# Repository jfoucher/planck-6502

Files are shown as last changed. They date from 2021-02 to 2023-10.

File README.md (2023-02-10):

# Planck computer

# An open hardware, extensible 65c02 based computer

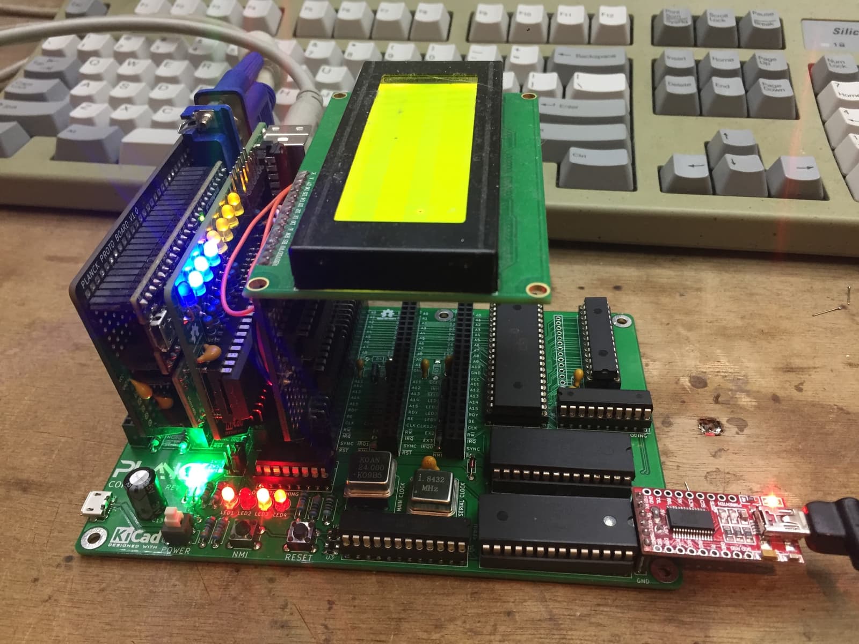
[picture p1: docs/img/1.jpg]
General view


This is a hobby computer based on the 65C02 processor. (I use 6502 and 65C02 interchangeably in this document, but [there are some differences](http://wilsonminesco.com/NMOS-CMOSdif/))

There are already many computers based on the 6502 processor, old ones such as as the Apple 1, Apple II, Commodore 64 and many more; and many more recent ones, from homebrew affairs on prototype board, to complete replicas of old systems.

The one that most closely resembles the Planck is probably the RC6502, itself based on the RC2014 (which uses a Z80 processor) with adaptations to the expansion bus to make it fit the 6502 processor.

Planck is a new variant on this type of expandable machines with a different set of tradeoffs.

### Contraints and requirements

The constraints for it's design were the following:

  - Minimum board size, 2 layers, as that is what is cheapest to have fabricated.
  - Easily extensible with for example:
    - Serial port
    - Parallel port
    - SPI / SPI65B port
    - PS/2 port for keyboard
    - Sound card
    - VGA out
    - SD card
    - LCD screen
  - Target clock speed of 10 to 12 MHz

## Some details

These requirements resulted in a computer based on a [motherboard](/Hardware/mainboard) hosting RAM, ROM and CPU and extension slots for expansion cards to plug into.

The [Planck hardware pages](/Hardware) explains more about the functionality of the motherboard and of each basic extension boards.

Of course, you can [design your own expansion boards](/Hardware/make) to make the computer do whatever **you** decide

### Expansion

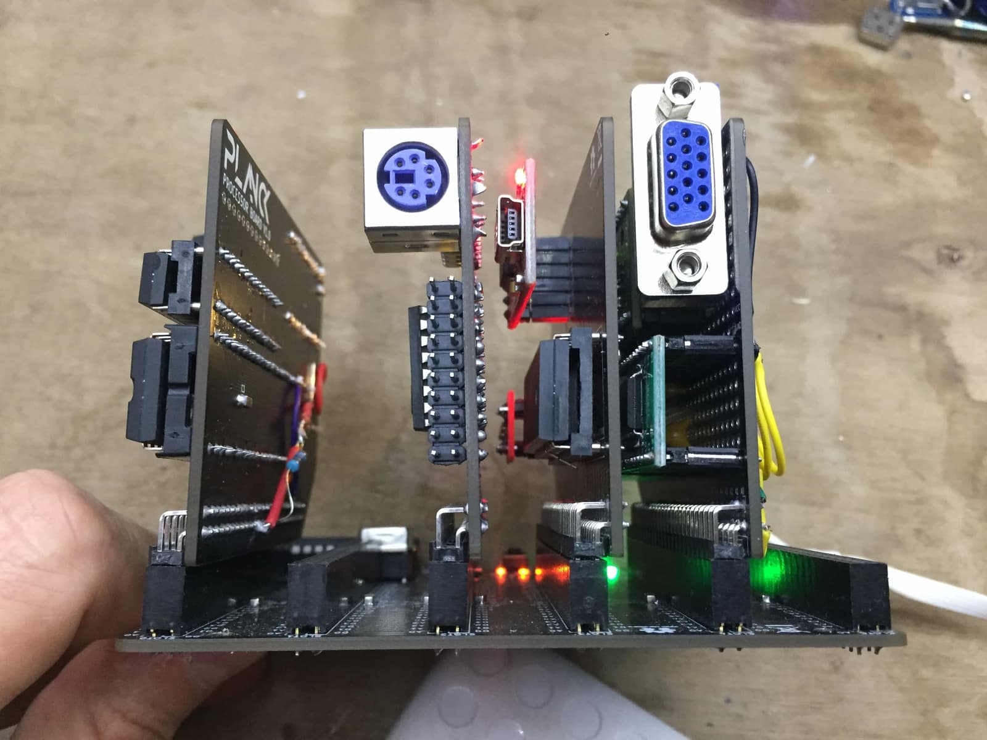
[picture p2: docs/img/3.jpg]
Expansion ports


Each expansion slot has a signal that should cause it to activate (<span style="text-decoration:overline">SEL1</span> to <span style="text-decoration:overline">SEL5</span> as detailed in the expansion bus description). The signals are generated by a programable logic chip on the motherboard (ATF22V10 or equivalent) according to the address that the processor is currently trying to access.

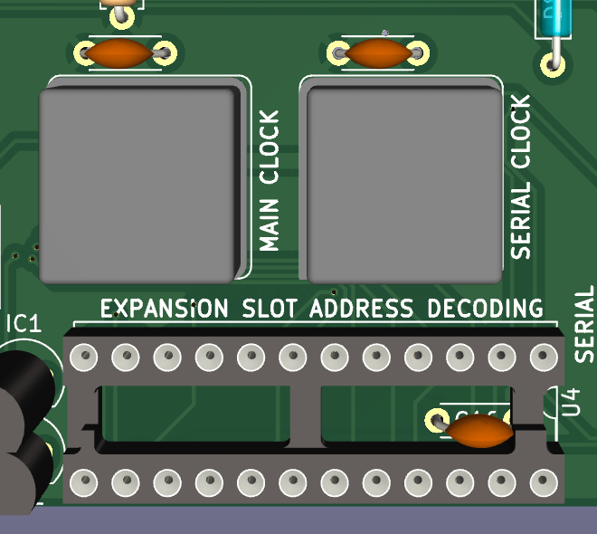
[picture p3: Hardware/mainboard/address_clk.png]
address decoding and clock


The main computer clock is generated on the motherboard by an oscillator. The clock signal goes through a binary counter, which makes it possible to slow down the clock when accessing slow devices.

The expansion slots are common 2x25 "Dupont" sockets on 2.54mm (100mil) centers and are very easy to obtain.

#### Expansion bus pinout

Most pins correspond to the pins of the same name on the CPU.

Below are the pins that are specific to the expansion bus:

| Pin number | Pin name | Description |
|----- |-----|---|
| 1 | A0 | Processor address bus pin 0 |
| 2 | D0 | Processor data bus pin 0 |
| 3 | A1 | Processor address bus pin 1 |
| 4 | D1 | Processor data bus pin 1 |
| 5 | A2 | Processor address bus pin 2 |
| 6 | D2 | Processor data bus pin 2 |
| 7 | A3 | Processor address bus pin 3 |
| 8 | D3 | Processor data bus pin 3 |
| 9 | A4 | Processor address bus pin 4 |
| 10 | D4 | Processor data bus pin 4 |
| 11 | A5 | Processor address bus pin 5 |
| 12 | D5 | Processor data bus pin 5 |
| 13 | A6 | Processor address bus pin 6 |
| 14 | D6 | Processor data bus pin 6 |
| 15 | A7 | Processor address bus pin 7 |
| 16 | D7 | Processor data bus pin 7 |
| 17 | A8 | Processor address bus pin 8 |
| 18 | EX0 | Extra pin for future use or for communication between expansion cards |
| 19 | A9 | Processor address bus pin 9 |
| 20 | EX1 | Extra pin for future use or for communication between expansion cards |
| 21 | A10 | Processor address bus pin 10 |
| 22 | <span style="text-decoration:overline">SLOW</span> | Used by slow peripherals to request a slower clock speed, active low. |
| 23 | GND | Ground |
| 24 | +5V | Positive voltage |
| 25 | +5V | Positive voltage |
| 26 | GND | Ground |
| 27 | A11 | Processor address bus pin 11 |
| 28 | <span style="text-decoration:overline">SSEL</span> | An expansion card is selected. Used by the processor card to disable it's built-in ram an ROM, active low |
| 29 | A12 | Processor address bus pin 12 |
| 30 | <span style="text-decoration:overline">INH</span> | When this is active (low), processor card RAM and ROM are disabled |
| 31 | A13 | Processor address bus pin 13 |
| 32 | <span style="text-decoration:overline">SLOT_SEL</span> | Used by the backplane to signal to expansion cards when they should activate, active low |
| 33 | A14 | Processor address bus pin 14 |
| 34 | LED1 | Connected to one of the backplane LEDs |
| 35 | A15 | Processor address bus pin 15 |
| 36 | LED2 | Connected to one of the backplane LEDs |
| 37 | RDY | Processor I/O pin. When low, the processor waits in it's curent state |
| 38 | LED3 | Connected to one of the backplane LEDs |
| 39 | BE | Processor input pin. when low the processor releases the bus |
| 40 | LED4 | Connected to one of the backplane LEDs |
| 41 | CLK | Main computer clock. Can be stretched or not depending on the state of the SLOW signal. |
| 42 | CLK_12M | Stable clock for e.g. VIA timers. **Not connected to slot 0** |
| 43 | R<span style="text-decoration:overline">W</span> | CPU read / write pin |
| 44 | EX4 | Extra signal 4. **Not connected to slot 0** |
| 45 | <span style="text-decoration:overline">IRQ</span> | This goes low when an interrupt request has occured, active low |
| 46 | EX5 | Extra signal 5. **Not connected to slot 0** |
| 47 | SYNC | CPU output. Indicates when the CPU is fetching an opcode |
| 48 | <span style="text-decoration:overline">SLOT_IRQ</span> | Used by expansion cards to signal an interrupt request to the processor board, active low  |
| 49 | <span style="text-decoration:overline">RESET</span> | Reset signal trigered by the button on the backplane, active low |
| 50 | <span style="text-decoration:overline">NMI</span> | non maskable interrupt signal trigered by the button on the backplane, active low |

The Planck 6502 computer is a single board computer that communicates over serial, or can be a standalone computer by adding expansion cards to one of the 6 slots present on the motherboard.

### Input / output
Also present on the motherboard are two buttons and 4 LEDs.

One button triggers a reset of the processor, and the other triggers an non-maskable interrupt (<span style="text-decoration:overline">NMI</span>) which can be thought of as a "soft" reset.

The leds are connected to the expansion bus, and so any board can control them. They can be used as a crude debug tool, to show the status of some processing, to try out a simple blink routine or to signal an error to the user.

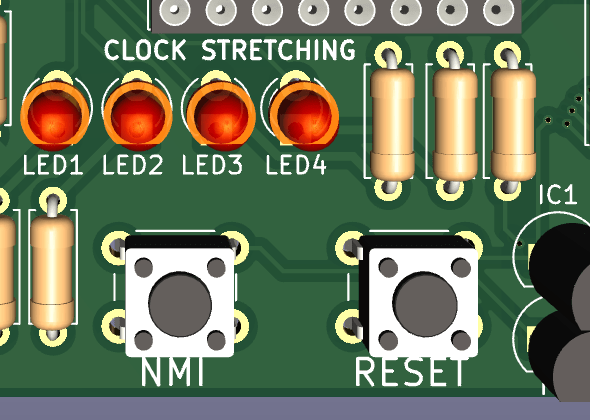
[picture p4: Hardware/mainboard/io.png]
input output


### Power delivery

The power to the board is provided by a barrel jack at the bottom left. There is a linear regulator on the board, so the power supply voltage can be anywhere from 7V to 12V, although with the latter a heatsink may be required on the regulator.

A power switch and a power LED are also provided on the backplane.

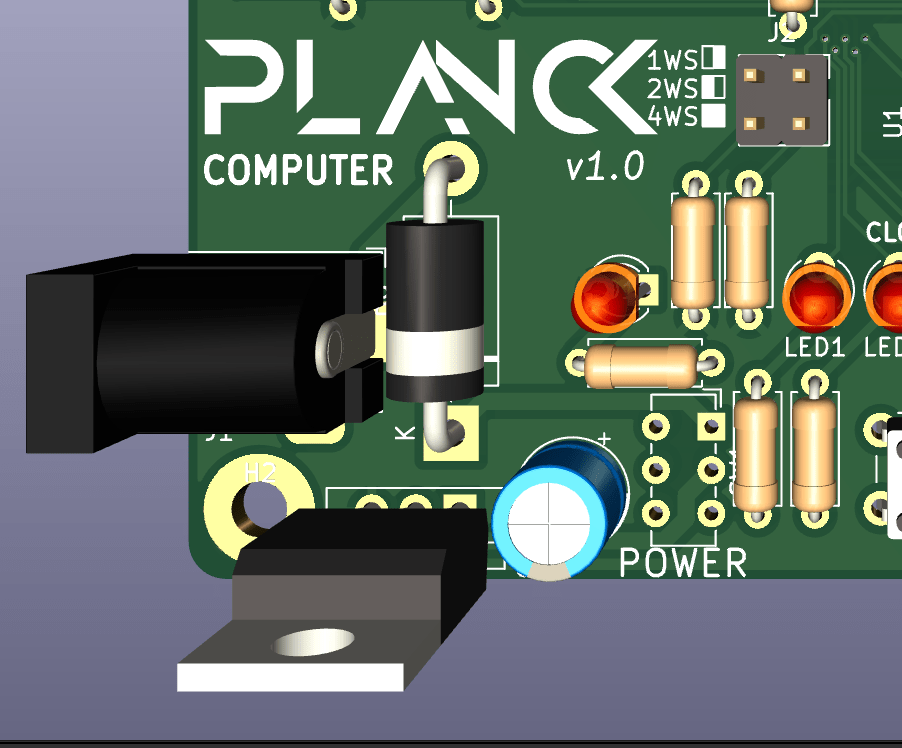
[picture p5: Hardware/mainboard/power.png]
Power


## Available expansion boards

### I/O board

[The IO board](Hardware/io_board) is based on a WDC65C22 chip and provides a keyboard PS/2 port, a parallel port and a 65SIB port (serial port similar to and compatible with SPI)

### Serial board

[The serial board](Hardware/serial_board) is based on a WDC65C51 chip and provides serial output through a TTL serial to USB adapter. When plugging the USB cable to your PC, it may be best to unplug the power from the backplane and let the computer be powered from your PC through the USB to serial adapter.

### OPL2 board

[A sound card](Hardware/opl2_board) based on the Yamaha OPL2 chip found in the original sound blaster card for example.

### LCD board

[This board](Hardware/lcd_board) allow a 20x04 LCD to be connected to the computer for text output.

<br />This documentation is licensed under a <a rel="license" href="http://creativecommons.org/licenses/by-sa/4.0/">Creative Commons Attribution-ShareAlike 4.0 International License</a>.

CERN-OHL-1.2 GPL-3.0-or-later CC-BY-SA-4.0

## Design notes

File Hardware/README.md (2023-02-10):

## Hardware

In this folder you will find all the schematics and board layouts in [Kicad](https://www.kicad.org/) format.

You probably want to take a look at the [main board](mainboard/) first as that explains the basic architecture of the computer.

<br />This documentation is licensed under a <a rel="license" href="http://creativecommons.org/licenses/by-sa/4.0/">Creative Commons Attribution-ShareAlike 4.0 International License</a>.

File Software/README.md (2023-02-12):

## Planck 6502 software

This folder contains the software for the Planck computer.
The `drivers`folder contains assembly drivers for the hardware.

The `fos` folder contains a modified version of [TaliForth 2](https://github.com/scotws/TaliForth2) with a platorm file made for the planck. I ported TaliForth code to [CA65](https://cc65.github.io/doc/ca65.html) because I find it more flexible.

Finally the PAL directory contains Wincupl code to program the programmable logic chips on the backplane and on the processor board.

<br />This documentation is licensed under a <a rel="license" href="http://creativecommons.org/licenses/by-sa/4.0/">Creative Commons Attribution-ShareAlike 4.0 International License</a>.

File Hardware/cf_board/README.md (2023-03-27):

## Compact Flash board

This board allows adding one Compact Flash (CF) card to the Planck computer. This gives mass storage capabilities to the computer.

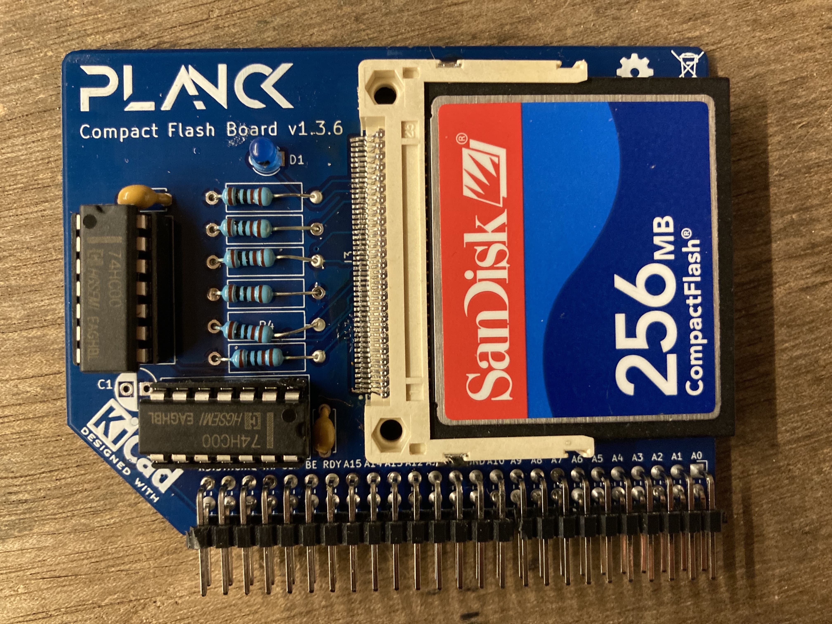
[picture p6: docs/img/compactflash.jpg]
Top view of the CompactFlash board


The file system is not complete yet, but will probably be FAT16 to allow interoperability with PCs

You will be able to save and load files. 

It will be possible to load forth words and assembly code from the compact flash card.

3D render

You can [download the schematic](https://planck6502.com/fabrication/cf_board-schematic.pdf) and the [gerber files](https://planck6502.com/fabrication/cf_board-zip.zip)

[Documentation](https://planck6502.com/Hardware/cf/)

<br />This documentation is licensed under a <a rel="license" href="http://creativecommons.org/licenses/by-sa/4.0/">Creative Commons Attribution-ShareAlike 4.0 International License</a>.

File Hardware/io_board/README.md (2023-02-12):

## Keyboard and IO board

This board is based on a 6522 chip.

### Features

- One PS/2 keyboard port
- One SPI port
- One parallel port

### Details

PORTA as well as CA1 and CA2 are brought out to a pin header on top of the board.

The PS/2 port uses CB2 for the clock and PORTB bit 7 as the data line.

There is also a modified [65SIB port](http://forum.6502.org/viewtopic.php?t=1064&start=105) on the back. The +12V have been replaced by +5V lines because there is not 12V on the board. Similary the -12V line is left unconnected.

This port allows 7 SPI devices to be connected to the IO board and uses PORTB pins PB0 to PB2 to select one of 7 devices (through a 74HC137)
PB3 is the SPI clock, PB4 is MISO, PB5 is MOSI, PB6 is the <span style="text-decoration:overline">CONF</span> signal and PB7 is used to latch the selected device into the 74HC137. The latching allows for pins PB0 to PB2 to do other things while an SPI device is being accessed at the cost of having to be careful not to make it interfere with the ps/2 keyboard.

This is what the board look like at the moment:

Top view

3D render

You can [download the schematic](https://planck6502.com/fabrication/io_board-schematic.pdf) and the [gerber files](https://planck6502.com/fabrication/io_board-zip.zip)

[Documentation](https://planck6502.com/Hardware/io/)

<br />This documentation is licensed under a <a rel="license" href="http://creativecommons.org/licenses/by-sa/4.0/">Creative Commons Attribution-ShareAlike 4.0 International License</a>.

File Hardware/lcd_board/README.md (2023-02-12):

## Planck 6502 LCD board

This board allows adding a HD44780 based LCD to the Planck computer.

This is what the board looks like at the moment:

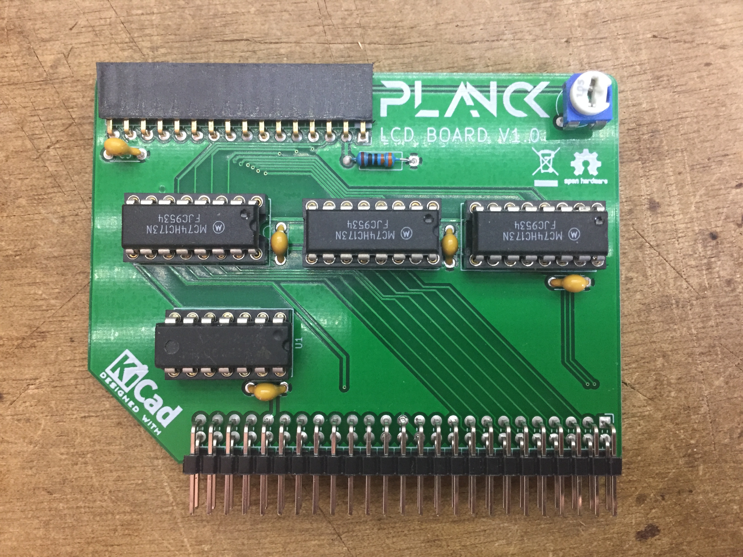
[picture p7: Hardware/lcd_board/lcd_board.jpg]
Final board


3D render

You can [download the schematic](https://planck6502.com/fabrication/lcd_board-schematic.pdf) and the [gerber files](https://planck6502.com/fabrication/lcd_board-zip.zip)

[Documentation](https://planck6502.com/Hardware/lcd/)

<br />This documentation is licensed under a <a rel="license" href="http://creativecommons.org/licenses/by-sa/4.0/">Creative Commons Attribution-ShareAlike 4.0 International License</a>.

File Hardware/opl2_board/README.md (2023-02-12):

## Planck 6502 sound card

This is a sound card based on the YM3892 OPL2 sound chip.

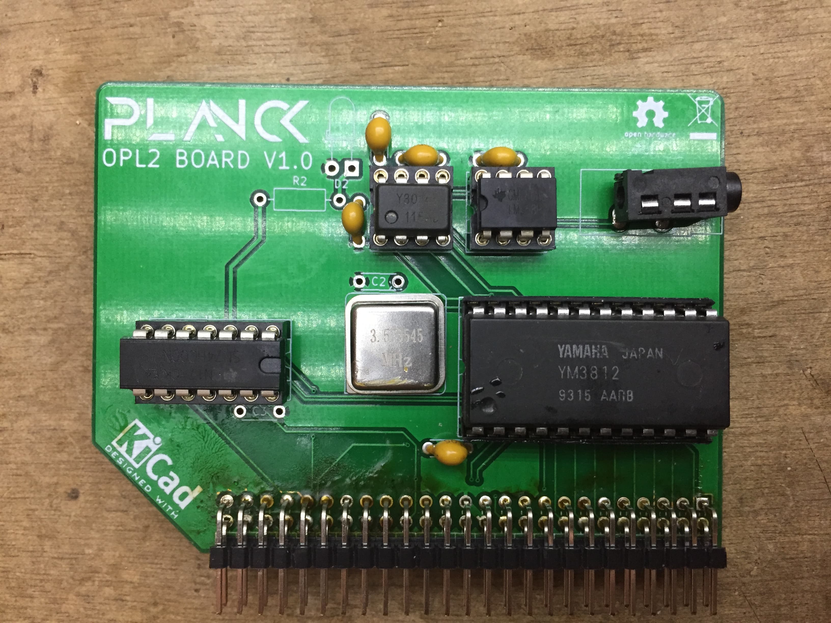
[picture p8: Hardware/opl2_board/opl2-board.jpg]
OPL2 board


3D render

You can [download the schematic](https://planck6502.com/fabrication/opl2_board-schematic.pdf) and the [gerber files](https://planck6502.com/fabrication/opl2_board-zip.zip)

[Documentation](https://planck6502.com/Hardware/opl2/)

<br />This documentation is licensed under a <a rel="license" href="http://creativecommons.org/licenses/by-sa/4.0/">Creative Commons Attribution-ShareAlike 4.0 International License</a>.

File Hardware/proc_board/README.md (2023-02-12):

## Planck CPU board

# Deprecated. Please use the [mainboard](../mainboard/) instead

This is the CPU board for the Planck 6502 based computer. It contains 32K of ram and 32K of rom.

The RAM and ROM can be inhibited by setting the <span style="text-decoration:overline">INH</span> signal low.

It is then the responsibility of that card to respond to the whole address range (execpt the one where expansion cards are active) to provide required functionality such as reset vectors, zero page, etc...

If the <span style="text-decoration:overline">SSEL</span> signal is low (one of the slots is active), both the RAM and the ROM will be offline.

The board can accept either a narrow or wide DIP28 RAM chip.

This is what the board looks like

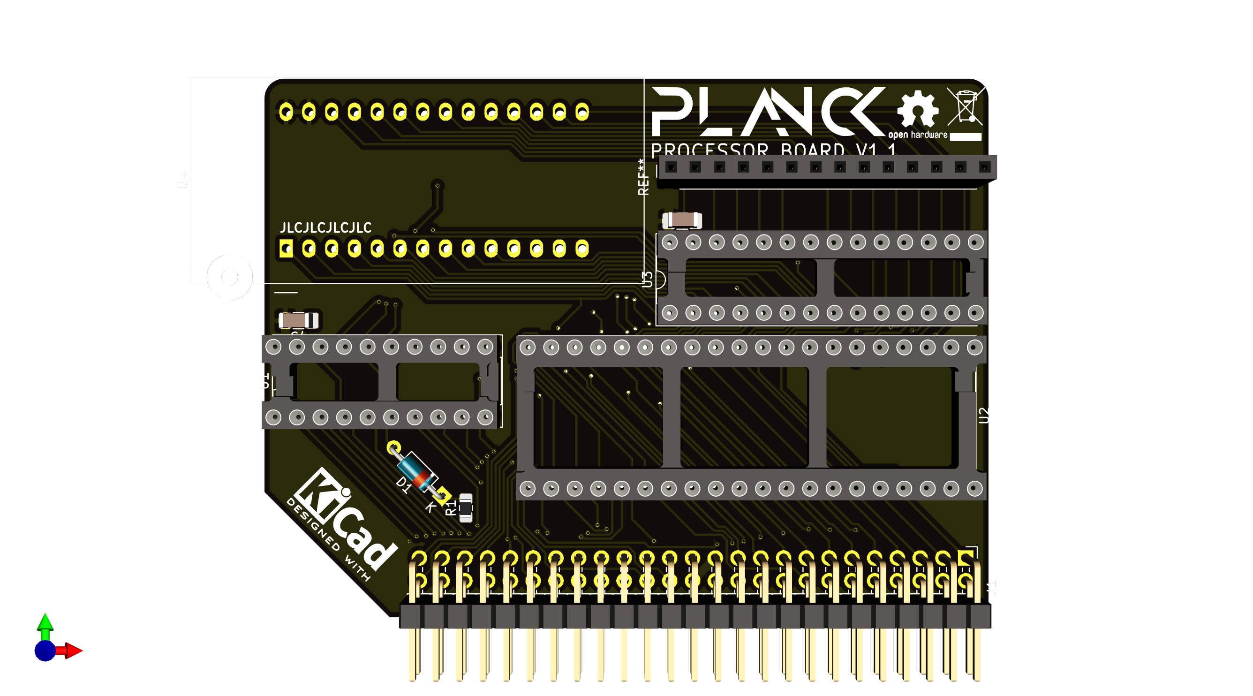
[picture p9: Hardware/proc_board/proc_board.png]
CPU board 3D view


<br />This documentation is licensed under a <a rel="license" href="http://creativecommons.org/licenses/by-sa/4.0/">Creative Commons Attribution-ShareAlike 4.0 International License</a>.

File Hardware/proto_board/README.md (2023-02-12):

## Planck 6502 expansion board prototype

This board allows you to prototype any thing for the Planck computer

This is what the board looks like at the moment

3D render

You can [download the schematic](https://planck6502.com/fabrication/proto_board-schematic.pdf) and the [gerber files](https://planck6502.com/fabrication/proto_board-zip.zip)

[Documentation](https://planck6502.com/Hardware/proto/)

<br />This documentation is licensed under a <a rel="license" href="http://creativecommons.org/licenses/by-sa/4.0/">Creative Commons Attribution-ShareAlike 4.0 International License</a>.

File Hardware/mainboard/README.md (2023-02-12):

## Planck computer

This is a complete computer based on the Planck 6502 backplane.

It provides a 65c02 cPU, 32k of RAM, 32k of ROM and a serial port, as well as 6 expansion slots.

The board exceeds the original size specification of the original project (100 x 150mm instead of 100 x 100mm) but it seems that the cost will be similar (one more expensive board replaces 3 cheaper boards) as well as being more practical for some applications.

This computer can run absolutely stand alone when connected via the serial port. It can also accommodate 2 more expansion cards compared to the original backplane.

Here is a 3D view of the board:

3D render

You can [download the schematic](https://planck6502.com/fabrication/mainboard-schematic.pdf) and the [gerber files](https://planck6502.com/fabrication/mainboard-zip.zip)

[Documentation](https://planck6502.com/Hardware/io/)

<br />This documentation is licensed under a <a rel="license" href="http://creativecommons.org/licenses/by-sa/4.0/">Creative Commons Attribution-ShareAlike 4.0 International License</a>.

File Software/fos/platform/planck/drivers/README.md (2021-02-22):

## Drivers

This folder contains assembly drivers for the planck computer.
They are divided into a number of files by functionality.
Most of them require specific hardware to be present to function.

They also have predefined hardware adresses, meaning that each specific card is meant to go in a specific slot for these drivers to work.
However the base address is set in the `.inc` files, so should be very easy to change when a card is moved from one slot to another.

<br />This documentation is licensed under a <a rel="license" href="http://creativecommons.org/licenses/by-sa/4.0/">Creative Commons Attribution-ShareAlike 4.0 International License</a>.

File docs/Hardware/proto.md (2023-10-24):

---
layout: board
short_title: Proto board
title: Prototyping board
status: prod
design_files: https://gitlab.com/planck-6502/planck-6502/-/tree/main/Hardware/proto_board
order: 100
gerbers: https://planck6502.com/fabrication/proto_board-zip.zip
schematic: https://planck6502.com/fabrication/proto_board-schematic.pdf
html_bom: https://planck6502.com/fabrication/proto_board-bom.html
csv_bom: https://planck6502.com/fabrication/proto_board-bom.csv
---

This is a prototyping board. It has a header to connect it to the backplane, power delivery, and the rest is up to you!

For example here is my prototype of the [OPL2 sound card](/Hardware/opl2)

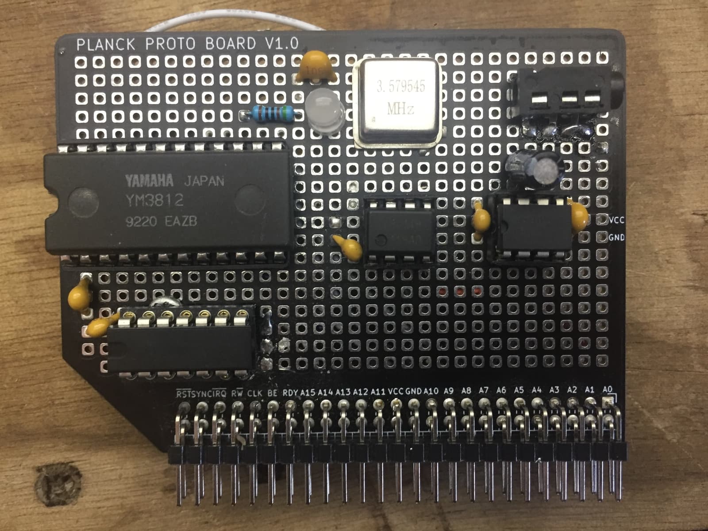
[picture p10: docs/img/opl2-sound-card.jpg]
Planck prototype board for LCD


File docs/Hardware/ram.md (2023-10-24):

---
layout: board
title: Banked RAM board
short_title: RAM board
status: dev
design_files: https://gitlab.com/planck-6502/planck-6502/-/tree/main/Hardware/ram_board
order: 60
gerbers: https://planck6502.com/fabrication/ram_board-zip.zip
schematic: https://planck6502.com/fabrication/ram_board-schematic.pdf
html_bom: https://planck6502.com/fabrication/ram_board-bom.html
csv_bom: https://planck6502.com/fabrication/ram_board-bom.csv
---

## This is a banked RAM board for the Planck 6502 computer.

3D View

When active, it gives access to a bank or RAM in the $8000-$BFFF address space.

To activate, store a byte with it's high bit set to the first register of the slot where it is placed.

For example

```nesasm
lda #$80
sta $FFD0
```

will activate bank 0

There are 32 banks. You can choose which one is active by setting the first 5 bits of the data when storing to the first register. There is no way to get the currently active bank.

When the RAM card is active, it will respond to requests in the $8000 to $BFFF range instead of the ROM

```nesasm
lda #$8E
sta $FFD0
```

will activate the 14th bank

Setting the high bit to 0 will deactivate the banked RAM

For example the following code will deactivate the banked RAM and restore the ROM :

```nesasm
lda #0
sta $FFD0
```

To use the RAM expansion from forth, two words are provided for convenience the first one `expad` sets the expansion card address.

For example, if it placed in slot 0, run the following:

```forth
hex ff80 expad
```

then to activate it and change banks, use the following:

```forth
hex
80 bank \ Activates bank 0
81 bank \ Activates bank 1
82 bank \ Activates bank 2
9F bank \ Activates bank 31

0 bank  \ Deactivates RAM expansion and restores ROM
```

## Slot placement

You can place the card in any slot, as long as your code knows where it is.

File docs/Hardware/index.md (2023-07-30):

---
layout: page
title: Planck 6502 hardware
---

The Planck hardware is organized around a motherboard that hosts the CPU and RAM, ROM and serial input / output as well as [clock generation](#clock-generation), [board connection](#board-connection), [expansion slot activation](#expansion-slot-activation) and [basic user IO](#basic-user-io).

<!--
<div style="float:right">
<form target="paypal" action="https://www.paypal.com/cgi-bin/webscr" method="post">
<input type="hidden" name="cmd" value="_s-xclick">
<input type="hidden" name="hosted_button_id" value="WNF3GUCN92CT6">
<table style="border:none"  cellpadding="0">
<tr>
<td style="border:none;vertical-align:middle">
<input type="hidden" name="on0" value="Include ICs ?">
<select name="os0">
	<option value="No ICs">No ICs €69,00 EUR</option>
	<option value="All ICs">All ICs €99,00 EUR</option>
</select>
</td>
<td style="border:none;vertical-align:middle"><input type="hidden" name="currency_code" value="EUR">
<input type="image" src="https://www.paypalobjects.com/en_US/i/btn/btn_cart_LG.gif" border="0" name="submit" alt="PayPal - The safer, easier way to pay online!">
<img alt="" border="0" src="https://www.paypalobjects.com/en_US/i/scr/pixel.gif" width="1" height="1"></td>
</tr>
</table>
</form>
</div>
-->

## The computer

[Design files](https://gitlab.com/planck-6502/planck-6502/-/tree/main/Hardware/cpu_backplane)

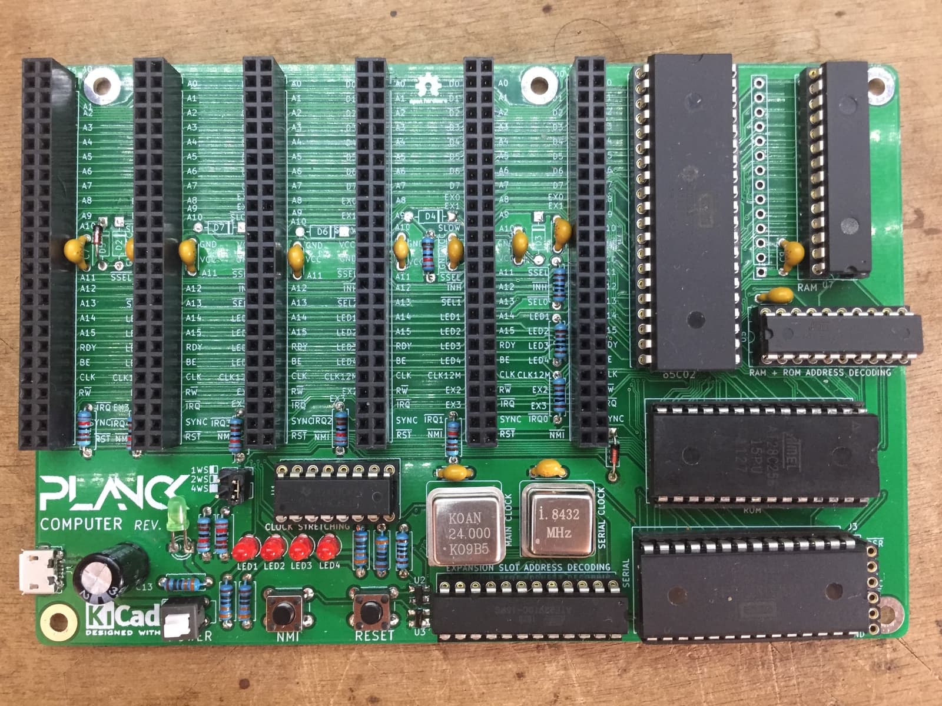
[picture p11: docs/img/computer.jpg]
Computer board fully populated


The computer board consists of a 65C02 CPU, 32K of RAM, 32K of ROM, a 6551 ACIA for serial communication, 6 expansion slots for addon boards, as well as the following:

### Clock generation

The clock generation starts with an oscillator. This oscillator should be at twice the target frequency since it is divided by two by a [74HC161 binary counter](https://assets.nexperia.com/documents/data-sheet/74HC161.pdf)

This counter makes possible the clock stretching that will be required by slow peripherals, or indeed any ROM if you run your computer fast enough.

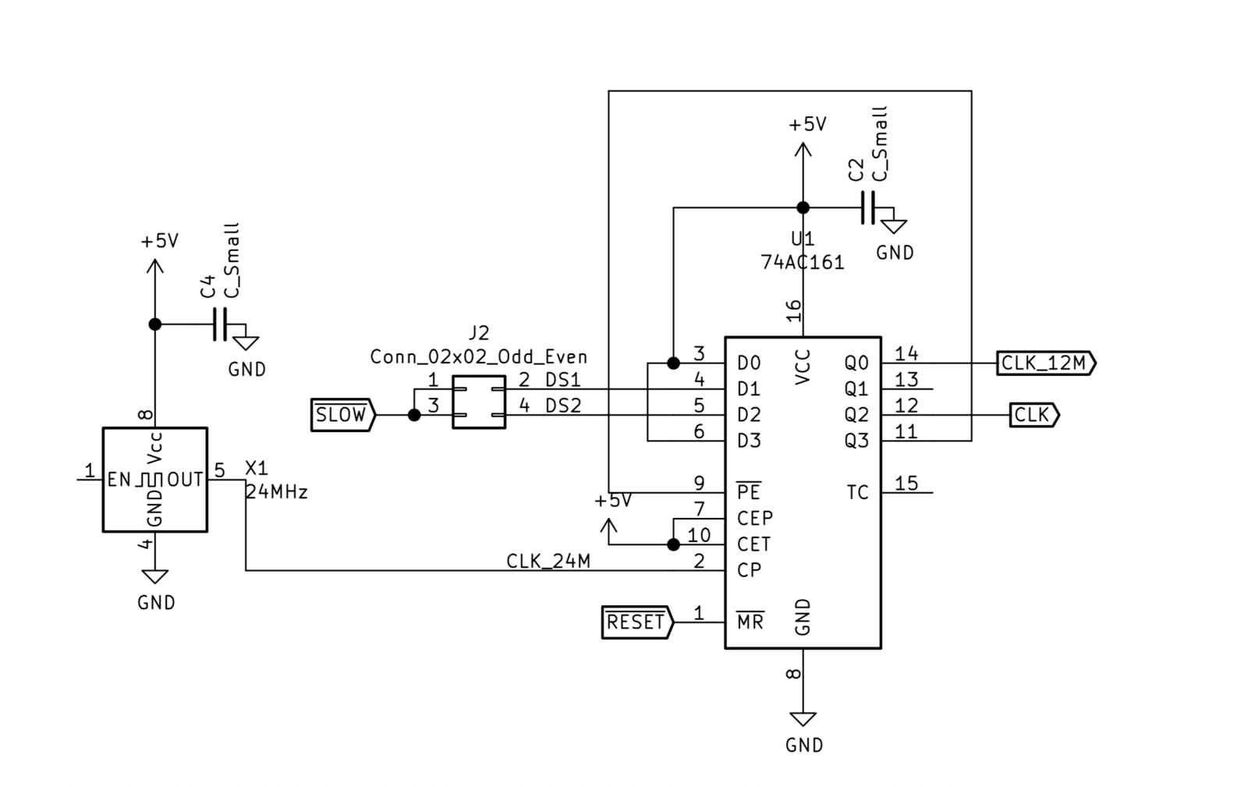
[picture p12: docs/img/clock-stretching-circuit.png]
Planck 6502 clock stretching circuit


Let me explain this schematic: 
The 24Mhz output from the oscillator goes to the clock input of the binary counter.
The Q0 output of the counter changes at every positive clock edge, so it is a square wave of half the frequency of the oscillator clock. This signal is fed to the expansion bus under the name CLK_12M. It is thus a non stretched clock that is used for things that require precise and consistent timings, such as VIA timers for example.
Q3 is low when the counter is less than 8 and causes the counter to load its current count from the input.
By default if the <span class="overline">SLOW</span> signal is high, then the counter will immediately load 15 and resume counting, which will take it back to zero, which will trigger the load again.

It that case the counter oscillates between 15 (all outputs high) and 0 (all outputs low) which causes CLK and CLK_12M to oscillate at the same frequency.

However, if the <span class="overline">SLOW</span> signal is asserted (low) than a number less than 15 will be loaded in the counter, which means the Q2 (CLK signal) will toggle at a reduced frequency.

So this simple circuit generates two clock signals : one that is slow enough for the currently addressed peripheral, and one that is stable for timing sensitive peripherals. This also means that any timing sensitive peripherals MUST be able to run at the main (CLK_12M) frequency.

### Board connection

One of the purposes of the motherboard is to connect all daughter boards together. It does this by means of an extension bus connector based on a 2.54mm 2x25 pins socket. These connectors are cheap, reliable and easy to obtain. The female connector is placed on the backplane and a right angle male connector on each expansion board.

Most pins on this extension consist of the 65C02 signals, such as 16 address lines, 8 data lines, and a smattering of control lines. The complete bus pinout is detailed below:

| Pin number | Pin name | Description |
|---|-----|---|
| 1 | A0 | Processor address bus pin 0 |
| 2 | D0 | Processor data bus pin 0 |
| 3 | A1 | Processor address bus pin 1 |
| 4 | D1 | Processor data bus pin 1 |
| 5 | A2 | Processor address bus pin 2 |
| 6 | D2 | Processor data bus pin 2 |
| 7 | A3 | Processor address bus pin 3 |
| 8 | D3 | Processor data bus pin 3 |
| 9 | A4 | Processor address bus pin 4 |
| 10 | D4 | Processor data bus pin 4 |
| 11 | A5 | Processor address bus pin 5 |
| 12 | D5 | Processor data bus pin 5 |
| 13 | A6 | Processor address bus pin 6 |
| 14 | D6 | Processor data bus pin 6 |
| 15 | A7 | Processor address bus pin 7 |
| 16 | D7 | Processor data bus pin 7 |
| 17 | A8 | Processor address bus pin 8 |
| 18 | EX0 | Extra pin for future use or for communication between expansion cards |
| 19 | A9 | Processor address bus pin 9 |
| 20 | EX1 | Extra pin for future use or for communication between expansion cards |
| 21 | A10 | Processor address bus pin 10 |
| 22 | <span class="overline">SLOW</span> | Used by slow peripherals to request a slower clock speed, active low. |
| 23 | GND | Ground |
| 24 | +5V | Positive voltage |
| 25 | +5V | Positive voltage |
| 26 | GND | Ground |
| 27 | A11 | Processor address bus pin 11 |
| 28 | <span class="overline">SSEL</span> | An expansion card is selected. Used by the processor card to disable it's built-in ram and ROM, active low |
| 29 | A12 | Processor address bus pin 12 |
| 30 | <span class="overline">INH</span> | When this is active (low), processor card RAM and ROM are disabled |
| 31 | A13 | Processor address bus pin 13 |
| 32 | <span class="overline">SLOT_SEL</span> | Used by the backplane to signal to expansion cards when they should activate, active low |
| 33 | A14 | Processor address bus pin 14 |
| 34 | LED1 | Connected to one of the backplane LEDs |
| 35 | A15 | Processor address bus pin 15 |
| 36 | LED2 | Connected to one of the backplane LEDs |
| 37 | RDY | Processor I/O pin. When low, the processor waits in its curent state |
| 38 | LED3 | Connected to one of the backplane LEDs |
| 39 | BE | Processor input pin. when low the processor releases the bus |
| 40 | LED4 | Connected to one of the backplane LEDs |
| 41 | CLK | Main computer clock. Can be stretched or not depending on the state of the <span class="overline">SLOW</span> signal. |
| 42 | CLK_12M | Stable clock for e.g. VIA timers. |
| 43 | R<span class="overline">W</span> | CPU read / write pin |
| 44 | EX2 | Extra signal 2.  |
| 45 | <span class="overline">IRQ</span> | This goes low when an interrupt request has occured, active low |
| 46 | EX3 | Extra signal 3.  |
| 47 | SYNC | CPU output. Indicates when the CPU is fetching an opcode |
| 48 | <span class="overline">SLOT_IRQ</span> | Used by expansion cards to signal an interrupt request to the processor, active low  |
| 49 | <span class="overline">RESET</span> | Reset signal trigered by the button on the backplane, active low |
| 50 | <span class="overline">NMI</span> | non maskable interrupt signal trigered by the button on the backplane, active low |

[View the pinout on pinoutguide.com](https://pinoutguide.com/Electronics/Planck_6502_expansion_bus_pinout.shtml)

### Expansion slot activation

The 65C02 CPU works with memory mapped input/output. This means that the CPU does not care what device is responding to what address range. To it, when it asks for data from a certain address, it's all the same whether that data comes from RAM, ROM, a temperature sensor or whetever else.
This means that we need some external logic to activate certain devices when the CPU requests data from an address where we want that device to take control.

In our case, the motherboard has some logic that tells one of the expansion slots to activate when a certain address range is requested by the CPU. This address decoding, as it is called is taken care of by an ATF22V10, a [programmable logic chip](https://en.wikipedia.org/wiki/Programmable_logic_device) that can be thought of as an ancestor to FPGAs.

This functionality could also be built from discrete logic chips, but using a PLD chip does three things for us:

- First it saves board space. The functionality this single chip provides would need at least two or three chips to replicate with discrete logic
- Secondly, it speeds up the response time. Each time a signal passes through a chip, it incurs a slight delay. So the fewer chips are on the path, the faster our computer can run.
- Finally, it allows us to reprogram it to easily change the memory map of the system.

In the default case, slot 0 responds in the address range `$FF80` to `$FF8F`, slot 1 to `$FF90` to `$FF9F`, etc until slot 5 at `$FFD0` to `$FFDF`. This address decoding can be reconfigured by simply reprogramming the PLD, giving quite a lot of flexibility to the system.

You could for example assign a whole page (256 bytes) or more to each expansion slot, allowing the extension cards to have their driver in an on-board ROM.

Here is the default expansion memory map in table form

|-------------------------------------------------------------------|
|  START ADDRESS    |   END ADDRESS       |     DESCRIPTION         |
|-------------------------------------------------------------------|
|  0xFF80           |   0xFF8F            | SLOT0 Selected          |
|  0xFF90           |   0xFF9F            | SLOT1 Selected          |
|  0xFFA0           |   0xFFAF            | SLOT2 Selected          |
|  0xFFB0           |   0xFFBF            | SLOT3 Selected          |
|  0xFFC0           |   0xFFCF            | SLOT4 Selected          |
|  0xFFD0           |   0xFFDF            | SLOT5 Selected          |
|  0xFFE0           |   0xFFEF            | SERIAL Selected         |
|-------------------------------------------------------------------|

### Basic user IO

The computer provides some basic user input and output in the form of two buttons and 4 leds.

The two buttons are a reset button and an NMI (non maskable interrupt) buttons. The reset button triggers a hard reset of the processor, whereas the NMI button provides a non maskable interrupt to the code that can be handled (for example) as a soft reset.

The 4 LEDs are connected to pins on the expansion bus, and can thus be driven by any card that wants to signal something to the user. You have to be mindful in your code not to drive a led low while another card is trying to drive it high, as that would cause high current to flow into / from your peripherals.

Finally, there is a power plug (Barrel jack), a power switch and a power LED.

If you want to build this computer, please see the [building the computer](build) page to get more details about what to expect.
<!-- 
<script async src="https://js.stripe.com/v3/pricing-table.js"></script>
<stripe-pricing-table pricing-table-id="prctbl_1NZeIWDtAuPfKnt3aQTV31Hu"
publishable-key="pk_live_51LNKdxDtAuPfKnt3hZwpiwcGTgssR7GG2jbIRn4DPIOubydZ5rS7yfBJlkI4AbDmIXCDKMLSh93dPcZv4k3fWn4f00itJp3VWr">
</stripe-pricing-table> -->

<!--
## Buy it now with paypal

Currently out of stock, sorry.

<div>
<form target="paypal" action="https://www.paypal.com/cgi-bin/webscr" method="post">
<input type="hidden" name="cmd" value="_s-xclick">
<input type="hidden" name="hosted_button_id" value="WNF3GUCN92CT6">
<table>
<tr><td><input type="hidden" name="on0" value="Include ICs ?">Include ICs ?</td></tr><tr><td><select name="os0">
	<option value="No ICs">No ICs €89,00 EUR</option>
	<option value="All ICs">All ICs €119,00 EUR</option>
</select> </td></tr>
</table>
<input type="hidden" name="currency_code" value="EUR">
<input type="image" src="https://www.paypalobjects.com/en_US/i/btn/btn_cart_LG.gif" border="0" name="submit" alt="PayPal - The safer, easier way to pay online!">
<img alt="" border="0" src="https://www.paypalobjects.com/en_US/i/scr/pixel.gif" width="1" height="1">
</form>

</div>

## Buy it on Tindie

Currently out of stock, sorry.

<a href="https://www.tindie.com/products/24831/"><img src="https://d2ss6ovg47m0r5.cloudfront.net/badges/tindie-larges.png" alt="Buy the Planck 6502 computer on Tindie" width="200" height="104"></a>
-->

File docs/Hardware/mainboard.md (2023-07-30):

---
layout: board
title: Main board
order: 30
status: prod
design_files: https://gitlab.com/planck-6502/planck-6502/-/tree/main/Hardware/mainboard
gerbers: https://planck6502.com/fabrication/mainboard-zip.zip
schematic: https://planck6502.com/fabrication/mainboard-schematic.pdf
html_bom: https://planck6502.com/fabrication/mainboard-bom.html
csv_bom: https://planck6502.com/fabrication/mainboard-bom.csv
---

### VERSION 1.3 DOES NOT WORK. DO NOT USE!!

The power supply is wrong. Other than that it works fine

The Planck computer is an extensible single board computer. Everything need for the computer to work is on the mainboard (Basic IO, ROM, RAM, CPU). It can be extended with up to 6 cards to make it into exactly the computer you want.

## The main board

[Design files](https://gitlab.com/planck-6502/planck-6502/-/tree/main/Hardware/mainboard)

Main board fully populated

Here are some details about the various subsystems on the main board.

### Clock generation
The clock generation starts with an oscillator. This oscillator should be at twice the target frequency since it is divided by two by a [74HC161 binary counter](https://assets.nexperia.com/documents/data-sheet/74HC161.pdf)

This counter makes possible the clock stretching that will be required by slow peripherals, or indeed any ROM if you run your computer fast enough.

Planck 6502 clock stretching circuit

Let me explain this schematic: 
The 24Mhz output from the oscillator goes to the clock input of the binary counter.
The Q0 output of the counter changes at every positive clock edge, so it is a square wave of half the frequency of the oscillator clock. This signal is fed to the expansion bus under the name CLK_12M. It is thus a non stretched clock that is used for things that require precises and consistent timings, such as VIA timers for example.
Q3 is low when the counter is less than 8 and causes the counter to load its current count from the input.
By default if the <span class="overline">SLOW</span> signal is high, then the counter will immediately load 15 and resume counting, which will take it back to zero, which will trigger the load again.

It that case the counter oscillates between 15 (all output high) and 0 (all outputs low) which causes CLK and CLK_12M to oscillate at the same frequency.

However, if the <span class="overline">SLOW</span> signal is asserted (low) than a number less than 15 will be loaded in the counter, which mean the Q2 (CLK signal) will toggle at a reduced frequency.

So this simple circuit generates two clock signal : one that is slow enough for the currently addressed peripheral, and one that is stable for timing sensitive peripherals. This also means that any timing sensitive peripherals MUST be able to run at the main (CLK) frequency.

### Board connection

The Planck computer can be easily extended. It does this by means of an extension bus connector based on a 2.54mm 2x25 pins socket. These connectors are cheap, reliable and easy to obtain. The female connector is placed on the main board and a right angle male connector on each expansion board.

Most pins on this extension consist of the 65C02 signals, such as 16 address lines, 8 data lines, and a smattering of control lines. The complete bus pinout is detailed below:

| Pin number | Pin name | Description |
|---|-----|---|
| 1 | A0 | Processor address bus pin 0 |
| 2 | D0 | Processor data bus pin 0 |
| 3 | A1 | Processor address bus pin 1 |
| 4 | D1 | Processor data bus pin 1 |
| 5 | A2 | Processor address bus pin 2 |
| 6 | D2 | Processor data bus pin 2 |
| 7 | A3 | Processor address bus pin 3 |
| 8 | D3 | Processor data bus pin 3 |
| 9 | A4 | Processor address bus pin 4 |
| 10 | D4 | Processor data bus pin 4 |
| 11 | A5 | Processor address bus pin 5 |
| 12 | D5 | Processor data bus pin 5 |
| 13 | A6 | Processor address bus pin 6 |
| 14 | D6 | Processor data bus pin 6 |
| 15 | A7 | Processor address bus pin 7 |
| 16 | D7 | Processor data bus pin 7 |
| 17 | A8 | Processor address bus pin 8 |
| 18 | EX0 | Extra pin for future use or for communication between expansion cards |
| 19 | A9 | Processor address bus pin 9 |
| 20 | EX1 | Extra pin for future use or for communication between expansion cards |
| 21 | A10 | Processor address bus pin 10 |
| 22 | <span class="overline">SLOW</span> | Used by slow peripherals to request a slower clock speed, active low. |
| 23 | GND | Ground |
| 24 | +5V | Positive voltage |
| 25 | +5V | Positive voltage |
| 26 | GND | Ground |
| 27 | A11 | Processor address bus pin 11 |
| 28 | <span class="overline">SSEL</span> | An expansion card is selected. Used by the processor card to disable it's built-in ram and ROM, active low |
| 29 | A12 | Processor address bus pin 12 |
| 30 | <span class="overline">INH</span> | When this is active (low), processor card RAM and ROM are disabled |
| 31 | A13 | Processor address bus pin 13 |
| 32 | <span class="overline">SLOT_SEL</span> | Used by the main board to signal to expansion cards when they should activate, active low |
| 33 | A14 | Processor address bus pin 14 |
| 34 | LED1 | Connected to one of the backplane LEDs |
| 35 | A15 | Processor address bus pin 15 |
| 36 | LED2 | Connected to one of the backplane LEDs |
| 37 | RDY | Processor I/O pin. When low, the processor waits in its curent state |
| 38 | LED3 | Connected to one of the backplane LEDs |
| 39 | BE | Processor input pin. when low the processor releases the bus |
| 40 | LED4 | Connected to one of the backplane LEDs |
| 41 | CLK | Main computer clock. Can be stretched or not depending on the state of the <span class="overline">SLOW</span> signal. |
| 42 | CLK_12M | Stable clock for e.g. VIA timers. **Not connected to slot 0** |
| 43 | R<span class="overline">W</span> | CPU read / write pin |
| 44 | EX2 | Extra signal 2. **Not connected to slot 0** |
| 45 | <span class="overline">IRQ</span> | This goes low when an interrupt request has occured, active low |
| 46 | EX3 | Extra signal 3. **Not connected to slot 0** |
| 47 | SYNC | CPU output. Indicates when the CPU is fetching an opcode |
| 48 | <span class="overline">SLOT_IRQ</span> | Used by expansion cards to signal an interrupt request to the processor board, active low  |
| 49 | <span class="overline">RESET</span> | Reset signal trigered by the button on the backplane, active low |
| 50 | <span class="overline">NMI</span> | non maskable interrupt signal trigered by the button on the backplane, active low |

### Expansion slot activation

The 65C02 works with memory mapped input/output. This means that the CPU does not care what device is responding to what address range. To it, when it asks for data from a certain address, it's all the same whether that data comes from RAM, ROM, a temperature sensor or whetever else.
This means that we need some external logic to activate certain devices when the CPU requests data from an address where we want that device to take control.

In our case, the backplane has some logic that tells one of the expansion slots to activate when a certain address range is requested by the CPU. This address decoding, as it is called is taken care of by an ATF22V10, a [programmable logic chip](https://en.wikipedia.org/wiki/Programmable_logic_device) that can be thought of as an ancestor to FPGAs.

This functionality could also be built from discrete logic chips, but using a PLD chip does three things for us:
- First it saves board space. The functionality this single chip provides would need at least two or three to replicate with discrete logic
- Secondly, it speeds up the response time. Each time a signal passes through a chip, it incurs a slight delay. So the fewer chips are on the path, the faster our computer can run.
- Finally, it allows us to reprogram it to easily change the memory map of the system.

In the default case, slot 1 responds in the address range `$FF80` to `$FF8F`, slot 2 to `$FF90` to `$FF9F`, etc until slot 5 at `$FFC0` to `$FFCF`. This address decoding can be reconfigured by simply reprogramming the PLD, giving quite a lot of flexibility to the system.

Here is the default expansion memory map in table form

|-------------------------------------------------------------------|
|  START ADDRESS    |   END ADDRESS       |     DESCRIPTION         |
|-------------------------------------------------------------------|
|  0xFF80           |   0xFF8F            | SLOT0 Selected          |
|  0xFF90           |   0xFF9F            | SLOT1 Selected          |
|  0xFFA0           |   0xFFAF            | SLOT2 Selected          |
|  0xFFB0           |   0xFFBF            | SLOT3 Selected          |
|  0xFFC0           |   0xFFCF            | SLOT4 Selected          |
|  0xFFD0           |   0xFFDF            | SLOT5 Selected          |
|-------------------------------------------------------------------|

### Basic user IO

The mainboard provides some basic user input and output in the form of two buttons and 4 leds.

The two buttons are a reset button and an NMI (non maskable interrupt) buttons. The reset button triggers a hard reset of the processor, whereas the NMI button provides a non maskable interrupt to the code that can be handled as a soft reset by the code.

The 4 LEDs are connected to pins on the expansion bus, and can thus be driven by any card that wants to signal something to the user. You have to be midful in your code not to drive a led low while another card is trying to drive it high, as that would cause very high current to flow into / from your peripherals.

Finally, there is a power plug (Barrel jack), a power switch and a power LED.

If you want to build this computer, please see the [building the computer](build) page to get more details about what to expect.

### Serial IO

Included on the main board is a WDC 6552 serial interface. Its signals are brought out to a pin header into which a USB to serial adapter can be pluged.

### RAM and ROM

32K of RAM and ROM are provided. The RAM socket allows for narrow or wide ram to be used. 

<!-- <script async src="https://js.stripe.com/v3/pricing-table.js"></script>
<stripe-pricing-table pricing-table-id="prctbl_1NZeIWDtAuPfKnt3aQTV31Hu"
publishable-key="pk_live_51LNKdxDtAuPfKnt3hZwpiwcGTgssR7GG2jbIRn4DPIOubydZ5rS7yfBJlkI4AbDmIXCDKMLSh93dPcZv4k3fWn4f00itJp3VWr">
</stripe-pricing-table> -->

3D View

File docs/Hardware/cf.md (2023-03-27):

---
layout: board
title: Compact Flash board
short_title: CF board

order: 80

status: prod
design_files: https://gitlab.com/planck-6502/planck-6502/-/tree/main/Hardware/cf_board
order: 40
gerbers: https://planck6502.com/fabrication/cf_board-zip.zip
schematic: https://planck6502.com/fabrication/cf_board-schematic.pdf
html_bom: https://planck6502.com/fabrication/cf_board-bom.html
csv_bom: https://planck6502.com/fabrication/cf_board-bom.csv
---

## Compact Flash interface card

This is a compact flash memory interface card to allow the Planck 6502 to save and restore data to mass storage.

Top view of the CompactFlash board

TaliForth works with raw block storage on the CompactFlash card. A block is 1024 bytes.
To read the contents of a block, type `{numblock} list` where `{numblock}` is the number of the block to read, so for example `0 list` to show the contents of block 0, or `1000 list` to show the contents of block 1000.

Read the [Taliforth documentation](https://github.com/SamCoVT/TaliForth2/blob/master-64tass/docs/manual.md#working-with-blocks) to know more.

## Warning

Building this card is a difficult endeavour due to the fine pitch of the CompactFlash socket.

3D View

## Slot placement

SLOT 5 (`$FFD0`)

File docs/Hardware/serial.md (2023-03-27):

---
layout: board
title: Serial board
status: deprecated
design_files: https://gitlab.com/planck-6502/planck-6502/-/tree/main/Hardware/serial_board
order: 996
---

This board provides a WDC6551 ACIA chip and its associated oscillator. A socket is provided to plug in the USB to serial adapter of your choice. This allows you to connect the Planck computer to your laptop or desktop computer and interact with via software such as putty or coolTerm.

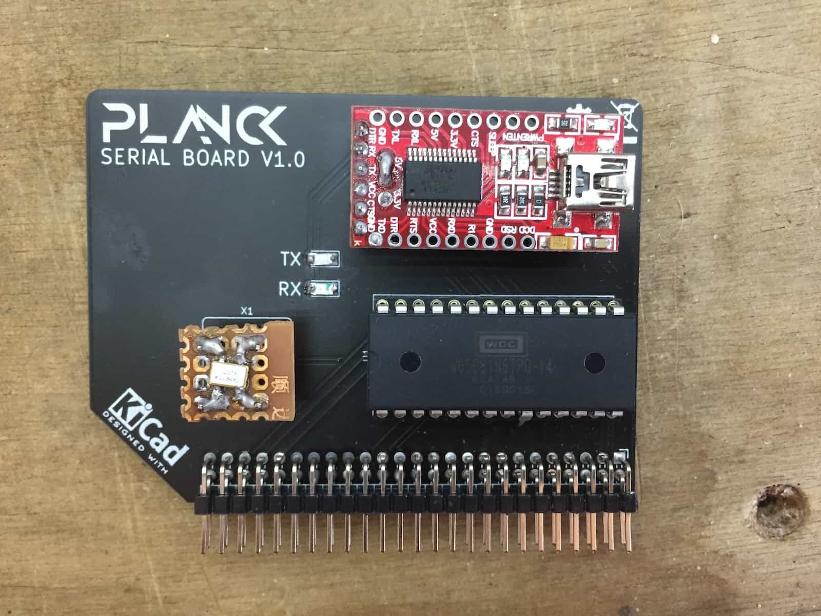
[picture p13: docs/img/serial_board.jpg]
Serial board photo


In the above image you can see the FTDI USB to serial adapter, below which is 65C51 ACIA chip.

To the left of that is the 1.8432 MHz crystal (an SMD part soldered to a piece of prototype board to fit in the DIP socket the board provides)

## Slot placement

The Serial board should be inserted in SLOT 3 on the backplane, otherwise you will have to change the hardware definitions in [`platform-planck.asm`](https://gitlab.com/planck-6502/planck-6502/-/blob/main/Software/forth/platform/platform-planck.asm#L109)

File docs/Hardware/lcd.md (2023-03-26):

---
layout: board
title: LCD board
status: prod
design_files: https://gitlab.com/planck-6502/planck-6502/-/tree/main/Hardware/lcd_board
gerbers: https://planck6502.com/fabrication/lcd_board-zip.zip
schematic: https://planck6502.com/fabrication/lcd_board-schematic.pdf
html_bom: https://planck6502.com/fabrication/lcd_board-bom.html
csv_bom: https://planck6502.com/fabrication/lcd_board-bom.csv
order: 50
---

This board allows a HD44780 based LCD such as [this one](https://www.ebay.fr/itm/2004-20x4-Character-LCD-Display-Module-2004-LCD-Blue-Yellow-Blacklight-HD44780/264032858433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) to display data from the computer.

The LCD is enabled by default in the ROM file. Due to the delays it requires, it significantly slows the output. If you are only using the computer over serial, you can disable printing to the LCD by setting a zero in the location pointed to by the `haslcd` word, for example like this:

```
0 haslcd c!
```

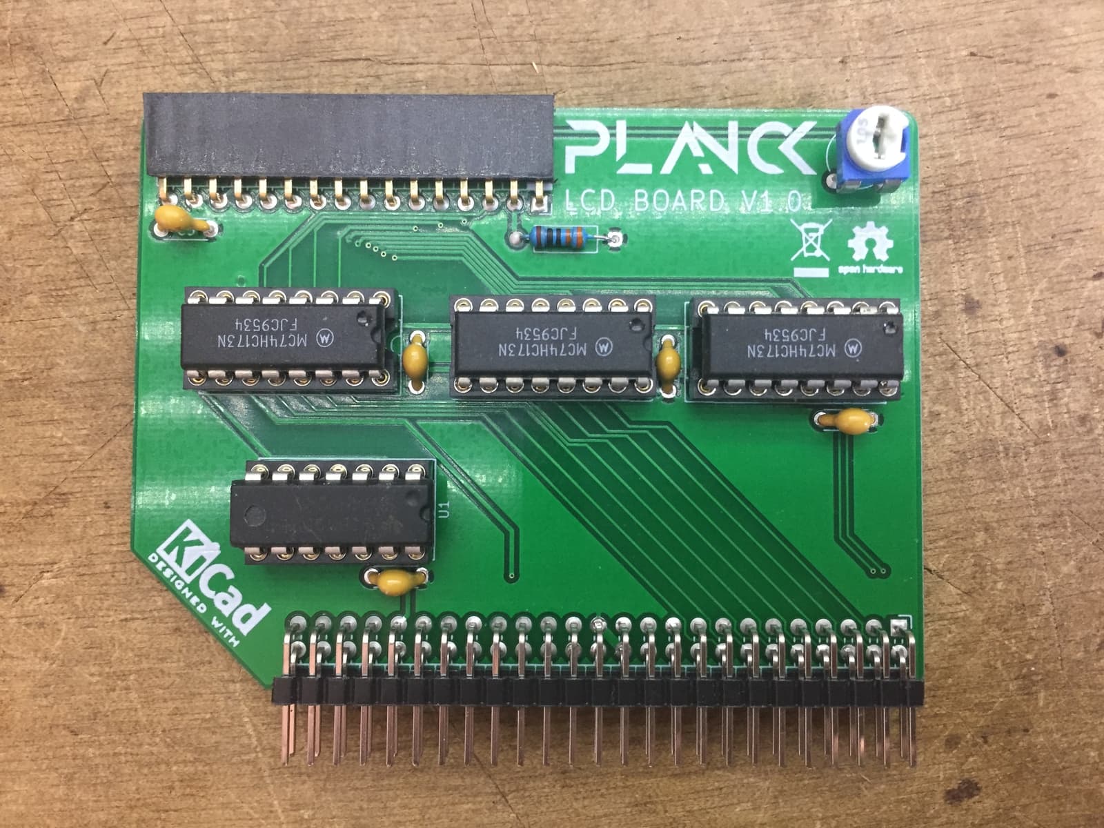
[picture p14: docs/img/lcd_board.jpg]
Planck prototype board for LCD


3D View

## Slot placement

The LCD board should be inserted in SLOT 4 on the backplane, otherwise you will have to change the hardware definitions in [`lcd.inc`](https://gitlab.com/planck-6502/planck-6502/-/blob/main/Software/fos/platform/planck/drivers/lcd.inc)

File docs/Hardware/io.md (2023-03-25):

---
layout: board
title: I/O board
status: prod
design_files: https://gitlab.com/planck-6502/planck-6502/-/tree/main/Hardware/io_board
order: 40
gerbers: https://planck6502.com/fabrication/io_board-zip.zip
schematic: https://planck6502.com/fabrication/io_board-schematic.pdf
html_bom: https://planck6502.com/fabrication/io_board-bom.html
csv_bom: https://planck6502.com/fabrication/io_board-bom.csv
---

This board is based on a WDC65C22 chip and provides a keyboard PS/2 port, a parallel port and a 65SIB port (serial port similar to and compatible with SPI)

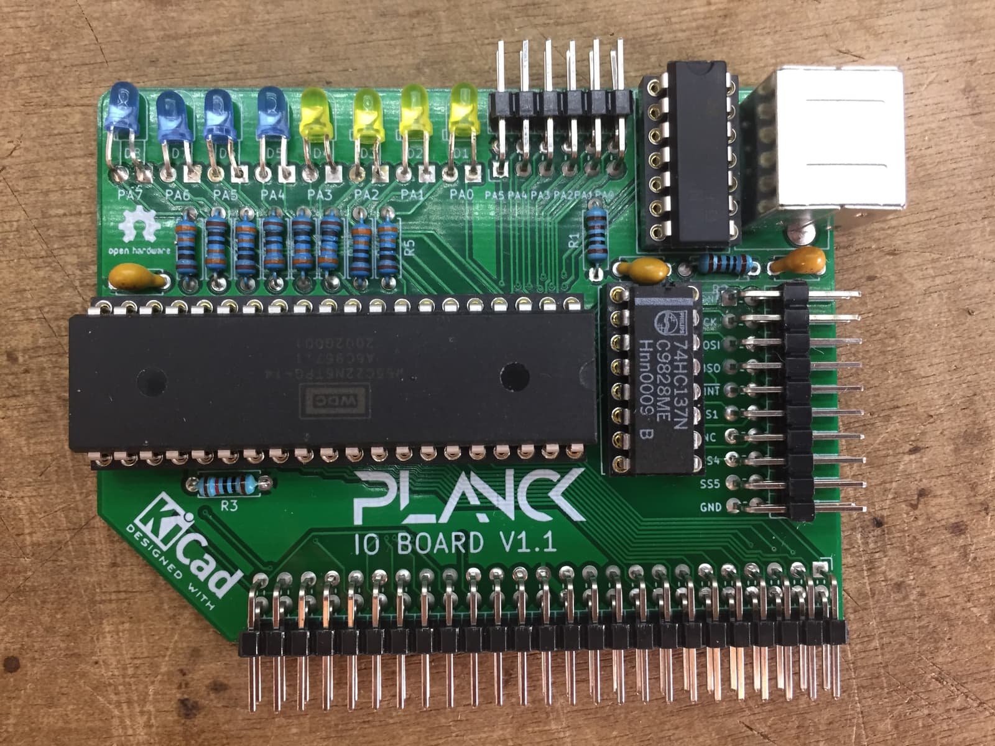
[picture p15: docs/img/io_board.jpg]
IO board


In this image you can see the PS/2 port at the top right, and just to he left of it a parallel port connected to the VIA's PORTA pins. Then to the right again 8 LEDs also connected to the PORTA pins.

Below the LEDs is the 65C22 VIA itself. To its right is located a 74HC137 chip that selects the SPI slave device to be used. And finally, to the right of that, at the back of the card is located the modified 65SIB port, which is basically an SPI port that can allow addressing up to 7 different devices.

## Slot placement

The I/O board should be inserted in SLOT 0 on the backplane, otherwise you will have to change the hardware definitions in [`platform-planck.asm`](https://gitlab.com/planck-6502/planck-6502/-/blob/main/Software/forth/platform/platform-planck.asm#L109)

3D View

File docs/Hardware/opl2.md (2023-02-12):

---
layout: board
title: OPL2 sound card
short_title: OPL2 board
status: prod
design_files: https://gitlab.com/planck-6502/planck-6502/-/tree/main/Hardware/opl2_board
order: 60
gerbers: https://planck6502.com/fabrication/opl2_board-zip.zip
schematic: https://planck6502.com/fabrication/opl2_board-schematic.pdf
html_bom: https://planck6502.com/fabrication/opl2_board-bom.html
csv_bom: https://planck6502.com/fabrication/opl2_board-bom.csv
---

This is a sound card based on the [Yamaha YM3812 chip](https://en.wikipedia.org/wiki/Yamaha_YM3812), also known as OPL2 chip. It was used on early PC sound cards such as the Soundblaster and Adlib and various Yamahe synthesizers.

## Prototype

Great news! [The prototype is complete and working!](/news/2021/06/26/opl2-sound-card/)

## Production PCB

The production PCB is tested and works fine. It will soon be available for order on Tindie. However still missing is the driver code for it. As of now there is only some test code that plays simple tones. You are more than welcome to [contribute some code](https://gitlab.com/planck-6502/planck-6502/-/tree/main/Software/drivers) to fix this.

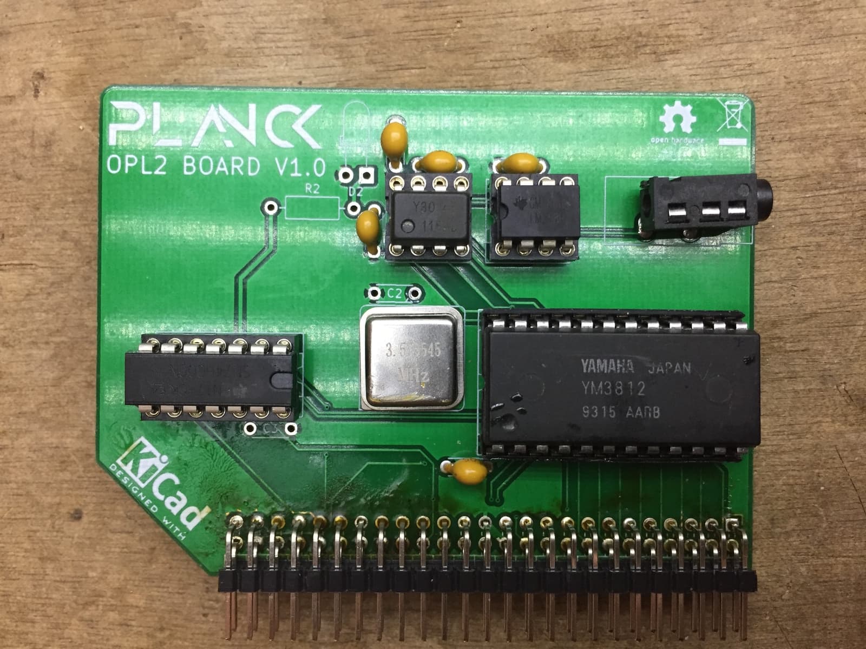
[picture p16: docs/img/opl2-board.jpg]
OPL2 board image


## Slot placement

TBD

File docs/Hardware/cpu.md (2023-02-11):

---
layout: board
title: CPU board
status: deprecated
design_files: https://gitlab.com/planck-6502/planck-6502/-/tree/main/Hardware/proc_board
order: 999
---

The CPU board contains the 65C02 cpu itself, but also 32K of ROM and 32K of RAM as well as the address decoding to handle these.

The address decoding is provided by a PLD, more specifically an ATF16V8. This chip also handles the incoming interrupt requests from the expansion card before passing them on to the CPU such that each extension card can send it's own IRQ signal without risking contention with other cards.

The RAM can be either a wide or a narrow DIP chip, like the narrow IDT71256 or a more "classic" wide 62256 chip.
The ROM placement on the board can accomodate a ZIF socket to allow the user to more easily update the software on the chip.

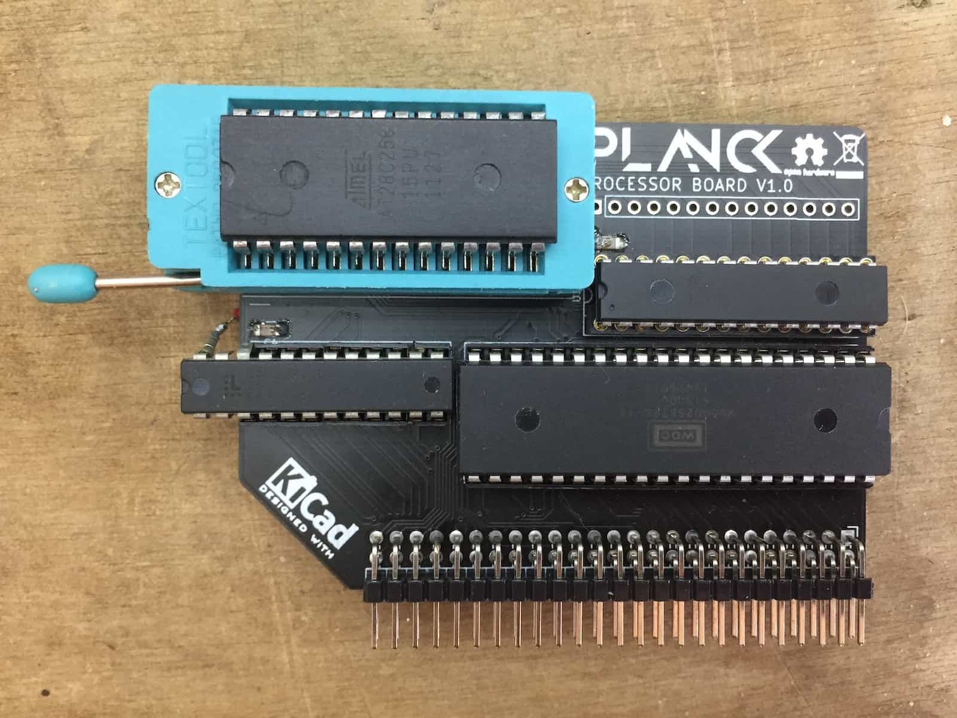
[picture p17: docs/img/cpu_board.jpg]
CPU board


In this picture, you can see the 32k ROM chip in its ZIF socket at the top left.

At the top right is the RAM. As you can see, an additional row of holes are provided to accomodate a wide socket in case that is the RAM you have.

Bottom row at the left, you can see the address deconding for the onboard RAM and ROM. It is supposed to be an ATF16V8, but I only had 22V10s on hand, so some pins stick out the board, and had to be conected via soldered wires.

Finally at the bottom left in the 65C02 CPU.

## Slot placement

The CPU board **MUST** be inserted in SLOT 0, marked `CPU BOARD` on the backplane.

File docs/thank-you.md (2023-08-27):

---
layout: page
---
# Purchase complete

Your payment went through and I (probably) received an email telling me that I sold a thing! So next thing you know, I'll be counting capacitors, putting them in little bags, cutting bands of resistors of different values and writing the value on the little paper tabs, trying not to forget the diodes, programming the ICs, putting them in protecting bags, then get them out to test them because I forgot, put them back in, solder the surface mount components if there are any, put it all in one big box with your name and address on it, then, quickly recapping everything in my head and with a bit of doubt as to whether everything is in there, seal the envelope.

Since it's probably too late for the post office by this time, I'll put it near the door so that I don't forget it in the morning. Then I'll go ask the not so nice lady at the post office to please send this for me, and she'll say "ok but that'll be ${A LOT}". After paying she'll take the package, which will start its way to its (hopefully) happy new owner, YOU!

In other words,

<p style="font-size:3em; text-align:center">Thanks for your purchase!</p>

<p style="font-size:3em; text-align:center">❣◕ ‿ ◕❣</p>

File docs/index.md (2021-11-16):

---
layout: page
title: An open-hardware, extensible 65c02-based computer
---

General view

This is a hobby computer based on the 65C02 processor. (I use 6502 and 65C02 interchangeably in this document, but [there are some differences](http://wilsonminesco.com/NMOS-CMOSdif/))

There are already many computers based on the 6502 processor, old ones such as as the Apple 1, Apple II, Commodore 64 and many more; and many more recent ones, from homebrew affairs on prototype board, to complete replicas of old systems.

The one that most closely resembles the Planck is probably the RC6502, itself based on the RC2014 (which uses a Z80 processor) with adaptations to the expansion bus to make it fit the 6502 processor.

Planck is a new variant on this type of expandable machines with a different set of tradeoffs.

### Contraints and requirements

The constraints for its design were the following:

  - Minimum board size, 2 layers, as that is what is cheapest to have fabricated.
  - Easily extensible with for example:
    - Serial port
    - Parallel port
    - SPI / [65SIB](http://forum.6502.org/viewtopic.php?p=10957#p10957) port
    - PS/2 port for keyboard
    - Sound card
    - eventually VGA out
    - SD card
    - LCD screen
  - Target clock speed of 10 to 12 MHz

## Some details

These requirements resulted in a computer based on a [motherboard](/Hardware) hosting RAM, ROM and CPU and extension slots for expansion cards to plug into.

The [Planck hardware pages](/Hardware) explains more about the functionality of the backplane and of each basic extension boards.

Of course, you can [design your own expansion boards](/Hardware/make) to make the computer do whatever **you** decide

<!--
## Buy it now

### With Paypal
Currently out of stock, sorry, should be back around mid Novemeber 2021

<div>
<form target="paypal" action="https://www.paypal.com/cgi-bin/webscr" method="post">
<input type="hidden" name="cmd" value="_s-xclick">
<input type="hidden" name="hosted_button_id" value="WNF3GUCN92CT6">
<table style="border:none"  cellpadding="0">
<tr>
<td style="border:none;vertical-align:middle">
<input type="hidden" name="on0" value="Include ICs ?">
<select name="os0">
	<option value="No ICs">No ICs €69,00 EUR</option>
	<option value="All ICs">All ICs €99,00 EUR</option>
</select>
</td>
<td style="border:none;vertical-align:middle"><input type="hidden" name="currency_code" value="EUR">
<input type="image" src="https://www.paypalobjects.com/en_US/i/btn/btn_cart_LG.gif" border="0" name="submit" alt="PayPal - The safer, easier way to pay online!">
<img alt="" border="0" src="https://www.paypalobjects.com/en_US/i/scr/pixel.gif" width="1" height="1"></td>
</tr>
</table>
</form>
</div>

### On Tindie

Currently out of stock, sorry, should be back around mid Novemeber 2021

<a href="https://www.tindie.com/products/24831/"><img src="https://d2ss6ovg47m0r5.cloudfront.net/badges/tindie-larges.png" alt="Buy the Planck 6502 computer on Tindie" width="200" height="104"></a>

### Financial stats

I like openness, so I keep a [running tally of costs and income](/stats).
-->

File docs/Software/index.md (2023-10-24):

---
layout: page
title: Planck 6502 software
---

## Programmable Logic

The first thing to setup when building your Planck 6502 is to program the PLD chips on the mainboard. This provides address decoding logic for all 6 expansion slots on the board. Basically, when a specific address range is requested by the CPU, this chip pulls one of the SLOT selection lines low. It also pulls the SSEL signal low to let other expansion boards know that an expansion slot is selected. This allows other boards to disable themselves as well if necessary. The second smaller PLD chip is used to choose whther a specific address should be directed to the ROM, RAM, or serial chip on the mainboard.

The source code used to program the chips is in [CUPL](https://en.wikipedia.org/wiki/Programmable_Array_Logic#CUPL) format.

There are two precompiled files : 
  - `Computer.jed` is used for the ATF22V10 chip that handles the extension slots.
  - `Processor-16V8.jed` is used for the ATF16V8 chip.

You will then need to program the ATF16V8 for the CPU board in much the same way.

Once that is done, everyting is setup to run...

## Actual software

The software is currently built around a modified version of [Tali Forth 2](https://github.com/scotws/TaliForth2). A binary is provided in [`Software/fos/fos-planck.bin`](https://gitlab.com/planck-6502/planck-6502/-/tree/main/Software/fos). Just program this binary to a 32K eeprom, insert it in the socket on the main board and you should be good to go.

By default the software expects the boards to be in a certain slot, but this can be changed by changing the hardware definitions in [`platform/planck/drivers`](https://gitlab.com/planck-6502/planck-6502/-/blob/main/Software/fos/platform/planck/drivers) or by reprogramming the backplane PLD chip as detailed above.

At boot time, Forth is copied from the ROM to the RAM for faster execution, leaving little space for anything else. The Forth dictionary is a minimum of `$1000` bytes. Depending on your configuration, it runs from the end of the BSS segment to the top of RAM.

### Running the software

By default, the PS/2 keyboard from the I/O card is enabled as an input, as well as the input from the serial chip, which means you can use both to type text into the Planck 6502.

For output you will see that both serial output as well as LCD output is enabled. However if you do not use the LCD, you may want to disable it and reflash the ROM since the delays required to wait for the LCD to respond make the serial output unnecessarily slow.

You can however use the LCD as an output if you want to use your Planck as a stand alone computer. With a PS/2 keyboard and the LCD screen it is really quite a usable Forth machine.

Some small utilities are present on the provided software, defined as forth words:

- `uptime` gives the time since power up / reset in hours, minutes, seconds and hundredths of a second. The time itself is stored in 4 bytes starting at address `$82`. The number at that address is incremented every 5 milliseconds with a 24 MHz main crystal. (requires the [IO board](/Hardware/io))
- `dumpzp` is a shortcut to dump the zero page
- `lights` will blink the IO board's led very fast
- `slights` will blink the IO board's led slower
- `vslights` will blink the IO board's led very slowly

There are drivers for most of the cards to be able to use them from forth as well as from assembly.

### Customizing the software

Say you just [created a new board](/Hardware/make) for your computer, you will need to write drivers for it. I recommend doing so in assembly as that will give you the best performance, but the drivers can also be written in forth. Below, i will detail how to write drivers in assembly for your custom expansion card.

As you can see, the [Software/drivers](https://gitlab.com/planck-6502/planck-6502/-/tree/main/Software/drivers) folder already contains drivers for expansion cards. You can create a new file named `my_card.s` and write your initialization and usage routines in it.

Then in the [fos/platform/planck/main.s](https://gitlab.com/planck-6502/planck-6502/-/blob/main/Software/fos/platform/planck/main.s) file you will have to include your new driver file or files similarly to how other driver files are included : 

``` nesasm
.include "drivers/keyboard.s"
```

Then, after the `kernel_init:` label, you can call your initialization routine if any.

To use your driver from Forth, please see the [Tali Forth documentation](https://github.com/scotws/TaliForth2/blob/master/docs/manual.md#adding-new-words) for adding new native words.

## Uploading software

Forth now includes words to load binary data in [intel HEX format](https://en.wikipedia.org/wiki/Intel_HEX) from the serial port.

Use the `ihex` word to start loading data, then paste the contents in your terminal emulator window.

The data will be placed at the addresses specified in the intel HEX file. Be careful not to clobber the `ihex` routine nor its variables. The ihex routine is `$CF` bytes long, so do not touch anything for at least `$D0` bytes after `' ihex` (the address or the word in RAM).

Once your binary data is in place, you can jump to it with the word `go`, so for example if your executable code is loaded at `$7E80`, doing `hex 7e80 go` will jump to the start of your program.

## Forth

For general information about the Forth programming language, [Starting Forth](https://www.forth.com/starting-forth/) is a great resource. 

The [Taliforth documentation](https://github.com/scotws/TaliForth2/blob/master/docs/manual.md) is worth a read as well, since the Forth used by the Planck 6502 is based on it. The [6502.org forum](http://forum.6502.org/) has a [forth section](http://forum.6502.org/viewforum.php?f=9&sid=f950c7259167a625796c614111543ead) as well, to talk about forth on the 6502 in general.

If you want to discuss Forth on the Planck 6502 in particular, or other software options for the Planck, you can head over to [our forum's Software section](https://forum.planck6502.com/c/software/6)

Finally, since the assembler used in ca65, you may want to familiarize yourself with [cc65's documentation](https://cc65.github.io/doc/)

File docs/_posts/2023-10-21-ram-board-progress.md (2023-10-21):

---
layout: post
title:  "Good progress on the RAM board"
excerpt_separator: <!--more-->
---

The boards I had made for the [RAM expansion board](/Hardware/ram/) prototype were not working properly. It's been a few months already, but I have not gone around to trying to fix it until now.

<!--more-->

It turns out the logic to latch the bank register was wrong. I was NANDing the SLOT_SEL and clock signals together, which of course gave a square wave at the frequency of the clock itself. I should have spotted that to have a high signal when both the clock and SLOT_SEL signals go down, an NOR gate is sufficient.

So I scraped a few traces off, added a 74HC02 hanging in mid-air, and everything works perfectly now !!

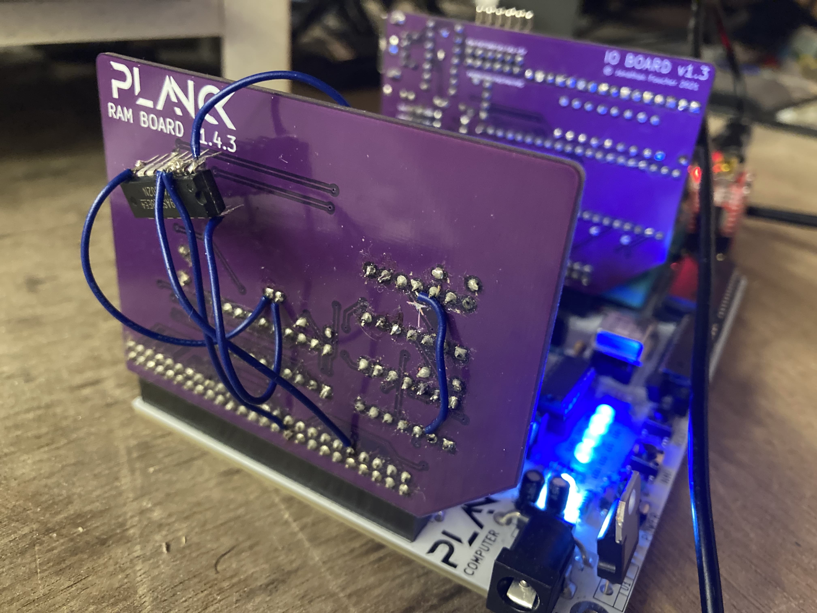
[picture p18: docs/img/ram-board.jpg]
RAM board with chip hanging off it


The [board Kicad files](https://gitlab.com/planck-6502/planck-6502/-/tree/main/Hardware/ram_board?ref_type=heads) and [gerbers](https://planck6502.com/Hardware/ram/) will be updated soon.

I have also added a few words to the Forth firmware, namely `expad` which allows to set the slot where the ram board is located (run `hex ffd0 expad` if the board is in Slot 5 for example) and `bank` to activate / deactivate and set set the current bank.

`0 bank` will deactivate the expansion RAM and reactivate the ROM.
`hex 80 bank` will deactivate the ROM between `$8000` and `$BFFF` and place bank 0 of the RAM there.

The high bit of the value determines if the RAM is active or not (top bit set : RAM active, ROM deactivated, top bit unset : RAM deactivated, ROM active)

It is not possible to read the RAM expansion card register to check which bank is active, so your code should remember this information

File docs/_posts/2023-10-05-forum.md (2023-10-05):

---
layout: post
title:  "Updated forum"
excerpt_separator: <!--more-->
---

A [new forum](https://forum.planck6502.com) is online for all current and future users of the Planck 6502. Come chat with us and discover the Planck 6502 even further.

Welcome!

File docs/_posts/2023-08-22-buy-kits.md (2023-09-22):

---
layout: post
title:  "Finally some kits for sale"
excerpt_separator: <!--more-->
---

### Sold out for now, more on the way. Sorry
<!-- 
### Original post

I finally managed to get a hold of enough parts to make about 10 kits for the Planck 6502. I also have parts to make kits for most of the expansion boards. See below for how to buy it.
-->
<!--more-->
<!--
At the moment the buying process is a little manual and convoluted, because I don't have the time to setup a proper store, and Tindie doesn't handle VAT for european sellers (which I am).

So basically, if you are interested in any of the [hardware](/Hardware/), [send me an email at jfoucher@6px.eu](mailto:jfoucher@6px.eu) with what you would like to buy, and I'll send you a [Stripe](https://stripe.com) link for the payment. Of course, only the hardware that is marked as __PCB tested and working__ is available to buy.

Here are the prices :

- [Planck computer](/Hardware/mainboard/) with no ICs (only includes passive components) : $89
- [Planck computer](/Hardware/mainboard/) with all ICs (AT28C256 ROM from ebay, tested functional) : $149

- [IO board](/Hardware/io/) with no ICs : $29
- [IO board](/Hardware/io/) with all ICs : $39

- [LCD board](/Hardware/lcd/): $29

- [Prototype board](/Hardware/proto/): $5

- [OPL2 (sound) board](/Hardware/opl2/): $29

- [CompactFlash board](/Hardware/cf/) (includes surface mount soldering for CF card socket): $39

Shipping is free from $200 of purchase total. Otherwise it seems to be around $15 or so to the US, depending on the weight of the package. 

If you want a complete bundle, I have a special offer for you: $290 for one computer, one IO board, one LCD board, one OPL2 board, one CompactFlash board, and 5 prototype boards.

-->

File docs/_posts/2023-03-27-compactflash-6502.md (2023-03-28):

---
layout: post
title:  "CompactFlash card on the 65C02 CPU"
excerpt_separator: <!--more-->
---

After [struggling](https://planck6502.com/news/2023/03/07/filesystem-for-planck/) for a [long time](http://forum.6502.org/viewtopic.php?f=4&t=7525&p=99246) with my prototype CompactFlash board, it turns out that once the design was put onto a PCB (and a few corrections made), everything worked flawlessly.

<!--more-->

## Hardware

You can get the [full schematic for the CompactFlash board](https://planck6502.com/fabrication/cf_board-schematic.pdf), but here is the gist of it:

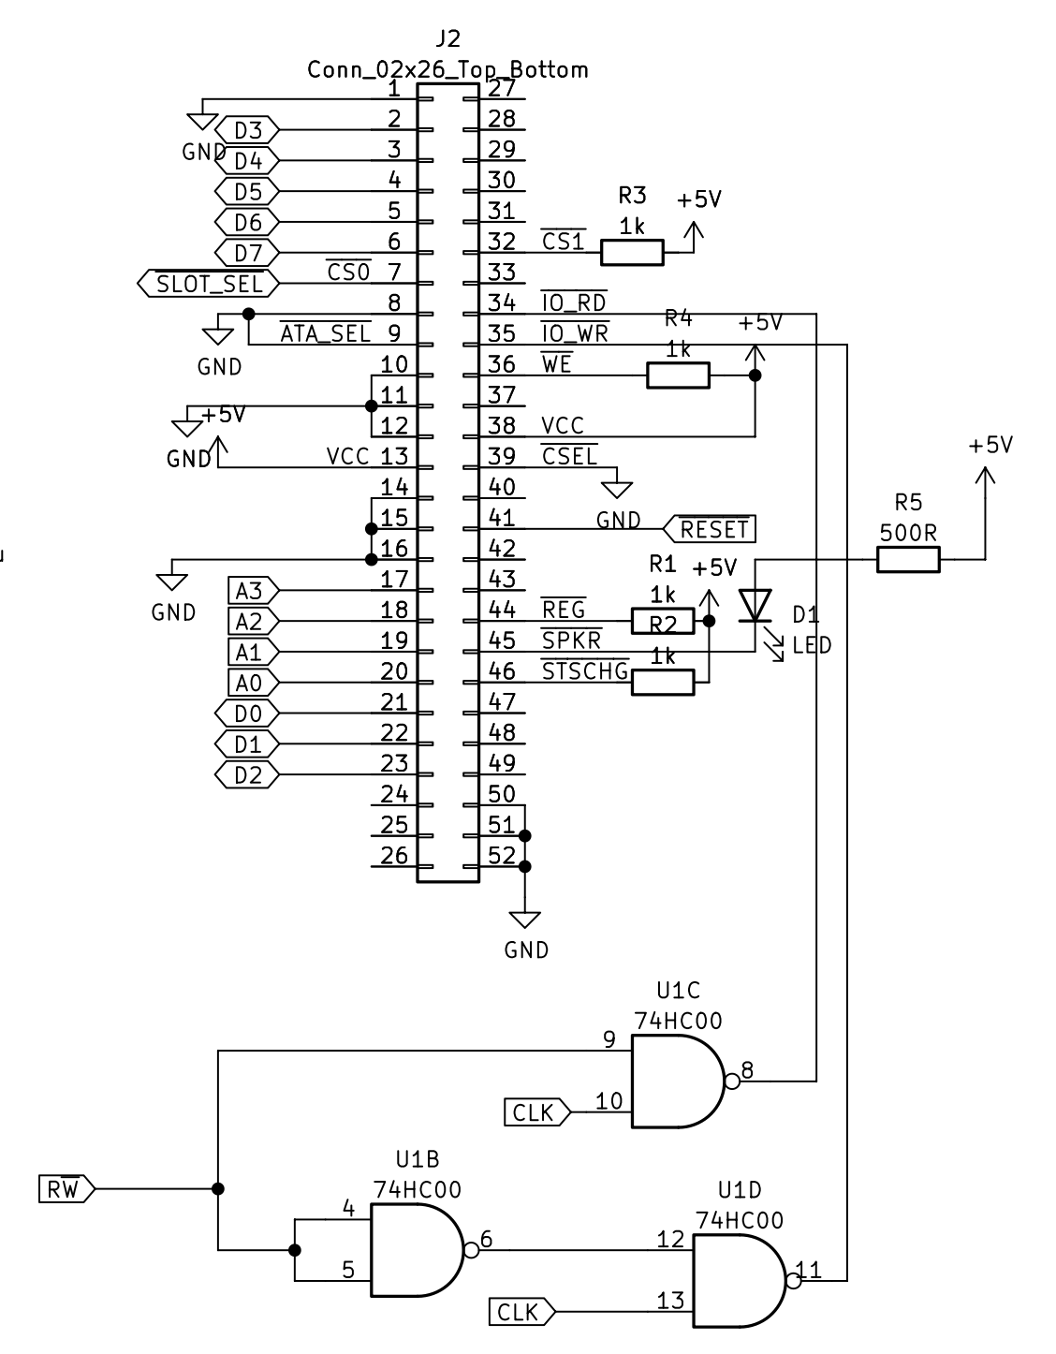
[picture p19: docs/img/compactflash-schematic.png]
CompactFlash schematic


Basically, we connect all 8 data pins to the lower byte data pins on the CF card (CompactFlash works in 16 bit mode natively), and A0 to A3 to the lower four address lines of the CF card. Conveniently, the CompactFlash card in 8 bit mode requires only four address lines, which is exactly the address space that each expansion slots has available to it (16 bytes).

Then, we need to add some external ciruitry to convert the R/W signal and clock to the /IO_RD and /IO_WR signals that the CompactFlash card requires. This is just one NAND chip that set /IO_RD low when the R/W signal is high and the clock goes low, and set /IO_WR low when the R/W signal is low and the clock goes low.

The /CS0 signal is simply wired to the /SLOT_SEL signal from the bus, so that the CF card is selected whenever it's slot is selected.

/CS1 is hard wired to a high signal, because it is only used in 16 bit mode (as far as I could make out).

Here is the first version that worked properly:

CompactFlash card photo

This is it for the hardware.

## Software

This is where I strugled pointelessly for a few weeks. With my prototype board ([this one](/Hardware/proto/) with a CF to IDA adapter and a mess of wires), I was getting spurious reads, some bytes would repeat, or not appear at all,  and minute changes to the code would produce completely unexpected results... But as it turned out, it was just due to signal integrity issues. Here is the front and back of the prototype board:

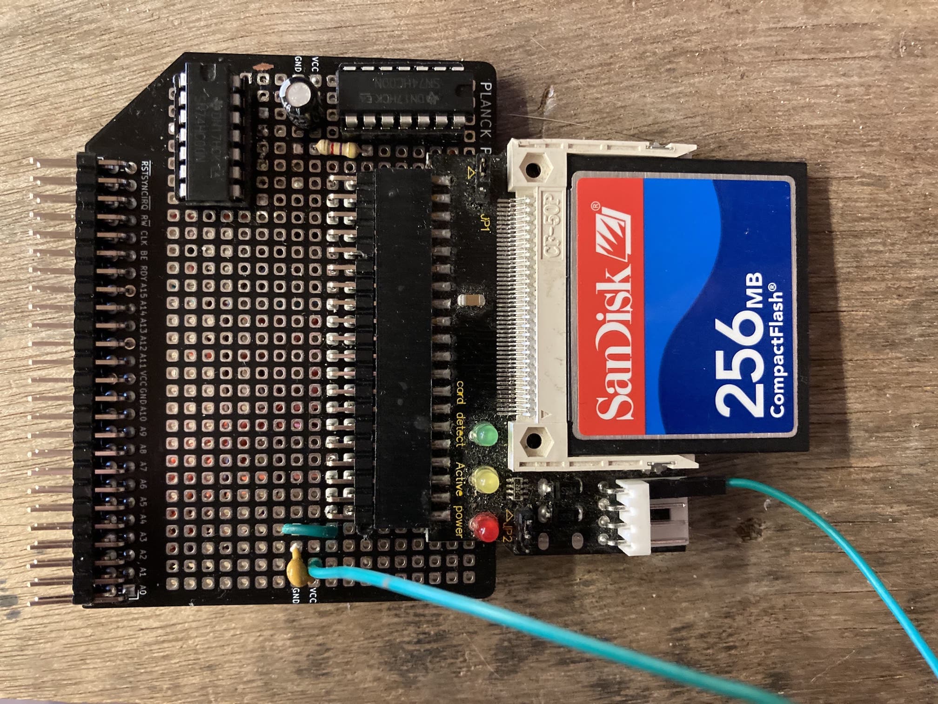
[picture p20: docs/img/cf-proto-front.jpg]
CF board prototype front


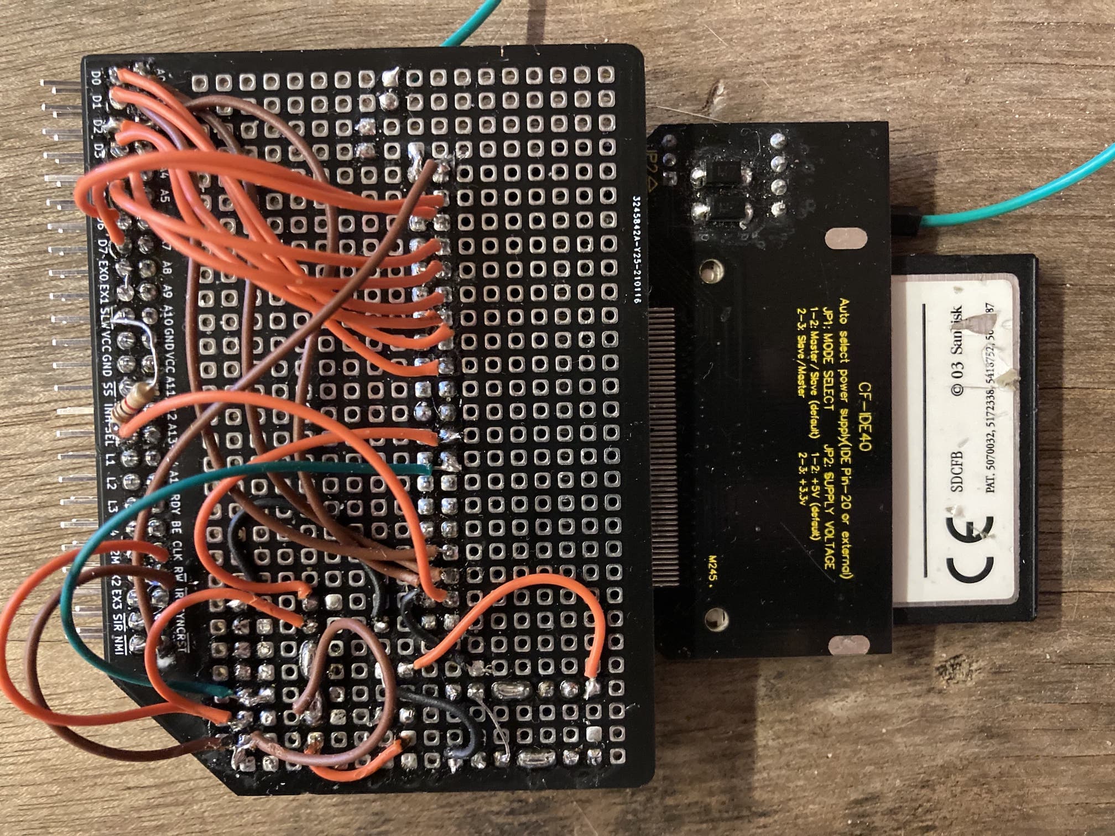
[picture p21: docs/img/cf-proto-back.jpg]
CF board prototype back


Thankfully, the [final CompactFlash board](/Hardware/cf/) works perfectly.

So anyway, the code to read data from the CF card is pretty simple:

``` nesasm
cf_read_sector:
    jsr cf_set_lba
    lda #1
    sta CF_ADDRESS + 2
    jsr cf_wait
    lda #CF_READ_SECTOR_COMMAND
    sta CF_ADDRESS + 7
    jsr cf_wait
    jsr cf_read
    jsr cf_err
    rts
```

This is the basic routine to trigger a sector read. It first calls the cf_set_lba routine which is as follows:

``` nesasm
cf_set_lba:
    lda IO_SECTOR
    sta CF_ADDRESS + 3
    jsr cf_wait
    lda IO_SECTOR + 1
    sta CF_ADDRESS + 4
    jsr cf_wait
    lda IO_SECTOR + 2
    sta CF_ADDRESS + 5
    jsr cf_wait
    lda IO_SECTOR + 3
    and #$0F
    ora #$E0
    sta CF_ADDRESS + 6
    jsr cf_wait
    rts
```

Basically, it takes a 32 bit sector number from `IO_SECTOR` ans stores it into registers 3, 4, 5 and 6 of the CF card. The store in register 6 keeps only the lower 4 bits (a sector address is 28 bits) and set the high nybble to `$E`. I do not remeber exactly what that does, but the [CompactFlash documentation](/img/SanDisk_CompactFlash_Memory.pdf) I found explains it.

Then the `cf_read_sector` stores the number of sectors to read into the CF card register 2 (in our case a 1 as we wish to read a single sector). Then it waits until the card is ready (cf_wait is described below), and then sets the command (read sector, `$20`) into register 7. We then wait again until the card is ready, and then trigger the read proper. This is done by the following routine:

``` nesasm
cf_read:
    phy
    ldy #0
@loop:
    jsr cf_wait
    lda CF_ADDRESS
    sta (io_buffer_ptr), y
    iny
    bne @loop
    inc io_buffer_ptr + 1
@loop2:
    jsr cf_wait
    lda CF_ADDRESS
    sta (io_buffer_ptr), y
    iny
    bne @loop2
    dec io_buffer_ptr + 1
@loop3:
    jsr cf_wait
    lda CF_ADDRESS + 7
    and #$08
    beq @exit
    lda CF_ADDRESS
    iny
    bne @loop3
@exit:
    ply
    rts
```

In this routine, we read the data register from the CF card repeatedly, until one page is complete (waiting for the card to be ready between each byte), and then we read the next page is the same way. Finally we read some more data until the card signals the end of the sector by setting bit 3 of the command register. The 512 byte buffer pointed to by `io_buffer_ptr` now contains one sector of data from the CompactFlash card!

Here is the cf_wait routine:

``` nesasm
cf_wait: 
    lda CF_ADDRESS + 7
    bmi cf_wait
    rts
```

Basically, we wait until bit 7 of the command register is unset to proceed.

And finally the `cf_err` routine, which is called at the end of the `cf_read_sector` routine

``` nesasm
cf_err:
    jsr cf_wait
    lda CF_ADDRESS + 7
    and #$01
    beq @exit
@exit_fail:
    lda #'!'
    jsr kernel_putc
@exit:
    rts
```

This routine waits for the card to be ready, then check if bit 0 of the command register is set and if so prints one `!` to indicate that an error has occurred, and otherwise does nothing.

And with that, we can now read data from a CompactFlash card with our humble 6502 processor (or in our case a 65C02).

Hopefully, this will give you some ideas for your own computer. You can also check the [finalised CompactFlash board](/Hardware/cf/). And a big thank you to everyone on the [6502.org forum](http://forum.6502.org) that gave tips and invaluable help.

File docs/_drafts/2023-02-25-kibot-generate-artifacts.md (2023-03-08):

---
layout: post
title:  "Generating Gerbers and schematics with Kibot"
excerpt_separator: <!--more-->
---

Kibot is a great tool that can automatically generate output files for our boards. Let's take a look at how to use it

<!--more-->

I publish all source files for the Planck computer on Gitlab, a souce code repository based on git. Gitlab has a feature where it can run some code everytime you upload a new version. It is possible to use this feature to generate updated gerber files, schematics, etc everytime a new version is published with Kibot, the KiCad automation tool.
You can install Kibot on your computer and run it from there, but I think the real beauty of it is to run it everytime we publish a new version, so that documentation, schematics, gerbers etc are always is sync.

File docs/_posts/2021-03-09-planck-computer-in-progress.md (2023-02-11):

---
layout: post
title:  "Designing a complete extensible computer"
image: /img/cpu_backplane.png
---

The Planck 6502 backplane can make a great retro computer if you add in the basic necessary boards. For the simplest possible configuration however, you need at least three boards : the backplane itself, the CPU board (which also contains RAM and ROM) and a serial board for I/O.

Following a reddit discussion on the [Planck 6502 intro post](https://www.reddit.com/r/retrocomputing/comments/luu9z0/planck_6502_an_open_hardware_extensible_retro/gp9m2jv) it occurred to me that it would not be more expensive to have a single slightly bigger board that would house the CPU, RAM, ROM and serial chips, while keeping all the expansion the the original Planck backplane has.

So I started drawing up a [schematic and a board layout](https://gitlab.com/planck-6502/planck-6502/-/tree/main/Hardware/cpu_backplane), and it turns out that all this can fit on a 100mmx150mm board, just 50mm wider than the original backplane. And while this is outside the "cheap PCB offer" of the likes of Jlcpcb, the price is still *very* reasonable. Actually it costs about the same as one backplane and 2 expansion boards.

So I feel that this new design is a win for most situations. I do not recommend you get it fabricated just yet since it has not been tested and will probably have a few bugs.

However, I cannot resist putting a 3D view here:

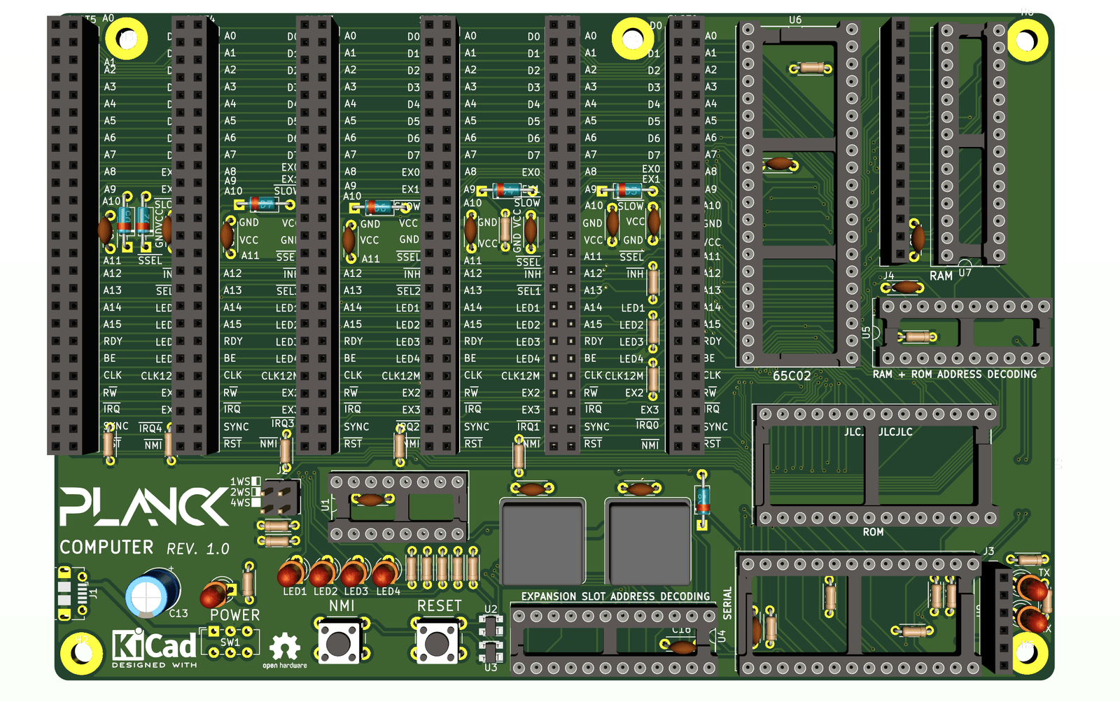
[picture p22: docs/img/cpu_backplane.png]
Planck computer 3D view


Hope you like it, [contact me](mailto:jfoucher@6px.eu) with any comments or suggestions.

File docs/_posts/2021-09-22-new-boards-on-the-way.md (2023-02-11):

---
layout: post
title:  "Planck computer design is in fabrication"
image: /img/resistors.jpg
---

The Planck computer is almost ready for the big time. I received the prototype a few days ago and the build with through hole components was fine, except I feel it takes slightly longer to solder all the components when they are through hole, because you have to cut all those spiky legs off, and my side cutters are not very sharp...

Then I had to reprogram the address decoding chip that handles the extension slots, to enable the new extension slot at address `$FFD0` and the serial chip at address `$FFE0`.

I also had to had to change the code slightly to update the serial chip address to the new one, and burn it to the EEPROM.

But after all that was done, it turns out that it works perfectly, on the first go, with a 24MHz oscillator, making the computer itself run at 12MHz. Very nice! There was only a slight mistake: the footprints I used for the resistors are slightly smaller than the resistors I have on hand, which means I had to install the resistors like that to make them fit:

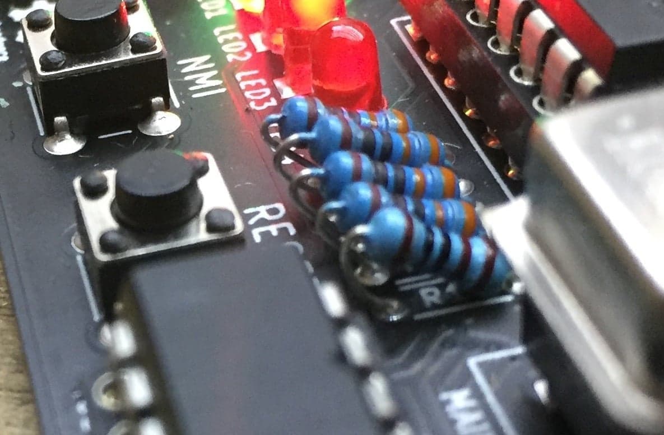
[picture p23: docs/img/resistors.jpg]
Bent resistors


This is now corrected on [the latest revision of the board](https://gitlab.com/planck-6502/planck-6502/-/tree/main/Hardware/cpu_backplane)

As you can from the image below, I had initially planned to use a ZIF socket for the EEPROM on the prototype board, since the computer has no provision for in circuit programming of the EEPROM. However, I went ahead and soldered a regular socket in it, because it turns out that a zif socket can be made to fit in a regular socket just fine.

The Planck 6502 computer is running!

All existing cards seem to work just fine in the new computer, which is expected but a relief nonetheless.

As  of right now, the final revision is in production, as well as three other boards, two of which I only have built on the prototype boards until now : the [OPL2 board](/Hardware/opl2/) and the [LCD board](/Hardware/lcd/). The third one is the through hole version of the [I/O board](/Hardware/io/)

Next, I am planning on designing a board to interact with an SD card. This board will plug into the back of the I/O  board with a ribbon cable to use its SPI capability. I will have to research some simple filesystems to use, because even implementing FAT16 in 6502 assembly seems like a daunting challenge.

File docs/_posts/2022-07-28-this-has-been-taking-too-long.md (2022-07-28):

---
layout: post
title:  "This has been taking too long 🙁"
excerpt_separator: <!--more-->
---

It's been a while, the waitlist [on Tindie](https://www.tindie.com/products/jfoucher/planck-6502-computer/) keeps growing and there's not much I've been able to do about it. Apart from supply chain issues for electroniccomponents, which may imply a new board revision in the near future, I have also moved to a house that has needed way more work done than expected. It's been over 6 months and not everything is ready yet.
<!--more-->

I do not want to store components and prepare packages in a space that is often full of dust and other worksite inconveniences.

However, I am hopefull the next few weeks will finally let me have a space to store everything I need and to prepare orders. So keep an eye on the Tindie listing if you are interested.

In the meantime, remember that the project is completely open source and open hardware, so head on over to [https://jlcpcb.com](JLCPCB) to order some boards, [https://mouser.com](Mouser) for the components and get soldering ! (with JLCPCB you'll get 5 boards, so that's going to be a lot of soldering !)

Otherwise just hang tight, I'll make sure to post an update here and on Tindie when I'm ready to ship new orders.

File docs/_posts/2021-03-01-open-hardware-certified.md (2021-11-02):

---
layout: post
title:  "Open Hardware certification granted!"
image: /img/OSHW_mark_FR000013.png
---

I am happy to announce that Planck 6502 is now Open Hardware Certified.

And it has the badge to prove it:

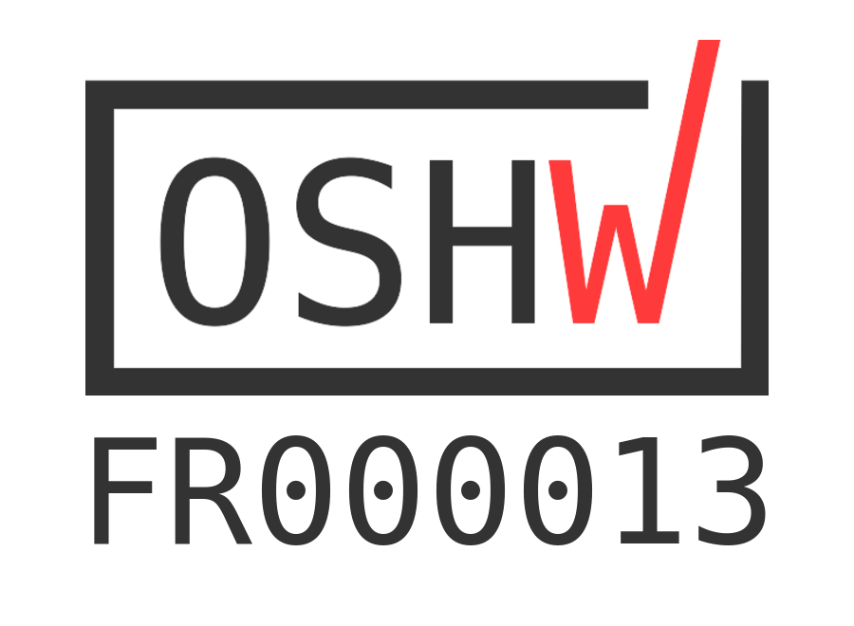
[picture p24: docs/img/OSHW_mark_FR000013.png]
OSHW certification badge


This is the 13th proect from France that the OSHW has certified. I'm not sure if that means good luck or bad luck (probably no influence at all on luck, but I guess time will tell :D)

Anyway I am pretty happy to be certified.

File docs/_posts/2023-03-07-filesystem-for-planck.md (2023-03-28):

---
layout: post
title:  "A filesystem for the Planck computer"
excerpt_separator: <!--more-->
---

Designing a file system for the 6502 MPU is not an easy task. In this post I will explain what I tried, what failed, and maybe what succeeded.

<!--more-->

## Failed attempts

I started by writing routines to access an SD card via the SPI port of the [IO board](/Hardware/io/). This works fine, and I can read blocks sucessfully. I then started implementing a fat32 filesystem to read it, but this proved to be too much code to add besides TaliForth, which already uses most of the available RAM (Taliforth is copied from ROM to RAM on boot for performance reasons). I tried it again recently and for some reason the SD card reading routines stopped working. I remember spending a good deal of time with a logic analyzer trying to understand what was going on, and I don't really look forward to doing it again for debugging.

I then built a [Compact Flash card adapter](/Hardware/cf/) following [this blog post](http://www.waveguide.se/?article=8-bit-compact-flash-interface) because I had a 256 MB CF card and IDE adapter lying around.However reading data off of it proved troublesome, some bytes would be in the wrong place, and I could not get it to read the boot sector reliably everytime. I also started writing a FAT16 implementation which could sucessfully initialize the FAT and read files. Just reading and listing files however is pretty long and annoying. However because of reliability problems with reading data from the CF card, I also gave up on that approach.

Actually, I gave up on trying to read data off of real media for now, and started experimenting with filesystems in a 65C02 emulator ([py65mon](https://py65.readthedocs.io/en/latest/))

## Filesystems

### FAT16

FAT16 was okay, I managed to read files pretty quickly, but the code was getting pretty big and I was worried that writing files was going to be much harder, so I stopped work on it, and next tried USTAR

### USTAR

[tar file as a filesystem (USTAR)](https://wiki.osdev.org/USTAR) is quite simple, and I could pretty quickly get it to find and read files, but after thinking about it, I realised that writing to this filesystem would be cumbersome: since all the data for each file is contiguous, adding data to a file beyond the current last sector of the file would mean rewriting every single file to the disk, which I don't think would be feasible with the limited amount of memory available. It makes sense for TAR to work this way, since it is an archive format the data will only be written once and then only read.

### MINIX FS

So next I wanted to try MinixFS, which is a simple, educational filesystem. It should therefore not be too hard to make it work in assembly.

Paradoxically, I have not been able to find quality material documenting the Minix filesystem, mostly some C souce code and course material in PDF format. Nonetheless, let me try and make it work.

#### Basic data read

The first step is to be able to read 1024 bytes of data at once into a buffer. The routine that does this expects a routine provided by the kernel to read a single 512 bytes sector from the disk. It just basically calls the IO routine twice while setting the sector to read each time.

Nothing complex here, the routine basically just does this:

``` nesasm
minix_read_block_noinc:
    mov16  MINIX_SECTOR, io_current_sector  ; copy sector to read to IO variable
    ; mov16 is a macro that copies 2 bytes at once

    jsr io_read_sector          ; read first sector

    inc io_buffer_ptr + 1       ; write to next buffer 512 block to get full 1024 block
    inc io_current_sector       ; setup to read next sector
    jsr io_read_sector          ; Read next sector
    dec io_buffer_ptr + 1       ; put buffer pointer back
    ; one full block is now in the buffer pointed to by io_buffer_ptr
    rts
```

#### Superblock

Once that is implemented, a data structure can be created to store data about the filesystem found in the superblock. On Minix, the superblock is always block 1 (remembering that each block is 2 512 bytes sectors, these are sectors 2 and 3 on disk). Block 0 (sectors 0 and 1) can be used to put optional boot code.

Once we have this block in memory, the layout of the superblock is very simple and actually only occupies 20 bytes at the start of the block :

<table>
<thead>
<tr>
<th colspan="17" align="center">
MINIX superblock layout
</th>
</tr>
<tr>
<td></td>
<td>$00</td><td>$01</td><td>$02</td><td>$03</td><td>$04</td><td>$05</td><td>$06</td><td>$07</td><td>$08</td><td>$09</td><td>$0A</td><td>$0B</td><td>$0C</td><td>$0D</td><td>$0E</td><td>$0F</td>
</tr>
</thead>
<tbody>
<tr>
<td>$00</td><td colspan="2">No. inodes</td><td colspan="2">No. zones</td><td colspan="2">inode map blocks</td><td colspan="2">zone map blocks</td><td colspan="2">First data zone</td><td colspan="2">Log zone size</td><td colspan="4">Max. file size</td>
</tr>
<tr>
<td>$10</td><td colspan="2">Minix magic</td><td colspan="2">Mount state</td><td colspan="12"></td>
</tr>
</tbody>
</table>

- No. inodes is the total number of inodes on the filesystem
- No. zones is the total number of zones on the filesystem, this is the same as the total number of blocks.
- inode map blocks: The total number of inode map blocks
- zone map blocks: the total number of zone map blocks
- first data zone is the block at which the first elements of data can be found. this is usually the contents of the root directory
- log zone size: this represents the size of a zone. the size of a zone in bytes is given by `1024 << log_zone_size`. If this is zero it means one zone = one block = 1024 bytes.
- max file size is a 32 bit number representing the maximum file size on this filesystem
- Minix magic is a magic number, `$138F` on Minix 1 with 30 character file names
- Mount state gives the state of the current filesystem: I think it is 1 for a mounted fs, and 0 for non mounted FS. It is then possible to check if the filesystem was unmounted cleanly.

#### Bitmaps

After the superblock, we have the inode bitmap, which is simple bitmap of free and occupied inodes. There is one bit for each inode, and an unset bit indicates that this inode is free, while a 1 bit indicates that it is used. This bitmap is `inode map blocks` long (see table above)

After the inode map block(s), we have the zone map block(s) which is `zone map blocks` long and is a bitmap of used and unused zones, where each free zone is a zero bit and each busy zone is a 1 bit.

These two series of blocks are only important for writing data, we need not concern ourselves with them for now.

#### inodes

After the zone map block(s) come the inodes themselves.

The first inode we want to get is the inode for the root directory. This is the inode number 1. Do note that inodes are 1 indexed, because if a file has no inode, the inode field will be 0 in its directory entry

So we load that inode by adding `inode map blocks` and `zone map blocks` and 1 (superblock number) to get the first inode block, and then we read the first 32 bytes there.

An inode entry is 32 bytes, formatted as follows:

<table>
<thead>
<tr>
<th colspan="17" align="center">
MINIX inode layout
</th>
</tr>
<tr>
<td></td>
<td>$00</td><td>$01</td><td>$02</td><td>$03</td><td>$04</td><td>$05</td><td>$06</td><td>$07</td><td>$08</td><td>$09</td><td>$0A</td><td>$0B</td><td>$0C</td><td>$0D</td><td>$0E</td><td>$0F</td>
</tr>
</thead>
<tbody>
<tr>
<td>$00</td><td colspan="2">MODE</td><td colspan="2">UID</td><td colspan="4">FILESIZE</td><td colspan="4">TIME</td><td>GID</td><td>LINKS</td><td colspan="2">ZONE 0</td>
</tr>
<tr>
<td>$10</td><td colspan="2">ZONE 1</td><td colspan="2">ZONE 2</td><td colspan="2">ZONE 3</td><td colspan="2">ZONE 4</td><td colspan="2">ZONE 5</td><td colspan="2">ZONE 6</td><td colspan="2">ZONE 7</td><td colspan="2">ZONE 8</td>
</tr>
</tbody>
</table>

The MODE is a bit of which type of file the inode is refering to. All we are concerning ourselves with is whether it is a file or directory. All other flags are ignored. A directory will have bit 14 set and a regular file will have bit 15 set, so we can test for these to know what we are dealing with.

Once we have loaded the inode in memory, we can then proceed to read the data from it.

The `ZONE N` fields gives us the location of the file data. `ZONE 0` is the first chunk, `ZONE 1` the second and so on. Except ZONE 7, which is an indirect zone: it points to a zone containing other zone pointers (which point to actual data). And ZONE 8 is a doubly indirect zone: it points to a zone full of pointers to indirect zones.

With only the direct zones, each file can contain 7kb of data. With the indirect zone added, this number jumps to 7+64 or 71k, and with the double indirect zone, to over 4 Mb.

#### Root directory

The first to getting data from the filesystem is to read the root directory. The root directory has it's own inode, which is the very first inode at the start of the first inode block.

Once we have read this inode, we can read its data by following the zones links, as explained below.

#### Reading data

Reading data works in exactly the same way for all types of files. Once we have the inode for the file or directory, we can read the zone pointers to get the data at the correct block, which would look someting like this in assembly:

``` nesasm
lda #>(INODE + $0E)    ; get the zone 0 low byte
sta ZP_POINTER     ; store it in a zeropage pointer low byte
lda #>(INODE + $0F)    ; get the zone 0 high byte
sta ZP_POINTER + 1    ; store it in a zeropage pointer high byte
; we now have the address where we will find the zone to read in ZP_POINTER
ldy #0
lda (MINIX_PTR),y         ; we copy that data to the block to read
sta MINIX_CURRENT_BLOCK
iny
lda (MINIX_PTR), y
sta MINIX_CURRENT_BLOCK+1
jsr minix_read_block   ; and trigger a read of the corresponding minix block
```

The actual code is more complex than that, because it allows for reading from any of the 7 direct zones. (indirect zones are not handled for now).

Like all other directories, the root directory data consists entirely of "directory entries"

#### Directory entries

The data for a directory is a succession of directory entries, which occupy 32 bytes each and look like this :

<table>
<thead>
<tr>
<th colspan="17" align="center">
MINIX Directory entry layout
</th>
</tr>
<tr>
<td></td>
<td>$00</td><td>$01</td><td>$02</td><td>$03</td><td>$04</td><td>$05</td><td>$06</td><td>$07</td><td>$08</td><td>$09</td><td>$0A</td><td>$0B</td><td>$0C</td><td>$0D</td><td>$0E</td><td>$0F</td>
</tr>
</thead>
<tbody>
<tr>
<td>$00</td><td colspan="2">INODE</td><td colspan="14">FILENAME</td>
</tr>
<tr>
<td>$10</td><td colspan="16">FILENAME (cont.)</td>
</tr>
</tbody>
</table>

As you can see, the inode is a 16 bit number, and the filename has a maximum of 30 characters.

The first two entries in a directory are always `.` and `..` which represent the current directory and the parent directory respectively. For the root directory, these two entries point to the same inode.

#### Reading a file

Reading a file follows the same process as reading the root directory, expect we first need to get the inode for the file we are interested in.

To do this, we will walk all directory entries of the directory until we find the one we are searching for, or until we get to an entry where the inode is 0, in which case it signals the end of the directory.

Once we have the inode number for the file we are interested in, we can read it and get the data from the zones defined within it as discussed earlier.

#### Conclusion

This blog post stops here where we can sucessfully read data from a MINIX 1 filesystem, but I will probably keep working on it to add write access to the filesystem as well.

You can get the full source to allow you to read data from a MINIX filesystem on a 65C02 in [minix.txt](/img/minix.txt)

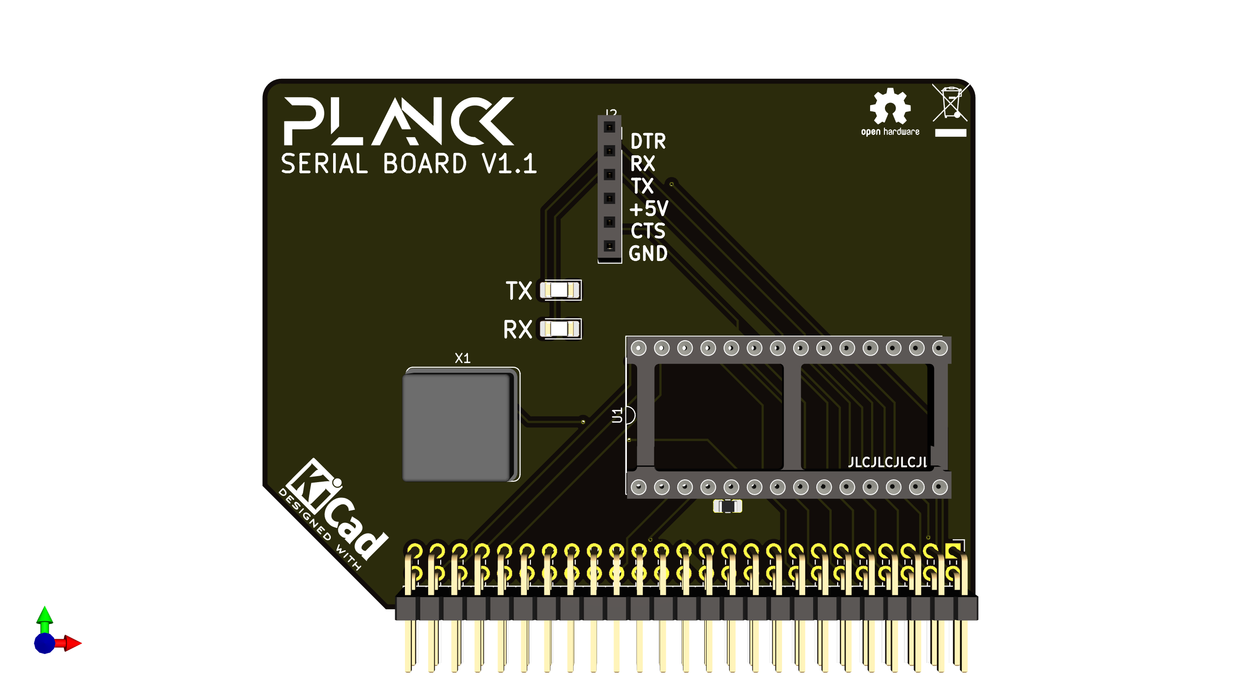
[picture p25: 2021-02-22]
Hardware/serial_board/serial_board.png

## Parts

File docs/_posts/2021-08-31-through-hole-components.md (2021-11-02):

---
layout: post
title:  "Redesigning for through hole components"
image: /img/io_board.png
---

So feedback I received regarding the Planck 6502 computer is that some people are not comfortable soldering surface mount components by hand. I originally used surface mount components to save board space and because I find the larger ones reasonably easy to solder. Also, they are cheaper than through hole components.

However, I understand that people with poor vision or little soldering experience may not feel the same way I do, which is why I decided to redesign all the board with through hole components.

Here is a before and after of the IO board for example.

Before : 
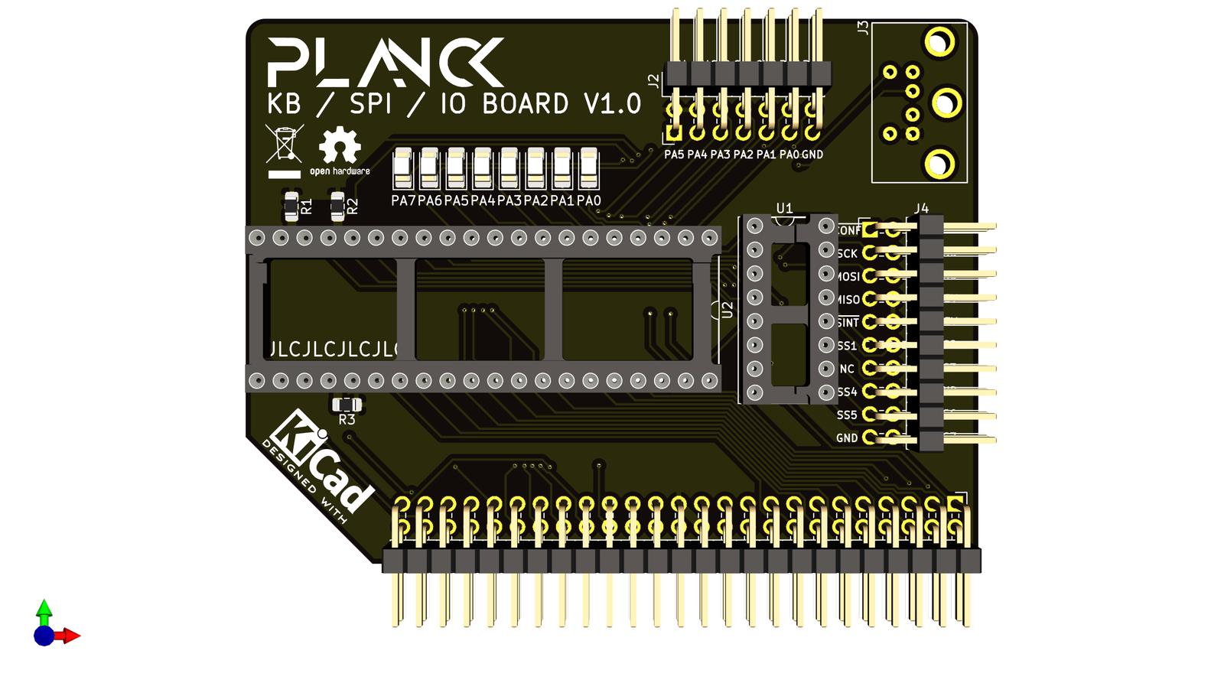
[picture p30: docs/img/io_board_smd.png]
SMD components


After : 
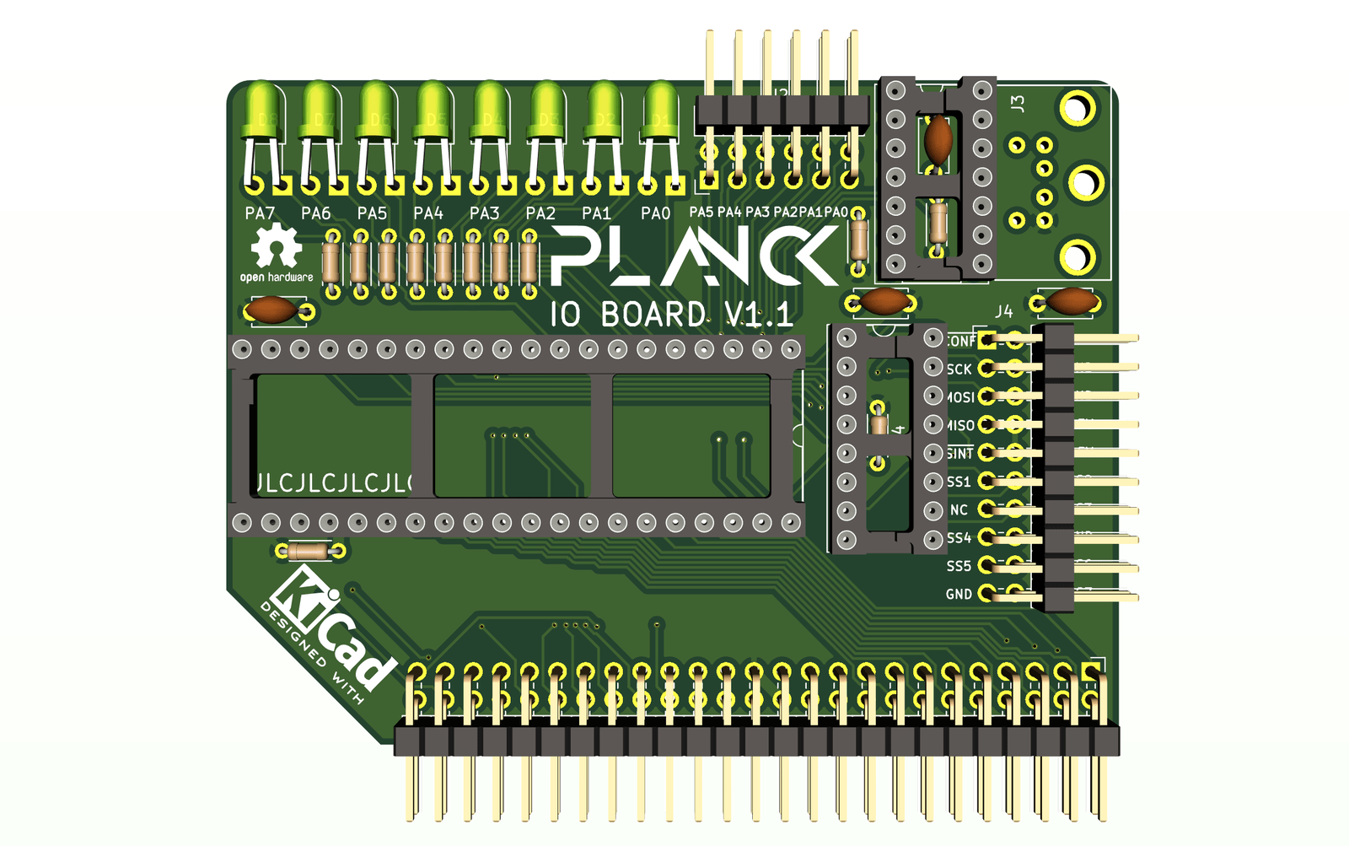
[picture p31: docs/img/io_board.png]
Through hole components


And (almost) everything fits. I had to reduce the parallel port slightly by removing one ground and one 5V pin, but otherwise, it's exactly the same.

I carried out the same process for all the boards, but the IO one was by far the most difficult.

So there you are, if you are wary of surface mount soldering for any reason, the new version should alleviate this problem.

And by the way, I am planning on opening a [Tindie store](https://www.tindie.com/stores/jfoucher/) soon to sell this computer. So if you are interested in buying the Planck computer, please hang tight while I set the store up.

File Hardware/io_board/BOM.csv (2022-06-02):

Ref | Qnty | Value | Cmp name | Footprint | Description | Vendor
C1, C2, C4, | 3 | 10n | C_Small | Capacitor_THT:C_Disc_D4.7mm_W2.5mm_P5.00mm | Unpolarized capacitor, small symbol
C3, | 1 | 100n | C_Small | Capacitor_THT:C_Disc_D4.7mm_W2.5mm_P5.00mm | Unpolarized capacitor, small symbol
D1, D2, D3, D4, D5, D6, D7, D8, | 8 | LED | LED | LED_THT:LED_D3.0mm_Horizontal_O3.81mm_Z6.0mm | Light emitting diode
J1, | 1 | Conn_01x40 | Conn_02x25_Odd_Even | Connector_PinHeader_2.54mm:PinHeader_2x25_P2.54mm_Horizontal | Generic connector, double row, 02x25, odd/even pin numbering scheme (row 1 odd numbers, row 2 even numbers)
J2, | 1 | Conn_02x06_Odd_Even | Conn_02x06_Odd_Even | Connector_PinHeader_2.54mm:PinHeader_2x06_P2.54mm_Horizontal | Generic connector, double row, 02x06, odd/even pin numbering scheme (row 1 odd numbers, row 2 even numbers)
J3, | 1 | Mini-DIN-6 | Mini-DIN-6 | mini-din:MINI-DIN-6-FULL-SHIELD | 6-pin Mini-DIN connector
J4, | 1 | Conn_02x10_Odd_Even | Conn_02x10_Odd_Even | Connector_PinHeader_2.54mm:PinHeader_2x10_P2.54mm_Horizontal | Generic connector, double row, 02x10, odd/even pin numbering scheme (row 1 odd numbers, row 2 even numbers)
R1, R2, | 2 | 1k | R_Small | Resistor_THT:R_Axial_DIN0207_L6.3mm_D2.5mm_P7.62mm_Horizontal | Resistor, small symbol
R3, R4, | 2 | 10k | R_Small | Resistor_THT:R_Axial_DIN0207_L6.3mm_D2.5mm_P7.62mm_Horizontal | Resistor, small symbol
R5, R6, R7, R8, R9, R10, R11, R12, | 8 | 470R | R_Small | Resistor_THT:R_Axial_DIN0207_L6.3mm_D2.5mm_P7.62mm_Horizontal | Resistor, small symbol
U1, | 1 | 74LS138 | 74LS138 | Package_DIP:DIP-16_W7.62mm_Socket | Decoder 3 to 8 active low outputs
U2, | 1 | W65C22NxP | W65C22NxP | Package_DIP:DIP-40_W15.24mm_Socket | W65C22N CMOS Versatile Interface Adapter (VIA), 20-pin I/O, 2 Timer/Counters, NMOS-Compatible, DIP-40
U3, | 1 | 74LS14 | 74LS14 | Package_DIP:DIP-14_W7.62mm_Socket | Hex inverter schmitt trigger

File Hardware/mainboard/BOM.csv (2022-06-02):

Ref | Qnty | Value | Cmp name | Footprint | Description | Vendor
C1, C3, C7, C8, C10, C11, | 6 | 1u | C_Small | Capacitor_THT:C_Disc_D4.3mm_W1.9mm_P5.00mm | Unpolarized capacitor, small symbol
C2, C4, C5, C9, C12, C14, C15, C16, C17, | 9 | 10n | C_Small | Capacitor_THT:C_Disc_D4.3mm_W1.9mm_P5.00mm | Unpolarized capacitor, small symbol
C6, | 1 | 47n | C_Small | Capacitor_THT:C_Disc_D4.3mm_W1.9mm_P5.00mm | Unpolarized capacitor, small symbol
C13, | 1 | 47u | C_Small | Capacitor_THT:CP_Radial_D6.3mm_P2.50mm | Unpolarized capacitor, small symbol
D1, | 1 | LED | LED | LED_THT:LED_D3.0mm | Light emitting diode
D2, D3, D4, D5, D6, D7, D8, | 7 | 1N4148 | D | Diode_THT:D_DO-35_SOD27_P7.62mm_Horizontal | Diode
H1, H2, H3, H5, H6, | 5 | MountingHole_Pad | MountingHole_Pad | MountingHole:MountingHole_3.2mm_M3_Pad | Mounting Hole with connection
J1, | 1 | USB_B_Micro | USB_B_Micro-Connector | Connector_USB:USB_Micro-B_Molex-105017-0001
J2, | 1 | Conn_02x02_Odd_Even | Conn_02x02_Odd_Even | Connector_PinHeader_2.54mm:PinHeader_2x02_P2.54mm_Vertical | Generic connector, double row, 02x02, odd/even pin numbering scheme (row 1 odd numbers, row 2 even numbers), script generated (kicad-library-utils/schlib/autogen/connector/)
J3, | 1 | Conn_01x06 | Conn_01x06 | Connector_PinSocket_2.54mm:PinSocket_1x06_P2.54mm_Vertical | Generic connector, single row, 01x06, script generated (kicad-library-utils/schlib/autogen/connector/)
J4, | 1 | Conn_01x14 | Conn_01x14 | Connector_PinSocket_2.54mm:PinSocket_1x14_P2.54mm_Vertical | Generic connector, single row, 01x14, script generated (kicad-library-utils/schlib/autogen/connector/)
LED1, LED2, LED3, LED4, | 4 | LED | LED | LED_THT:LED_D3.0mm | Light emitting diode
NMI1, | 1 | SW_Push | SW_Push | Button_Switch_THT:SW_PUSH_6mm | Push button switch, generic, two pins
R1, R8, R15, R23, R24, R25, R26, | 7 | 10k | R_Small | Resistor_THT:R_Axial_DIN0207_L6.3mm_D2.5mm_P7.62mm_Horizontal | Resistor, small symbol
R2, R3, R4, R5, R6, R14, R17, R18, R21, R22, | 10 | 1k | R_Small | Resistor_THT:R_Axial_DIN0207_L6.3mm_D2.5mm_P7.62mm_Horizontal | Resistor, small symbol
R9, R10, R11, R12, R13, | 5 | 470R | R_Small | Resistor_THT:R_Axial_DIN0207_L6.3mm_D2.5mm_P7.62mm_Horizontal | Resistor, small symbol
R16, | 1 | 4.7k | R_Small | Resistor_THT:R_Axial_DIN0207_L6.3mm_D2.5mm_P7.62mm_Horizontal | Resistor, small symbol
R27, | 1 | 10k | R_Small | Resistor_THT:R_Axial_DIN0204_L3.6mm_D1.6mm_P5.08mm_Horizontal | Resistor, small symbol
RESET1, | 1 | SW_Push | SW_Push | Button_Switch_THT:SW_PUSH_6mm | Push button switch, generic, two pins
SLOT0, SLOT1, SLOT2, SLOT3, SLOT4, SLOT5, | 6 | Conn_01x40 | Conn_02x25_Odd_Even | Connector_PinSocket_2.54mm:PinSocket_2x25_P2.54mm_Vertical | Generic connector, double row, 02x25, odd/even pin numbering scheme (row 1 odd numbers, row 2 even numbers), script generated (kicad-library-utils/schlib/autogen/connector/)
SW1, | 1 | SW_SPST | SW_SPST | Button_Switch_THT:SW_E-Switch_EG1271_DPDT | Single Pole Single Throw (SPST) switch
U1, | 1 | 74AC161 | 74LS161 | Package_DIP:DIP-16_W7.62mm_Socket | Synchronous 4-bit programmable binary Counter
U2, U3, | 2 | MAX811SEUS-T | MAX811SEUS-T | Package_TO_SOT_SMD:SOT-143 | Power supply supervisor, Manual reset, Threshold 2.93V, SOT-143
U4, | 1 | PAL24 | PAL24 | Package_DIP:DIP-24_W7.62mm_Socket | generic 24-pin Programmable Array Logic (PAL) device
U5, | 1 | GAL16V8 | GAL16V8 | Package_DIP:DIP-20_W7.62mm_Socket | Programmable Logic Array, DIP-20/SOIC-20/PLCC-20
U6, | 1 | W65C02SxP | W65C02SxP | Package_DIP:DIP-40_W15.24mm_Socket | W65C02S 8-bit CMOS General Purpose Microprocessor, DIP-40
U7, | 1 | HM62256BLP | HM62256BLP | Package_DIP:DIP-28_W7.62mm_Socket | 32,768-word × 8-bit High Speed CMOS Static RAM, 70ns, DIP-28
U8, | 1 | 28C256 | 28C256 | Package_DIP:DIP-28_W15.24mm_Socket | Paged Parallel EEPROM 256Kb (32K x 8), DIP-28/SOIC-28
U9, | 1 | W65C51NxP | W65C51NxP | Package_DIP:DIP-28_W15.24mm_Socket | W65C51N CMOS Asynchronous Communication Interface Adapter (ACIA), Serial UART, DIP-28
X1, | 1 | 24MHz | CXO_DIP8 | Oscillator:Oscillator_DIP-8 | Crystal Clock Oscillator, DIP8-style metal package
X3, | 1 | 1.8432MHz | CXO_DIP8 | Oscillator:Oscillator_DIP-8 | Crystal Clock Oscillator, DIP8-style metal package

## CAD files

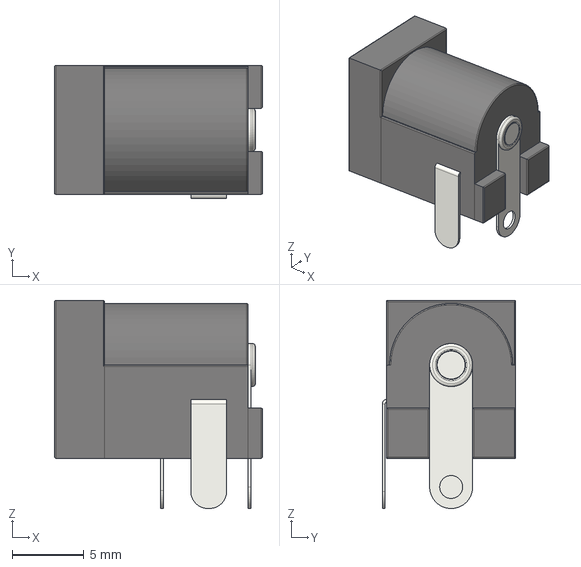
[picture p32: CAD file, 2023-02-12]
Hardware/mainboard/3D/barrel_jack.step
14.5 x 9.30 x 14.5 mm

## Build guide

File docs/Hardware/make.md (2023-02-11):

---
layout: board
short_title: Make your own board
title: Make your own Planck 6502 board
design_files: https://gitlab.com/planck-6502/planck-6502/-/tree/main/Hardware/template
order: 999
status: prod
---

To create your own Planck 6502 expansion board, you can use the provided expansion board template (see **Design files** above)

This Kicad project provides a base schematic and board layout for you start designing your own board.

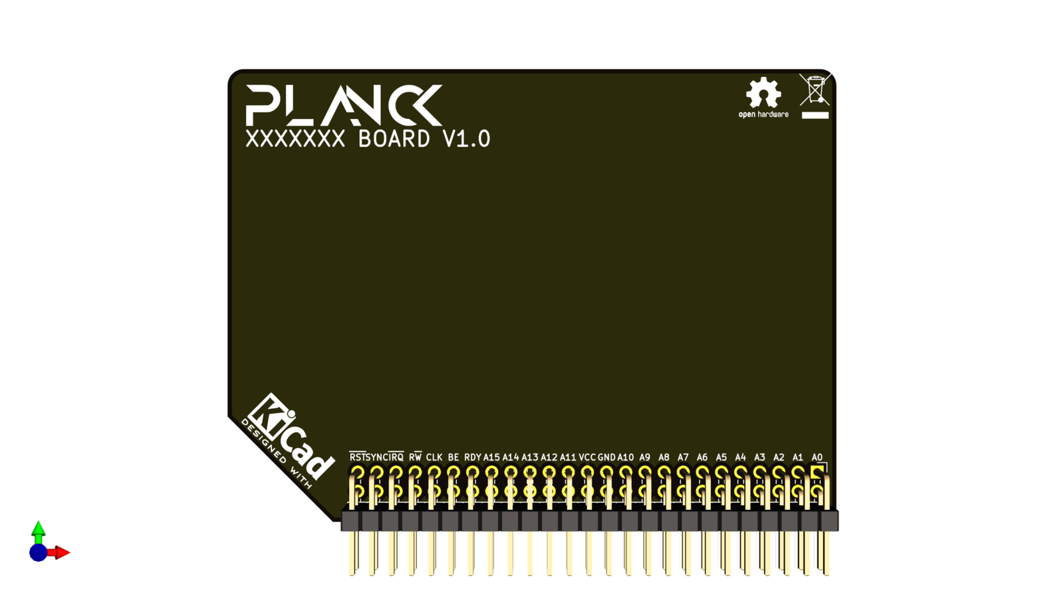
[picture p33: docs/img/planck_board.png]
Planck extension board template


Of course, you can also create an extension card using some prototype board and a 2x25 pins right angle header.
Actually I would strongly recommend you do that before having your PCB fabricated.

Alternatively, you could also get a few [prototype boards](/Hardware/proto) fabricated to be able to create many boards or refine designs to your heart's content.

For example, here is the prototype of the [OPL2 board](/Hardware/opl2)

LCD board prototype

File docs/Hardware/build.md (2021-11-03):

---
layout: page
short_title: Build Guide
title: Building the computer
order: 10
---

Here is the print version of [the build guide](/Planck 6502 build guide.pdf) I include with the kit.

The computer motherboard as well as all expansion boards not marked as "deprecated" have been redesigned using through hole components almost exclusively.

A build video is coming soon, but for now just solder the lowest components first, such as capacitors and resistors, and progress to the higher components at the end of the build.

The resistors should be placed as follows : 

 - R22, R21, R18, R17, R14, R6, R5, R4, R3, R2 have 1 kΩ value
 - R16 has 2.2 kΩ value
 - R13, R12, R11, R10, R9 have 330 Ω value
 - R27, R26, R25, R24, R23, R15, R8, R1 have 10 kΩ value

There are two types of capacitors: the cylindrical one is called electrolytic and should be placed near the power plug
The other should be placed as follows : the big ones next to the expansion slots, and the small ones near the chips.

Place the 1.8432 MHz oscillator in the footprint that reads "SERIAL CLOCK"
Place the 24 MHz oscillator in the footprint marked "MAIN CLOCK"

All other components have only one place where they can fit, so solder away. Just make sure you put the diodes and the LEDs the right way around.

## Finishing up and testing

Now that everything is soldered up, all that's left to do is to plug the chips in their respective sockets and give the board a test.

First check with a multimeter that you do not have a short between ground and VCC. Give a thorough visual inspection to the board to make sure that all solder joints are ok and that no bridging between pins occurs. Touch up where necessary.

Then if everything looks ok, you are ready to power up the board and test its functionality. It's time to head on over to [the software part of this documentation](/Software)

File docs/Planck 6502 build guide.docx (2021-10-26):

# Planck 6502 build guide

## Soldering

The resistors should be placed as follows:

- R22, R21, R18, R17, R14, R6, R5, R4, R3, R2 have 1 kΩ value
- R16 has 2.2 kΩ value
- R13, R12, R11, R10, R9 have 330 Ω value
- R27, R26, R25, R24, R23, R15, R8, R1 have 10 kΩ value

There are two types of capacitors: the cylindrical one is called electrolytic and should be placed near the power plug

The other ones should be placed as follows: the big ones next to the expansion slots, and the small ones near the chips.

Place the 1.8432 MHz oscillator in the footprint that reads "SERIAL CLOCK"

Place the 24 MHz oscillator in the footprint marked "MAIN CLOCK"

All other components have only one place where they can fit, so solder away. Just make sure you put the diodes and the LEDs the right way around.

## Finishing up and testing

Now that everything is soldered up, all that's left to do is to plug the chips in their respective sockets and give the board a test.

First check with a multimeter that you do not have a short between ground and VCC. Give a thorough visual inspection to the board to make sure that all solder joints are ok and that no bridging between pins occurs. Touch up where necessary.

You should now be able to connect your TTL serial to USB adapter to the pins in the bottom right of the Planck Computer. Note that only 3 pins are necessary: TX, RX and GROUND. RX on the Planck should be connected to TX on the adapter, and TX on the Planck should be connected to RX on the adapter.

If you have any issue at all, you can contact me by email at jfoucher@6px.eu

Enjoy your new retro-computer!

https://planck6502.com/build

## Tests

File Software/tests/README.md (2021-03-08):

# Test code

In this folder you will find some assembly code to test various expansion cards.

To assemble, install ca65 and run the following command in this folder:

`cl65 -t none --cpu 65C02 -C planck.cfg -o a.out -l ${file}.lst ${file}.s`

Where `${file}` is the file name you want to assemble.

You can then burn `a.out` to your EEPROM.

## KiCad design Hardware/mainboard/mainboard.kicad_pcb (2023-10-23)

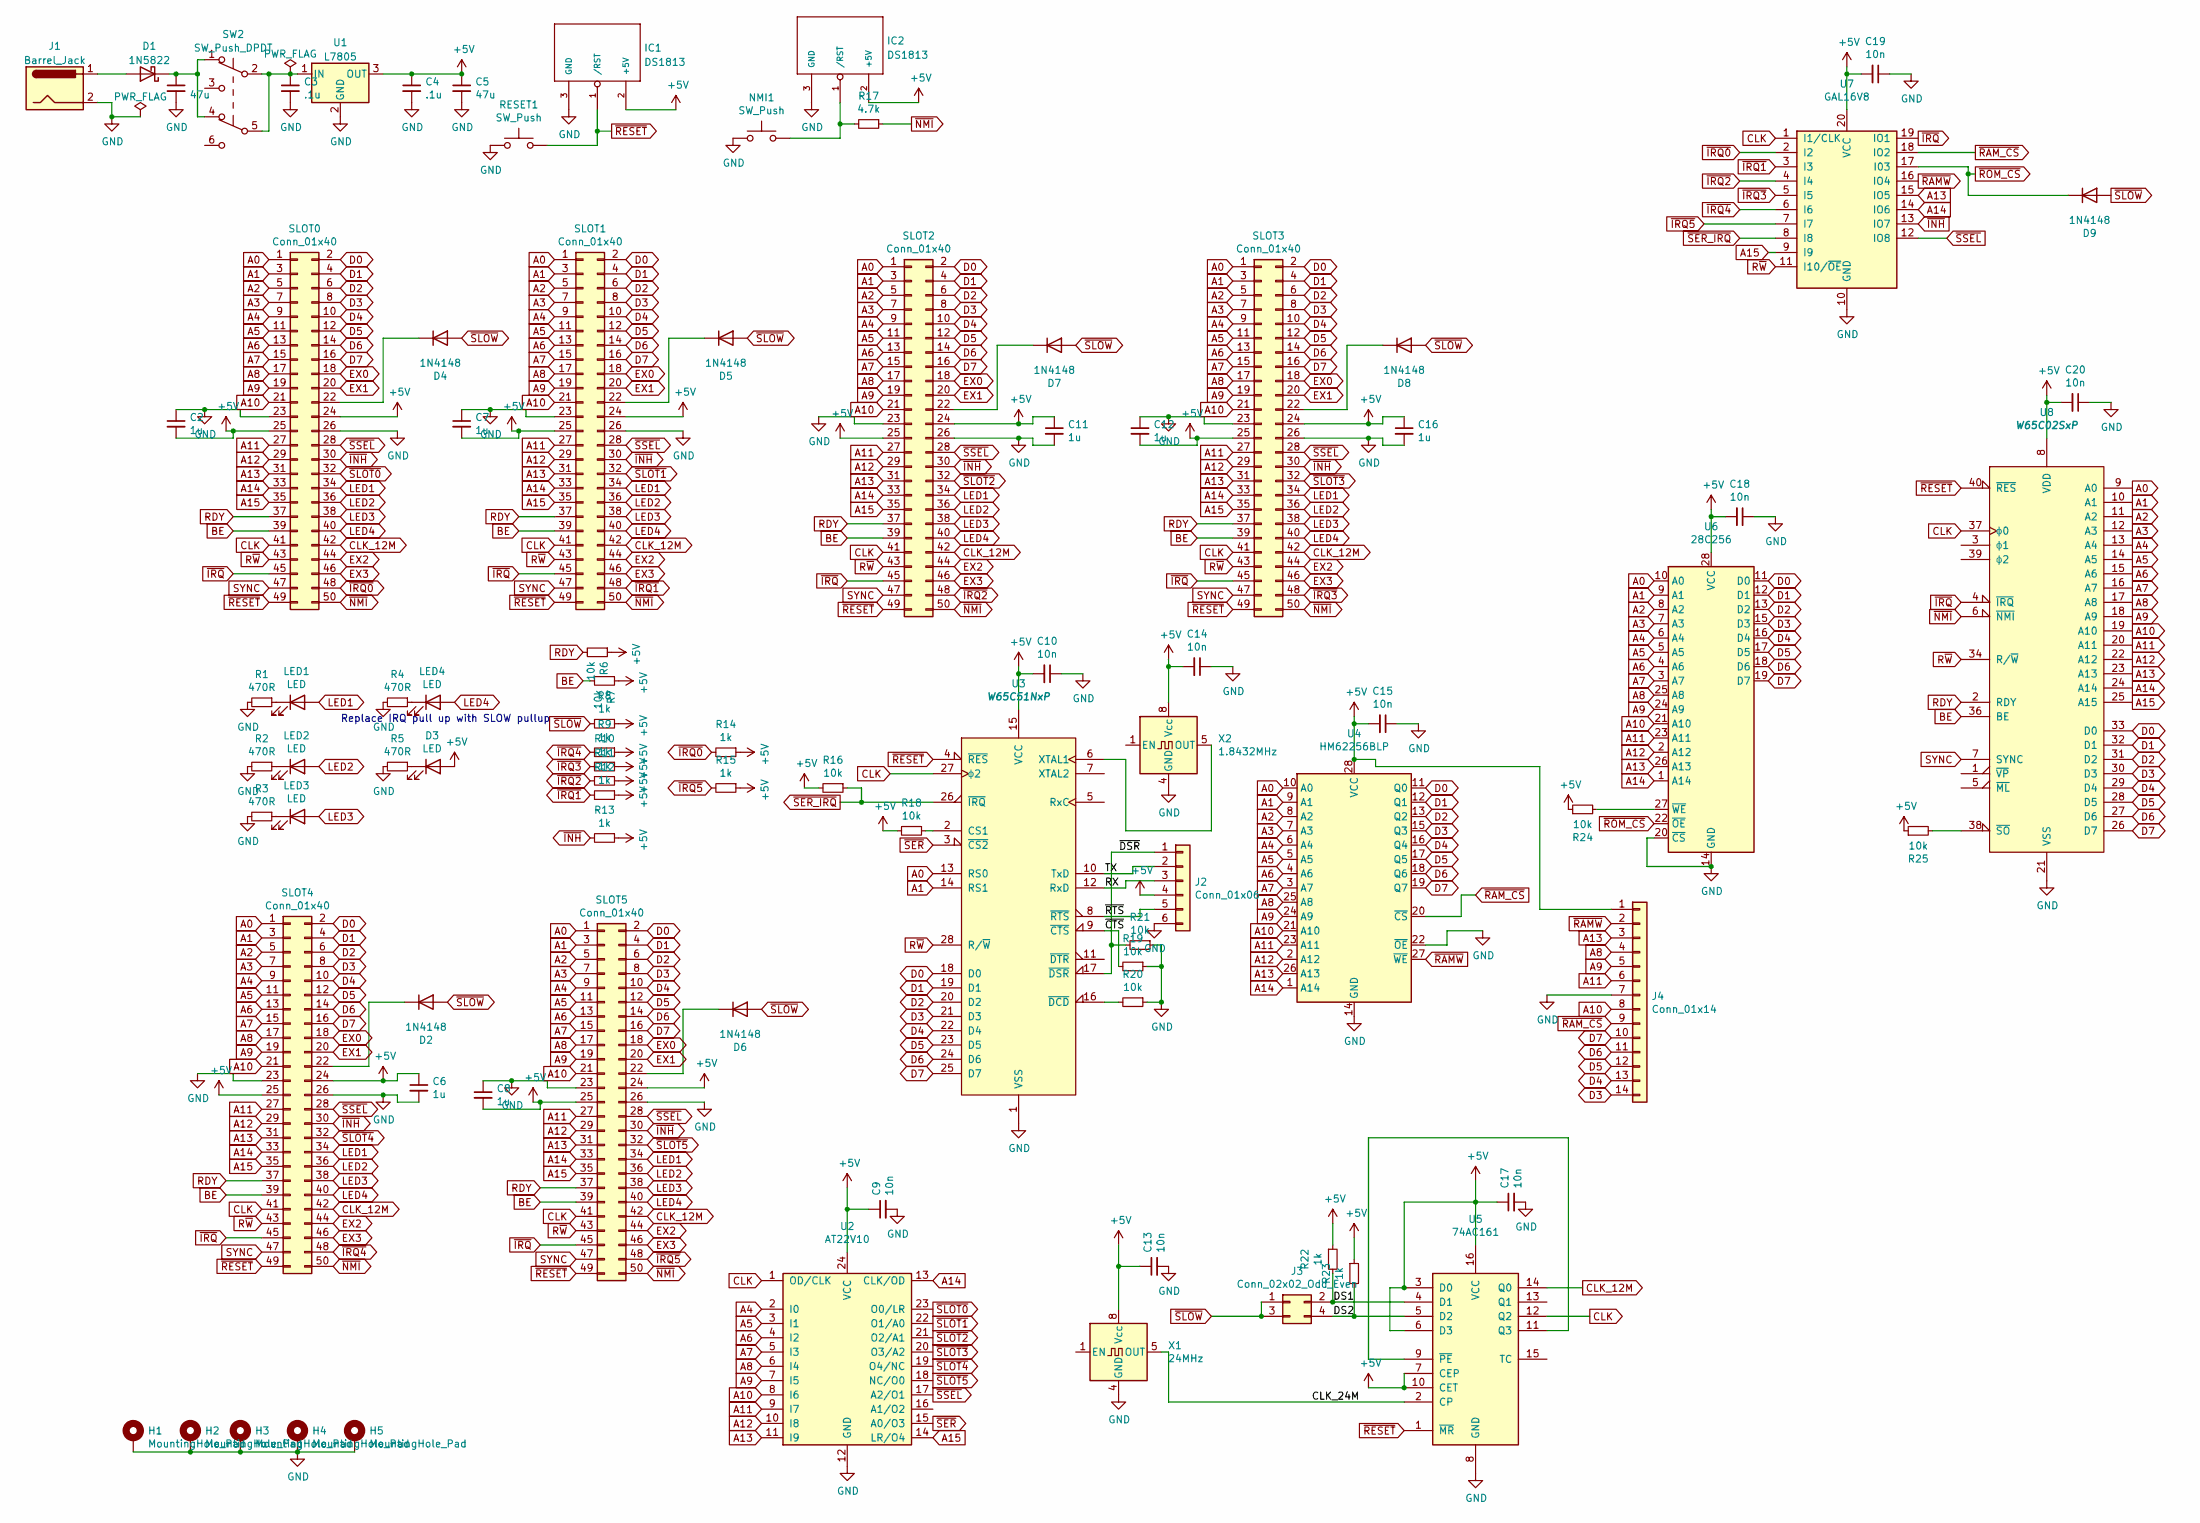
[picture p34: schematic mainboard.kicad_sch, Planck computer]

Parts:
C1, C5: 47u; CP_Radial_D4.0mm_P2.00mm
C2, C6, C7, C8, C11, C12, C16: 1u; C_Disc_D4.3mm_W1.9mm_P5.00mm
C3, C4: .1u; C_Disc_D4.3mm_W1.9mm_P5.00mm
C9, C10, C13, C14, C15, C17, C18, C19, C20: 10n; C_Disc_D4.3mm_W1.9mm_P5.00mm
D1: 1N5822; D_DO-201AD_P15.24mm_Horizontal
D2, D4, D5, D6, D7, D8, D9: 1N4148; D_DO-35_SOD27_P7.62mm_Horizontal
D3: LED; LED_D3.0mm
H1, H2, H3, H4, H5: MountingHole_Pad; MountingHole_3.2mm_M3_Pad
IC1, IC2: DS1813; TO-92_Inline_Wide
J1: Barrel_Jack; BarrelJack_Horizontal
J2: Conn_01x06; PinSocket_1x06_P2.54mm_Vertical
J3: Conn_02x02_Odd_Even; PinHeader_2x02_P2.54mm_Vertical
J4: Conn_01x14; PinSocket_1x14_P2.54mm_Vertical
LED1, LED2, LED3, LED4: LED; LED_D3.0mm
NMI1: SW_Push; SW_PUSH_6mm
R1, R2, R3, R4, R5: 470R; R_Axial_DIN0207_L6.3mm_D2.5mm_P7.62mm_Horizontal
R6, R7, R16, R18, R19, R20, R21, R24, R25: 10k; R_Axial_DIN0207_L6.3mm_D2.5mm_P7.62mm_Horizontal
R8, R9, R10, R11, R12, R13, R14, R15, R22, R23: 1k; R_Axial_DIN0207_L6.3mm_D2.5mm_P7.62mm_Horizontal
R17: 4.7k; R_Axial_DIN0207_L6.3mm_D2.5mm_P7.62mm_Horizontal
RESET1: SW_Push; SW_PUSH_6mm
SLOT0, SLOT1, SLOT2, SLOT3, SLOT4, SLOT5: Conn_01x40; PinSocket_2x25_P2.54mm_Vertical
SW2: SW_Push_DPDT; SW_E-Switch_EG1271_SPDT
U1: L7805; TO-220-3_Vertical
U2: AT22V10; DIP-24_W7.62mm_Socket
U3: W65C51NxP; DIP-28_W15.24mm_Socket
U4: HM62256BLP; DIP-28_W7.62mm_Socket
U5: 74AC161; DIP-16_W7.62mm_Socket
U6: 28C256; DIP-28_W15.24mm_Socket
U7: GAL16V8; DIP-20_W7.62mm_Socket
U8: W65C02SxP; DIP-40_W15.24mm_Socket
X1: 24MHz; Oscillator_DIP-8
X2: 1.8432MHz; Oscillator_DIP-8

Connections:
+5V: C2.2, C4.1, C5.1, C6.1, C7.2, C8.2, C9.1, C10.2, C11.1, C12.2, C13.1, C14.2, C15.2, C16.1, C17.1, C18.2, C19.2, C20.2, D3.2 (A), IC1.2 (+5V), IC2.2 (+5V), J2.4, J4.1, R6.1, R7.1, R8.1, R9.1, R10.1, R11.1, R12.1, R13.1, R14.1, R15.1, R16.2, R18.2, R22.1, R23.1, R24.1, R25.1, SLOT0.24, SLOT0.25, SLOT1.24, SLOT1.25, SLOT2.24, SLOT2.25, SLOT3.24, SLOT3.25, SLOT4.24, SLOT4.25, SLOT5.24, SLOT5.25, U1.3 (OUT), U2.24 (VCC), U3.15 (VCC), U4.28 (VCC), U5.3 (D0), U5.6 (D3), U5.7 (CEP), U5.10 (CET), U5.16 (VCC), U6.28 (VCC), U7.20 (VCC), U8.8 (VDD), X1.8 (Vcc), X2.8 (Vcc)
/CLK_24M: U5.2 (CP), X1.5 (OUT)
/DS1: J3.2, R22.2, U5.4 (D1)
/DS2: J3.4, R23.2, U5.5 (D2)
/RX: J2.3, U3.12 (RxD)
/TX: J2.2, U3.10 (TxD)
/~CTS: R19.2, U3.9 (~CTS)
/~DSR: J2.1, R21.2, U3.17 (~DSR)
/~RTS: J2.5, U3.8 (~RTS)
A0: SLOT0.1, SLOT1.1, SLOT2.1, SLOT3.1, SLOT4.1, SLOT5.1, U3.13 (RS0), U4.10 (A0), U6.10 (A0), U8.9 (A0)
A1: SLOT0.3, SLOT1.3, SLOT2.3, SLOT3.3, SLOT4.3, SLOT5.3, U3.14 (RS1), U4.9 (A1), U6.9 (A1), U8.10 (A1)
A2: SLOT0.5, SLOT1.5, SLOT2.5, SLOT3.5, SLOT4.5, SLOT5.5, U4.8 (A2), U6.8 (A2), U8.11 (A2)
A3: SLOT0.7, SLOT1.7, SLOT2.7, SLOT3.7, SLOT4.7, SLOT5.7, U4.7 (A3), U6.7 (A3), U8.12 (A3)
A4: SLOT0.9, SLOT1.9, SLOT2.9, SLOT3.9, SLOT4.9, SLOT5.9, U2.2 (I0), U4.6 (A4), U6.6 (A4), U8.13 (A4)
A5: SLOT0.11, SLOT1.11, SLOT2.11, SLOT3.11, SLOT4.11, SLOT5.11, U2.3 (I1), U4.5 (A5), U6.5 (A5), U8.14 (A5)
A6: SLOT0.13, SLOT1.13, SLOT2.13, SLOT3.13, SLOT4.13, SLOT5.13, U2.4 (I2), U4.4 (A6), U6.4 (A6), U8.15 (A6)
A7: SLOT0.15, SLOT1.15, SLOT2.15, SLOT3.15, SLOT4.15, SLOT5.15, U2.5 (I3), U4.3 (A7), U6.3 (A7), U8.16 (A7)
A8: J4.4, SLOT0.17, SLOT1.17, SLOT2.17, SLOT3.17, SLOT4.17, SLOT5.17, U2.6 (I4), U4.25 (A8), U6.25 (A8), U8.17 (A8)
A9: J4.5, SLOT0.19, SLOT1.19, SLOT2.19, SLOT3.19, SLOT4.19, SLOT5.19, U2.7 (I5), U4.24 (A9), U6.24 (A9), U8.18 (A9)
A10: J4.8, SLOT0.21, SLOT1.21, SLOT2.21, SLOT3.21, SLOT4.21, SLOT5.21, U2.8 (I6), U4.21 (A10), U6.21 (A10), U8.19 (A10)
A11: J4.6, SLOT0.27, SLOT1.27, SLOT2.27, SLOT3.27, SLOT4.27, SLOT5.27, U2.9 (I7), U4.23 (A11), U6.23 (A11), U8.20 (A11)
A12: SLOT0.29, SLOT1.29, SLOT2.29, SLOT3.29, SLOT4.29, SLOT5.29, U2.10 (I8), U4.2 (A12), U6.2 (A12), U8.22 (A12)
A13: J4.3, SLOT0.31, SLOT1.31, SLOT2.31, SLOT3.31, SLOT4.31, SLOT5.31, U2.11 (I9), U4.26 (A13), U6.26 (A13), U7.15 (IO5), U8.23 (A13)
A14: SLOT0.33, SLOT1.33, SLOT2.33, SLOT3.33, SLOT4.33, SLOT5.33, U2.13 (CLK/OD), U4.1 (A14), U6.1 (A14), U7.14 (IO6), U8.24 (A14)
A15: SLOT0.35, SLOT1.35, SLOT2.35, SLOT3.35, SLOT4.35, SLOT5.35, U2.14 (LR/O4), U7.9 (I9), U8.25 (A15)
BE: R7.2, SLOT0.39, SLOT1.39, SLOT2.39, SLOT3.39, SLOT4.39, SLOT5.39, U8.36 (BE)
CLK: SLOT0.41, SLOT1.41, SLOT2.41, SLOT3.41, SLOT4.41, SLOT5.41, U2.1 (OD/CLK), U3.27 (ϕ2), U5.12 (Q2), U7.1 (I1/CLK), U8.37 (ϕ0)
CLK_12M: SLOT0.42, SLOT1.42, SLOT2.42, SLOT3.42, SLOT4.42, SLOT5.42, U5.14 (Q0)
D0: SLOT0.2, SLOT1.2, SLOT2.2, SLOT3.2, SLOT4.2, SLOT5.2, U3.18 (D0), U4.11 (Q0), U6.11 (D0), U8.33 (D0)
D1: SLOT0.4, SLOT1.4, SLOT2.4, SLOT3.4, SLOT4.4, SLOT5.4, U3.19 (D1), U4.12 (Q1), U6.12 (D1), U8.32 (D1)
D2: SLOT0.6, SLOT1.6, SLOT2.6, SLOT3.6, SLOT4.6, SLOT5.6, U3.20 (D2), U4.13 (Q2), U6.13 (D2), U8.31 (D2)
D3: J4.14, SLOT0.8, SLOT1.8, SLOT2.8, SLOT3.8, SLOT4.8, SLOT5.8, U3.21 (D3), U4.15 (Q3), U6.15 (D3), U8.30 (D3)
D4: J4.13, SLOT0.10, SLOT1.10, SLOT2.10, SLOT3.10, SLOT4.10, SLOT5.10, U3.22 (D4), U4.16 (Q4), U6.16 (D4), U8.29 (D4)
D5: J4.12, SLOT0.12, SLOT1.12, SLOT2.12, SLOT3.12, SLOT4.12, SLOT5.12, U3.23 (D5), U4.17 (Q5), U6.17 (D5), U8.28 (D5)
D6: J4.11, SLOT0.14, SLOT1.14, SLOT2.14, SLOT3.14, SLOT4.14, SLOT5.14, U3.24 (D6), U4.18 (Q6), U6.18 (D6), U8.27 (D6)
D7: J4.10, SLOT0.16, SLOT1.16, SLOT2.16, SLOT3.16, SLOT4.16, SLOT5.16, U3.25 (D7), U4.19 (Q7), U6.19 (D7), U8.26 (D7)
EX0: SLOT0.18, SLOT1.18, SLOT2.18, SLOT3.18, SLOT4.18, SLOT5.18
EX1: SLOT0.20, SLOT1.20, SLOT2.20, SLOT3.20, SLOT4.20, SLOT5.20
EX2: SLOT0.44, SLOT1.44, SLOT2.44, SLOT3.44, SLOT4.44, SLOT5.44
EX3: SLOT0.46, SLOT1.46, SLOT2.46, SLOT3.46, SLOT4.46, SLOT5.46
GND: C1.2, C2.1, C3.2, C4.2, C5.2, C6.2, C7.1, C8.1, C9.2, C10.1, C11.2, C12.1, C13.2, C14.1, C15.1, C16.2, C17.2, C18.1, C19.1, C20.1, H1.1, H2.1, H3.1, H4.1, H5.1, IC1.3 (GND), IC2.3 (GND), J1.2, J2.6, J4.7, NMI1.1, R1.2, R2.2, R3.2, R4.2, R5.2, R19.1, R20.1, R21.1, RESET1.1, SLOT0.23, SLOT0.26, SLOT1.23, SLOT1.26, SLOT2.23, SLOT2.26, SLOT3.23, SLOT3.26, SLOT4.23, SLOT4.26, SLOT5.23, SLOT5.26, U1.2 (GND), U2.12 (GND), U3.1 (VSS), U4.14 (GND), U4.22 (~OE), U5.8 (GND), U6.14 (GND), U6.20 (~CS), U7.10 (GND), U8.21 (VSS), X1.4 (GND), X2.4 (GND)
LED1: LED1.2 (A), SLOT0.34, SLOT1.34, SLOT2.34, SLOT3.34, SLOT4.34, SLOT5.34
LED2: LED2.2 (A), SLOT0.36, SLOT1.36, SLOT2.36, SLOT3.36, SLOT4.36, SLOT5.36
LED3: LED3.2 (A), SLOT0.38, SLOT1.38, SLOT2.38, SLOT3.38, SLOT4.38, SLOT5.38
LED4: LED4.2 (A), SLOT0.40, SLOT1.40, SLOT2.40, SLOT3.40, SLOT4.40, SLOT5.40
unnamed: D1.2 (A), J1.1
unnamed: C1.1, D1.1 (K), SW2.1 (A), SW2.4 (A)
unnamed: D2.1 (K), SLOT4.22
unnamed: D3.1 (K), R5.1
unnamed: D4.1 (K), SLOT0.22
unnamed: D5.1 (K), SLOT1.22
unnamed: D6.1 (K), SLOT5.22
unnamed: D7.1 (K), SLOT2.22
unnamed: D8.1 (K), SLOT3.22
unnamed: IC2.1 (/RST), NMI1.2, R17.2
unnamed: LED1.1 (K), R1.1
unnamed: LED2.1 (K), R2.1
unnamed: LED3.1 (K), R3.1
unnamed: LED4.1 (K), R4.1
unnamed: C3.1, SW2.2 (B), SW2.5 (B), U1.1 (IN)
unnamed: R18.1, U3.2 (CS1)
unnamed: U3.6 (XTAL1), X2.5 (OUT)
unnamed: R20.2, U3.16 (~DCD)
unnamed: U5.9 (~PE), U5.11 (Q3)
unnamed: R24.2, U6.27 (~WE)
unnamed: R25.2, U8.38 (~SO)
RDY: R6.2, SLOT0.37, SLOT1.37, SLOT2.37, SLOT3.37, SLOT4.37, SLOT5.37, U8.2 (RDY)
R~W: SLOT0.43, SLOT1.43, SLOT2.43, SLOT3.43, SLOT4.43, SLOT5.43, U3.28 (R/~W), U7.11 (I10/~OE), U8.34 (R/~W)
SYNC: SLOT0.47, SLOT1.47, SLOT2.47, SLOT3.47, SLOT4.47, SLOT5.47, U8.7 (SYNC)
~INH: R13.2, SLOT0.30, SLOT1.30, SLOT2.30, SLOT3.30, SLOT4.30, SLOT5.30, U7.13 (IO7)
~IRQ0: R14.2, SLOT0.48, U7.2 (I2)
~IRQ1: R12.2, SLOT1.48, U7.3 (I3)
~IRQ2: R11.2, SLOT2.48, U7.4 (I4)
~IRQ3: R10.2, SLOT3.48, U7.5 (I5)
~IRQ4: R9.2, SLOT4.48, U7.6 (I6)
~IRQ5: R15.2, SLOT5.48, U7.7 (I7)
~IRQ: SLOT0.45, SLOT1.45, SLOT2.45, SLOT3.45, SLOT4.45, SLOT5.45, U7.19 (IO1), U8.4 (~IRQ)
~NMI: R17.1, SLOT0.50, SLOT1.50, SLOT2.50, SLOT3.50, SLOT4.50, SLOT5.50, U8.6 (~NMI)
~RAMW: J4.2, U4.27 (~WE), U7.16 (IO4)
~RAM_CS: J4.9, U4.20 (~CS), U7.18 (IO2)
~RESET: IC1.1 (/RST), RESET1.2, SLOT0.49, SLOT1.49, SLOT2.49, SLOT3.49, SLOT4.49, SLOT5.49, U3.4 (~RES), U5.1 (~MR), U8.40 (~RES)
~ROM_CS: D9.1 (K), U6.22 (~OE), U7.17 (I03)
~SER_IRQ: R16.1, U3.26 (~IRQ), U7.8 (I8)
~SER: U2.15 (A0/O3), U3.3 (~CS2)
~SLOT0: SLOT0.32, U2.23 (O0/LR)
~SLOT1: SLOT1.32, U2.22 (O1/A0)
~SLOT2: SLOT2.32, U2.21 (O2/A1)
~SLOT3: SLOT3.32, U2.20 (O3/A2)
~SLOT4: SLOT4.32, U2.19 (O4/NC)
~SLOT5: SLOT5.32, U2.18 (NC/O0)
~SLOW: D2.2 (A), D4.2 (A), D5.2 (A), D6.2 (A), D7.2 (A), D8.2 (A), D9.2 (A), J3.1, J3.3, R8.2
~SSEL: SLOT0.28, SLOT1.28, SLOT2.28, SLOT3.28, SLOT4.28, SLOT5.28, U2.17 (A2/O1), U7.12 (IO8)

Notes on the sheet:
Replace IRQ pull up with SLOW pullup

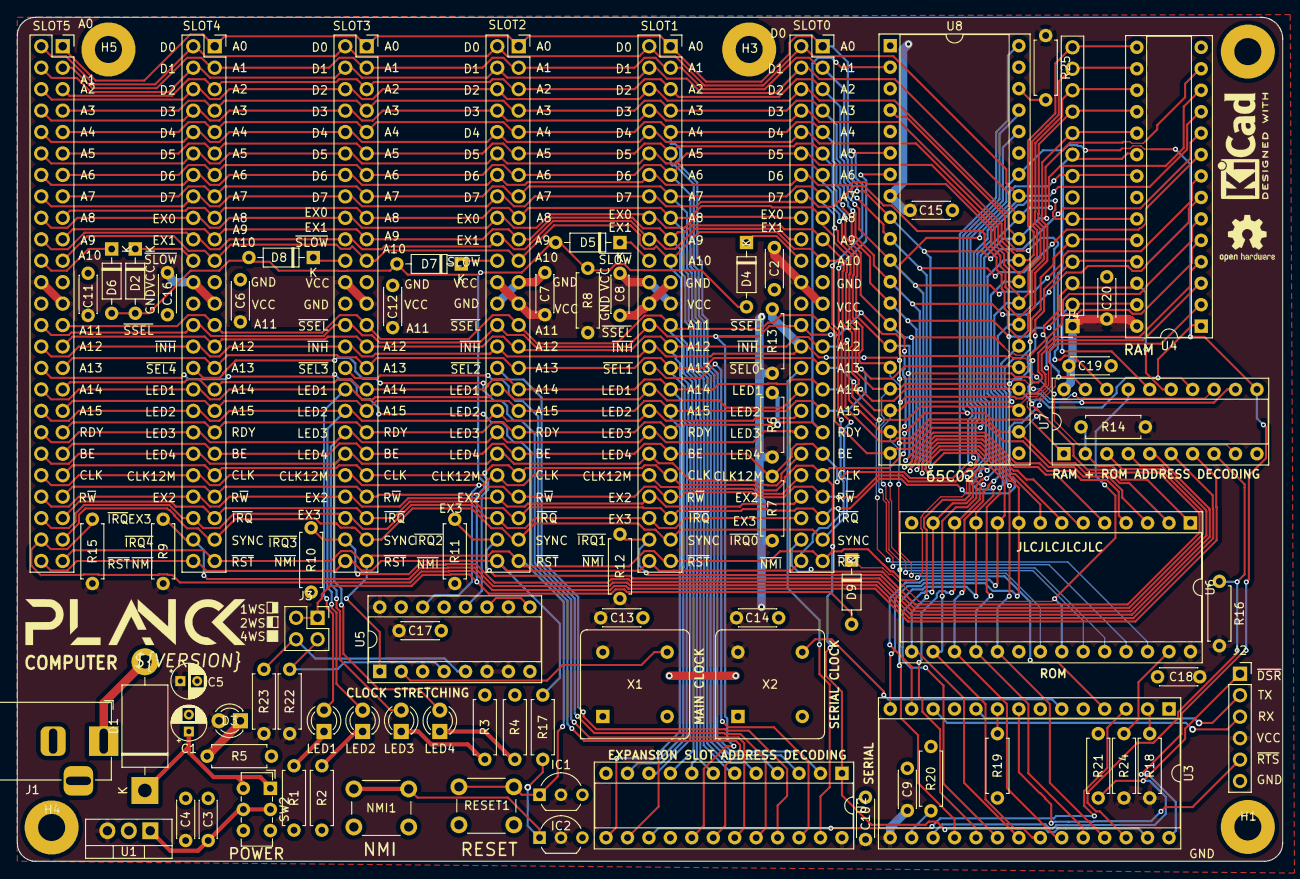
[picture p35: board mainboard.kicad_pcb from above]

Board: 2 copper layers, 149.9 x 99.9 mm, 88 parts (0 on the bottom side), 92 nets.

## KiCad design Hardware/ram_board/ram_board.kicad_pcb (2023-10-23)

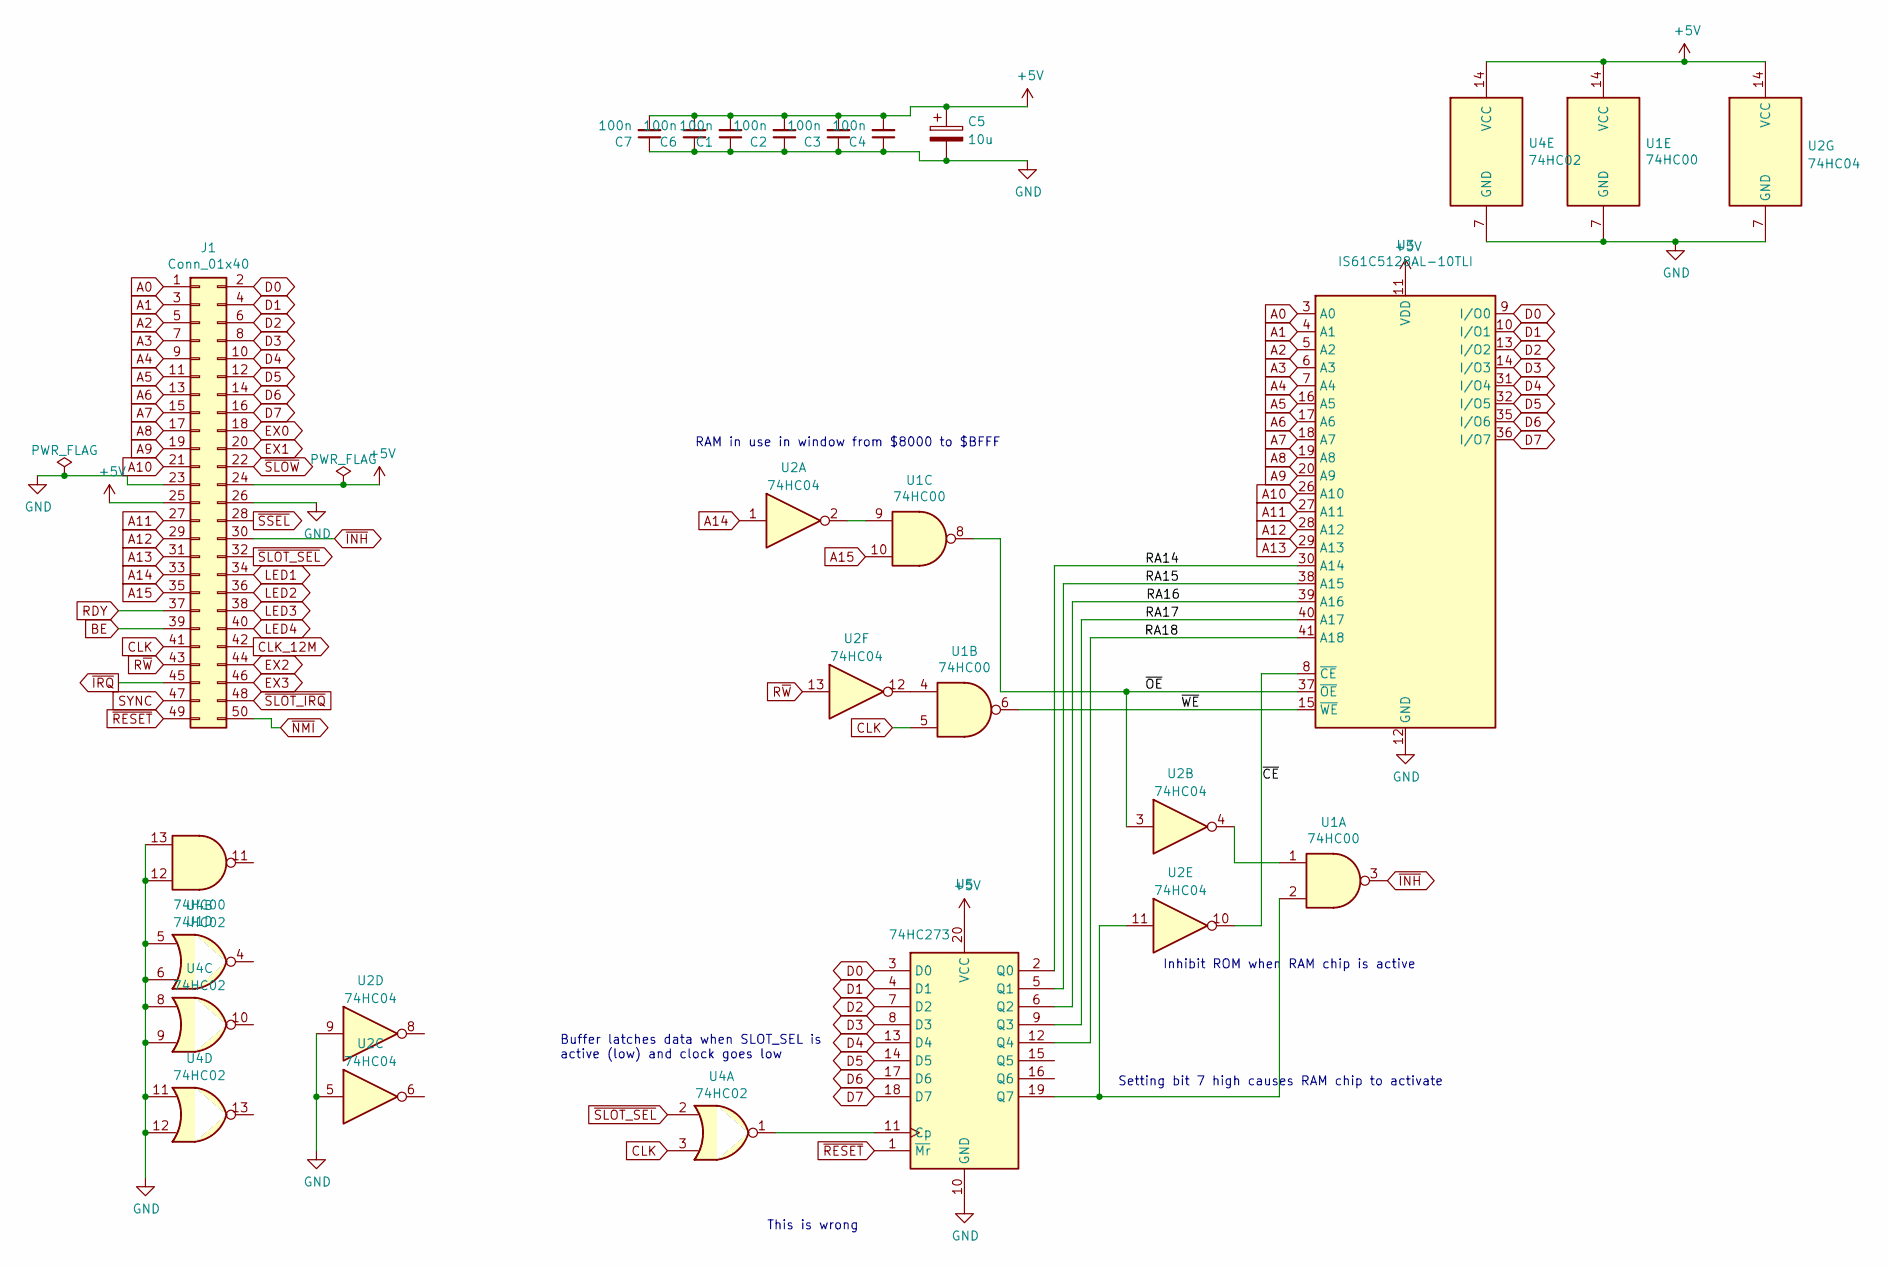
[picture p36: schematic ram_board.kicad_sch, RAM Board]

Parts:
C1, C2, C3, C4, C6, C7: 100n; C_Disc_D4.3mm_W1.9mm_P5.00mm
C5: 10u; C_Radial_D5.0mm_H11.0mm_P2.00mm
J1: Conn_01x40; PinHeader_2x25_P2.54mm_Horizontal
U1: 74HC00; DIP-14_W7.62mm_Socket
U2: 74HC04; DIP-14_W7.62mm_Socket
U3: IS61C5128AL-10TLI; TSOP-II-44_10.16x18.41mm_P0.8mm
U4: 74HC02; DIP-14_W7.62mm_Socket
U5: 74HC273; DIP-20_W7.62mm_Socket

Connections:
+5V: C1.2, C2.2, C3.2, C4.2, C5.1, C6.2, C7.2, J1.24, J1.25, U1.14 (VCC), U2.14 (VCC), U3.11 (VDD), U3.33 (VDD), U4.14 (VCC), U5.20 (VCC)
/RA14: U3.30 (A14), U5.2 (Q0)
/RA15: U3.38 (A15), U5.5 (Q1)
/RA16: U3.39 (A16), U5.6 (Q2)
/RA17: U3.40 (A17), U5.9 (Q3)
/RA18: U3.41 (A18), U5.12 (Q4)
/~CE: U2.10, U3.8 (~CE)
/~OE: U1.8, U2.3, U3.37 (~OE)
/~WE: U1.6, U3.15 (~WE)
A0: J1.1, U3.3 (A0)
A1: J1.3, U3.4 (A1)
A2: J1.5, U3.5 (A2)
A3: J1.7, U3.6 (A3)
A4: J1.9, U3.7 (A4)
A5: J1.11, U3.16 (A5)
A6: J1.13, U3.17 (A6)
A7: J1.15, U3.18 (A7)
A8: J1.17, U3.19 (A8)
A9: J1.19, U3.20 (A9)
A10: J1.21, U3.26 (A10)
A11: J1.27, U3.27 (A11)
A12: J1.29, U3.28 (A12)
A13: J1.31, U3.29 (A13)
A14: J1.33, U2.1
A15: J1.35, U1.10
BE: J1.39
CLK: J1.41, U1.5, U4.3
CLK_12M: J1.42
D0: J1.2, U3.9 (I/O0), U5.3 (D0)
D1: J1.4, U3.10 (I/O1), U5.4 (D1)
D2: J1.6, U3.13 (I/O2), U5.7 (D2)
D3: J1.8, U3.14 (I/O3), U5.8 (D3)
D4: J1.10, U3.31 (I/O4), U5.13 (D4)
D5: J1.12, U3.32 (I/O5), U5.14 (D5)
D6: J1.14, U3.35 (I/O6), U5.17 (D6)
D7: J1.16, U3.36 (I/O7), U5.18 (D7)
EX0: J1.18
EX1: J1.20
EX2: J1.44
EX3: J1.46
GND: C1.1, C2.1, C3.1, C4.1, C5.2, C6.1, C7.1, J1.23, J1.26, U1.7 (GND), U1.12, U1.13, U2.5, U2.7 (GND), U2.9, U3.12 (GND), U3.34 (GND), U4.5, U4.6, U4.7 (GND), U4.8, U4.9, U4.11, U4.12, U5.10 (GND)
LED1: J1.34
LED2: J1.36
LED3: J1.38
LED4: J1.40
unnamed: U1.1, U2.4
unnamed: U1.4, U2.12
unnamed: U1.9, U2.2
unnamed: U4.1, U5.11 (Cp)
unnamed: U1.2, U2.11, U5.19 (Q7)
RDY: J1.37
R~W: J1.43, U2.13
SYNC: J1.47
~INH: J1.30, U1.3
~IRQ: J1.45
~NMI: J1.50
~RESET: J1.49, U5.1 (~Mr)
~SLOT_IRQ: J1.48
~SLOT_SEL: J1.32, U4.2
~SLOW: J1.22
~SSEL: J1.28

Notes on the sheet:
Inhibit ROM when RAM chip is active
This is wrong
RAM in use in window from $8000 to $BFFF
Buffer latches data when SLOT_SEL is active (low) and clock goes low
Setting bit 7 high causes RAM chip to activate

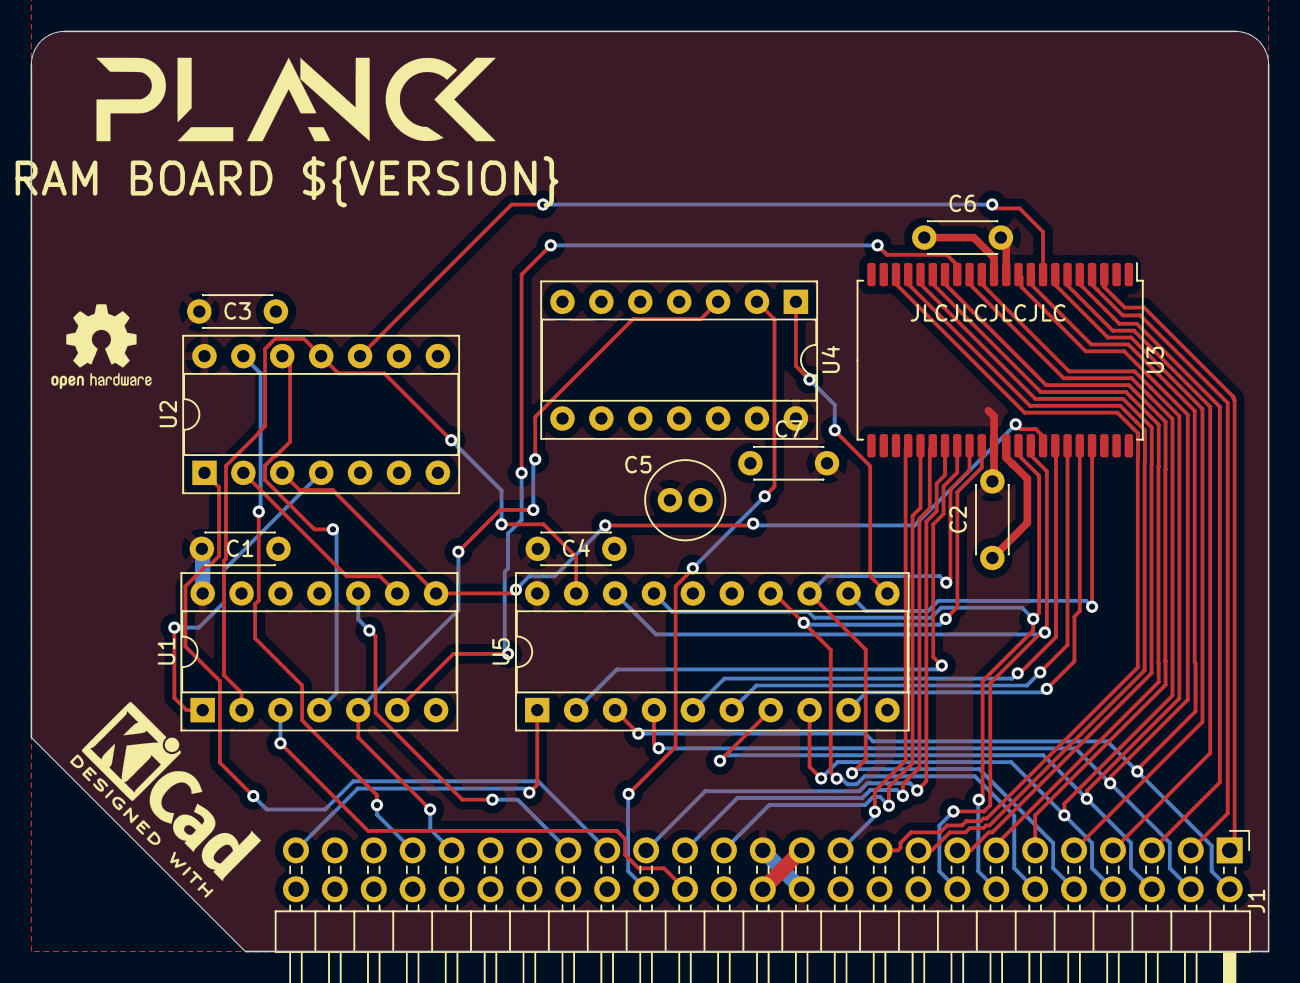
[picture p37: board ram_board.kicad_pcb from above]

Board: 2 copper layers, 80.8 x 60.1 mm, 16 parts (1 on the bottom side), 44 nets.

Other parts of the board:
LOGO, LOGO2: LOGO; logo
OSHW: OSHW-Logo2_7.3x6mm_SilkScreen

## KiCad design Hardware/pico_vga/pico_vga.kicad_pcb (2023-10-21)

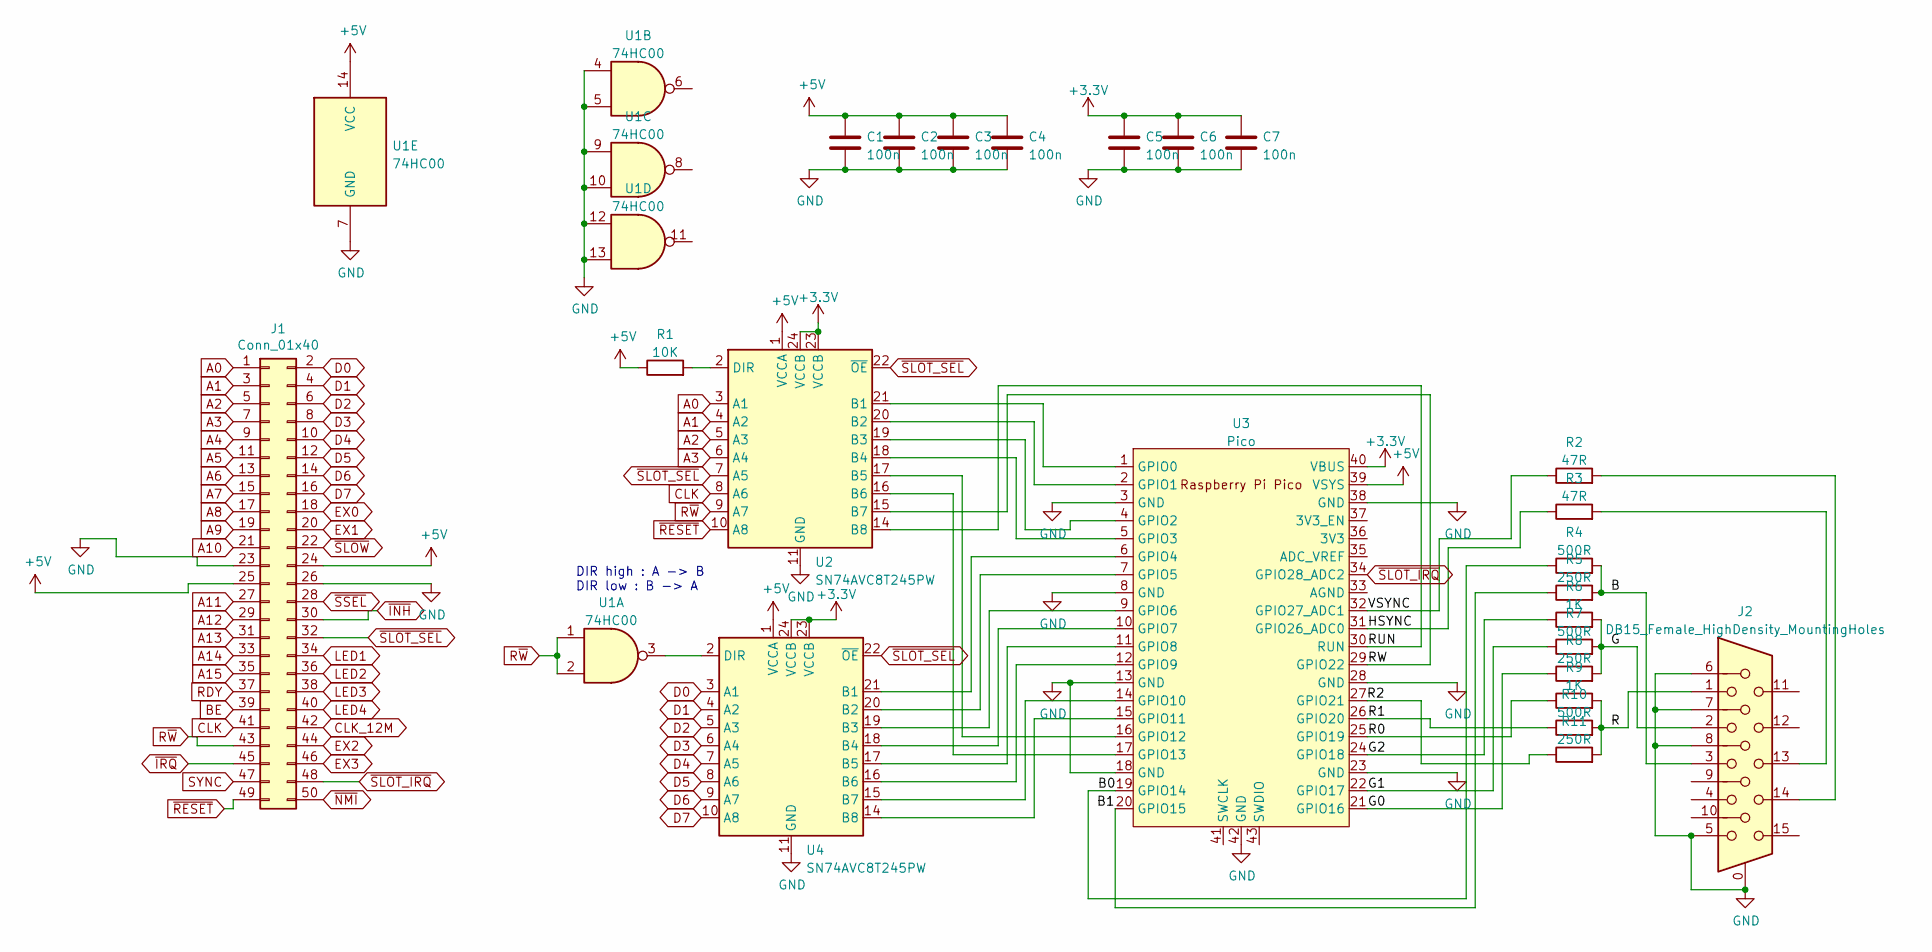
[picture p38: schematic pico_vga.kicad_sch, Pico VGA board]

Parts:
C1, C2, C3, C4, C5, C6, C7: 100n; C_Disc_D5.0mm_W2.5mm_P5.00mm
J1: Conn_01x40; PinHeader_2x25_P2.54mm_Horizontal
J2: DB15_Female_HighDensity_MountingHoles; DSUB-15-HD_Female_Horizontal_P2.29x1.98mm_EdgePinOffset3.03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
R1: 10K; R_Axial_DIN0309_L9.0mm_D3.2mm_P12.70mm_Horizontal
R2, R3: 47R; R_Axial_DIN0309_L9.0mm_D3.2mm_P2.54mm_Vertical
R4, R7, R10: 500R; R_Axial_DIN0309_L9.0mm_D3.2mm_P2.54mm_Vertical
R5, R8, R11: 250R; R_Axial_DIN0309_L9.0mm_D3.2mm_P2.54mm_Vertical
R6, R9: 1K; R_Axial_DIN0309_L9.0mm_D3.2mm_P2.54mm_Vertical
U1: 74HC00
U2, U4: SN74AVC8T245PW; SOP-24_7.5x15.4mm_P1.27mm
U3: Pico; RPi_Pico_SMD_TH

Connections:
+3.3V: C5.1, C6.1, C7.1, U2.23 (VCCB), U2.24 (VCCB), U3.40 (VBUS), U4.23 (VCCB), U4.24 (VCCB)
+5V: C1.1, C2.1, C3.1, C4.1, J1.24, J1.25, R1.1, U1.14 (VCC), U2.1 (VCCA), U3.39 (VSYS), U4.1 (VCCA)
/B: J2.3, R4.2, R5.2
/B0: R4.1, U3.19 (GPIO14)
/B1: R5.1, U3.20 (GPIO15)
/G: J2.2, R6.2, R7.2, R8.2
/G0: R8.1, U3.21 (GPIO16)
/G1: R7.1, U3.22 (GPIO17)
/G2: R6.1, U3.24 (GPIO18)
/HSYNC: R3.1, U3.31 (GPIO26_ADC0)
/R: J2.1, R9.2, R10.2, R11.2
/R0: R9.1, U3.25 (GPIO19)
/R1: R10.1, U3.26 (GPIO20)
/R2: R11.1, U3.27 (GPIO21)
/RUN: U2.14 (B8), U3.30 (RUN)
/RW: U2.15 (B7), U3.29 (GPIO22)
/VSYNC: R2.1, U3.32 (GPIO27_ADC1)
A0: J1.1, U2.3 (A1)
A1: J1.3, U2.4 (A2)
A2: J1.5, U2.5 (A3)
A3: J1.7, U2.6 (A4)
A4: J1.9
A5: J1.11
A6: J1.13
A7: J1.15
A8: J1.17
A9: J1.19
A10: J1.21
A11: J1.27
A12: J1.29
A13: J1.31
A14: J1.33
A15: J1.35
BE: J1.39
CLK: J1.41, U2.8 (A6)
CLK_12M: J1.42
D0: J1.2, U4.3 (A1)
D1: J1.4, U4.4 (A2)
D2: J1.6, U4.5 (A3)
D3: J1.8, U4.6 (A4)
D4: J1.10, U4.7 (A5)
D5: J1.12, U4.8 (A6)
D6: J1.14, U4.9 (A7)
D7: J1.16, U4.10 (A8)
EX0: J1.18
EX1: J1.20
EX2: J1.44
EX3: J1.46
GND: C1.2, C2.2, C3.2, C4.2, C5.2, C6.2, C7.2, J1.23, J1.26, J2.0, J2.5, J2.6, J2.7, J2.8, U1.4, U1.5, U1.7 (GND), U1.9, U1.10, U1.12, U1.13, U2.11 (GND), U2.12 (GND), U2.13 (GND), U3.3 (GND), U3.8 (GND), U3.13 (GND), U3.18 (GND), U3.23 (GND), U3.28 (GND), U3.38 (GND), U3.42 (GND), U4.11 (GND), U4.12 (GND), U4.13 (GND)
LED1: J1.34
LED2: J1.36
LED3: J1.38
LED4: J1.40
unnamed: J2.13, R3.2
unnamed: J2.14, R2.2
unnamed: U2.21 (B1), U3.1 (GPIO0)
unnamed: U2.20 (B2), U3.2 (GPIO1)
unnamed: U2.19 (B3), U3.4 (GPIO2)
unnamed: U2.18 (B4), U3.5 (GPIO3)
unnamed: U2.17 (B5), U3.16 (GPIO12)
unnamed: U2.16 (B6), U3.17 (GPIO13)
unnamed: R1.2, U2.2 (DIR)
unnamed: U3.6 (GPIO4), U4.21 (B1)
unnamed: U3.7 (GPIO5), U4.20 (B2)
unnamed: U3.9 (GPIO6), U4.19 (B3)
unnamed: U3.10 (GPIO7), U4.18 (B4)
unnamed: U3.11 (GPIO8), U4.17 (B5)
unnamed: U3.12 (GPIO9), U4.16 (B6)
unnamed: U3.14 (GPIO10), U4.15 (B7)
unnamed: U3.15 (GPIO11), U4.14 (B8)
unnamed: U1.3, U4.2 (DIR)
RDY: J1.37
R~W: J1.43, U1.1, U1.2, U2.9 (A7)
SYNC: J1.47
~INH: J1.30
~IRQ: J1.45
~NMI: J1.50
~RESET: J1.49, U2.10 (A8)
~SLOT_IRQ: J1.48, U3.34 (GPIO28_ADC2)
~SLOT_SEL: J1.32, U2.7 (A5), U2.22 (~OE), U4.22 (~OE)
~SLOW: J1.22
~SSEL: J1.28

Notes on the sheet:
DIR high : A -> B DIR low : B -> A

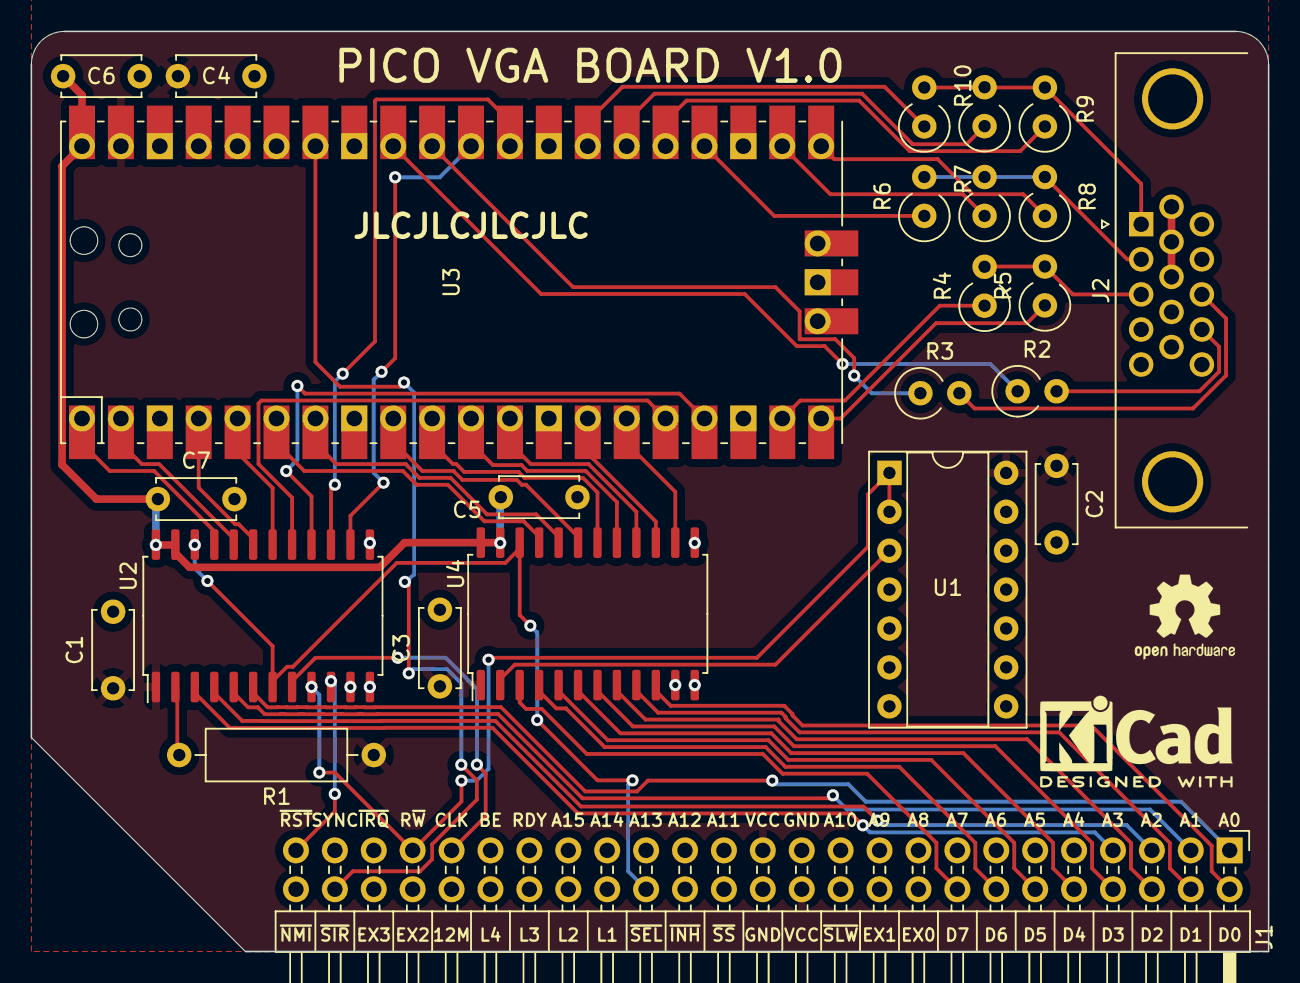
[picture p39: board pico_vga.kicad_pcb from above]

Board: 2 copper layers, 80.8 x 60.1 mm, 24 parts (0 on the bottom side), 53 nets.

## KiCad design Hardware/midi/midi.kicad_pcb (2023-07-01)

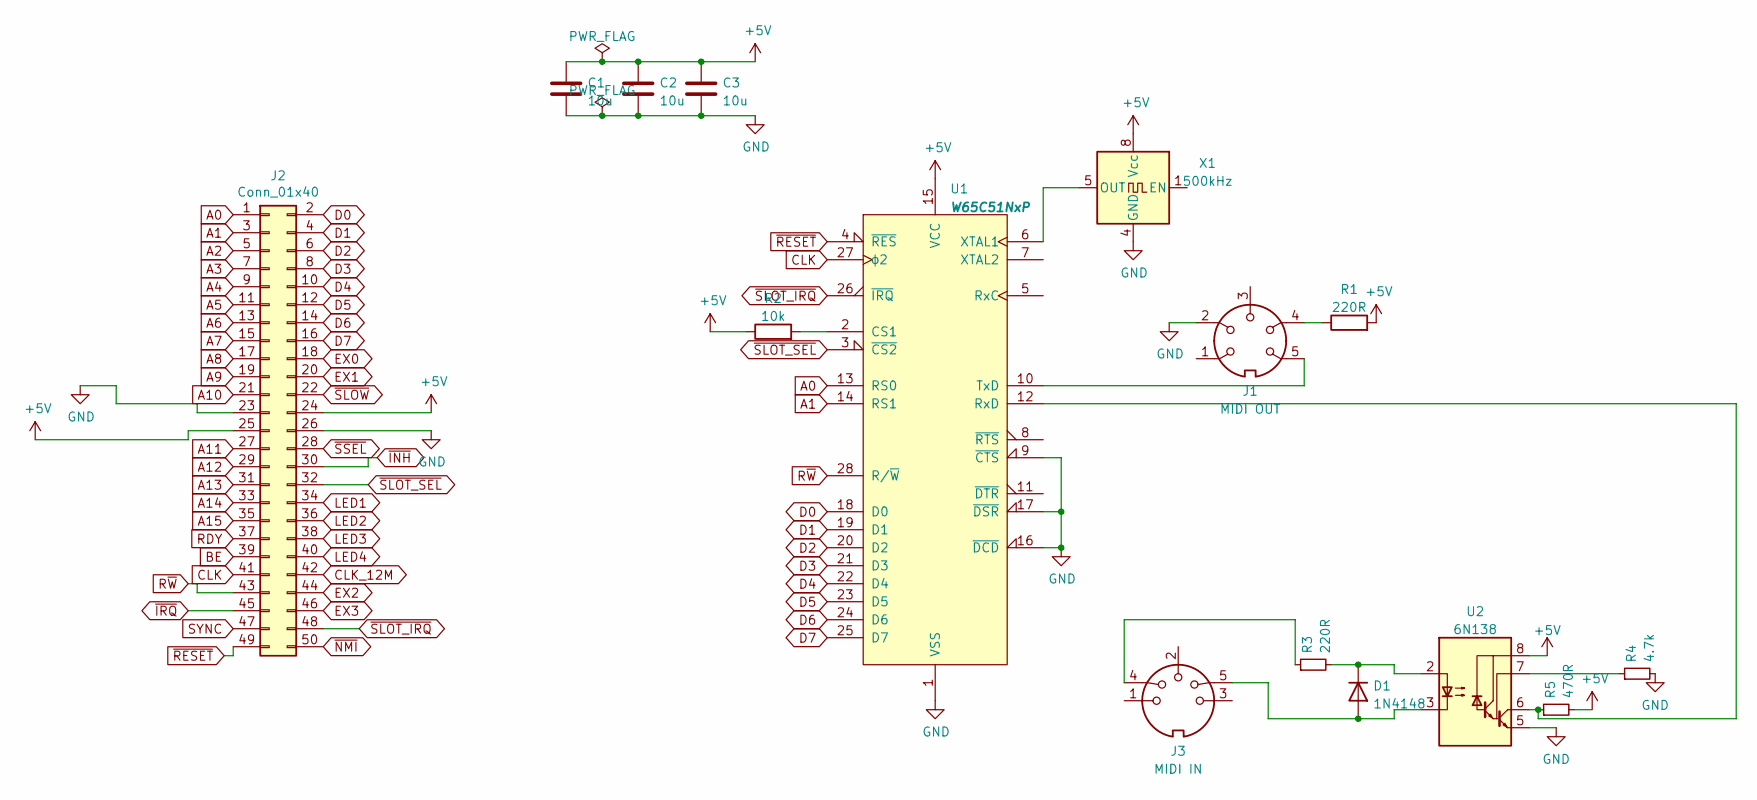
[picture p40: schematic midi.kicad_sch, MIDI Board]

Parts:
C1, C2, C3: 10u; C_Disc_D5.1mm_W3.2mm_P5.00mm
D1: 1N4148; D_DO-35_SOD27_P7.62mm_Horizontal
J1: MIDI OUT; din-5
J2: Conn_01x40; PinHeader_2x25_P2.54mm_Horizontal
J3: MIDI IN; din-5
R1, R3: 220R; R_Axial_DIN0207_L6.3mm_D2.5mm_P10.16mm_Horizontal
R2: 10k; R_Axial_DIN0207_L6.3mm_D2.5mm_P10.16mm_Horizontal
R4: 4.7k; R_Axial_DIN0207_L6.3mm_D2.5mm_P10.16mm_Horizontal
R5: 470R; R_Axial_DIN0207_L6.3mm_D2.5mm_P10.16mm_Horizontal
U1: W65C51NxP; DIP-40_W15.24mm_Socket
U2: 6N138; DIP-8_W7.62mm
X1: 500kHz; Oscillator_DIP-8

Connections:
+5V: C1.1, C2.1, C3.1, J2.24, J2.25, R1.2, R2.1, R5.2, U1.15 (VCC), U2.8 (VCC), X1.8 (Vcc)
A0: J2.1, U1.13 (RS0)
A1: J2.3, U1.14 (RS1)
A2: J2.5
A3: J2.7
A4: J2.9
A5: J2.11
A6: J2.13
A7: J2.15
A8: J2.17
A9: J2.19
A10: J2.21
A11: J2.27
A12: J2.29
A13: J2.31
A14: J2.33
A15: J2.35
BE: J2.39
CLK: J2.41, U1.27 (ϕ2)
CLK_12M: J2.42
D0: J2.2, U1.18 (D0)
D1: J2.4, U1.19 (D1)
D2: J2.6, U1.20 (D2)
D3: J2.8, U1.21 (D3)
D4: J2.10, U1.22 (D4)
D5: J2.12, U1.23 (D5)
D6: J2.14, U1.24 (D6)
D7: J2.16, U1.25 (D7)
EX0: J2.18
EX1: J2.20
EX2: J2.44
EX3: J2.46
GND: C1.2, C2.2, C3.2, J1.2, J2.23, J2.26, R4.2, U1.1 (VSS), U1.9 (~CTS), U1.16 (~DCD), U1.17 (~DSR), U2.5 (GND), X1.4 (GND)
LED1: J2.34
LED2: J2.36
LED3: J2.38
LED4: J2.40
unnamed: D1.1 (K), R3.2, U2.2 (C1)
unnamed: D1.2 (A), J3.5, U2.3 (C2)
unnamed: J1.4, R1.1
unnamed: J1.5, U1.10 (TxD)
unnamed: J3.4, R3.1
unnamed: R2.2, U1.2 (CS1)
unnamed: R4.1, U2.7 (VO1)
unnamed: R5.1, U1.12 (RxD), U2.6 (VO2)
unnamed: U1.6 (XTAL1), X1.5 (OUT)
RDY: J2.37
R~W: J2.43, U1.28 (R/~W)
SYNC: J2.47
~INH: J2.30
~IRQ: J2.45
~NMI: J2.50
~RESET: J2.49, U1.4 (~RES)
~SLOT_IRQ: J2.48, U1.26 (~IRQ)
~SLOT_SEL: J2.32, U1.3 (~CS2)
~SLOW: J2.22
~SSEL: J2.28

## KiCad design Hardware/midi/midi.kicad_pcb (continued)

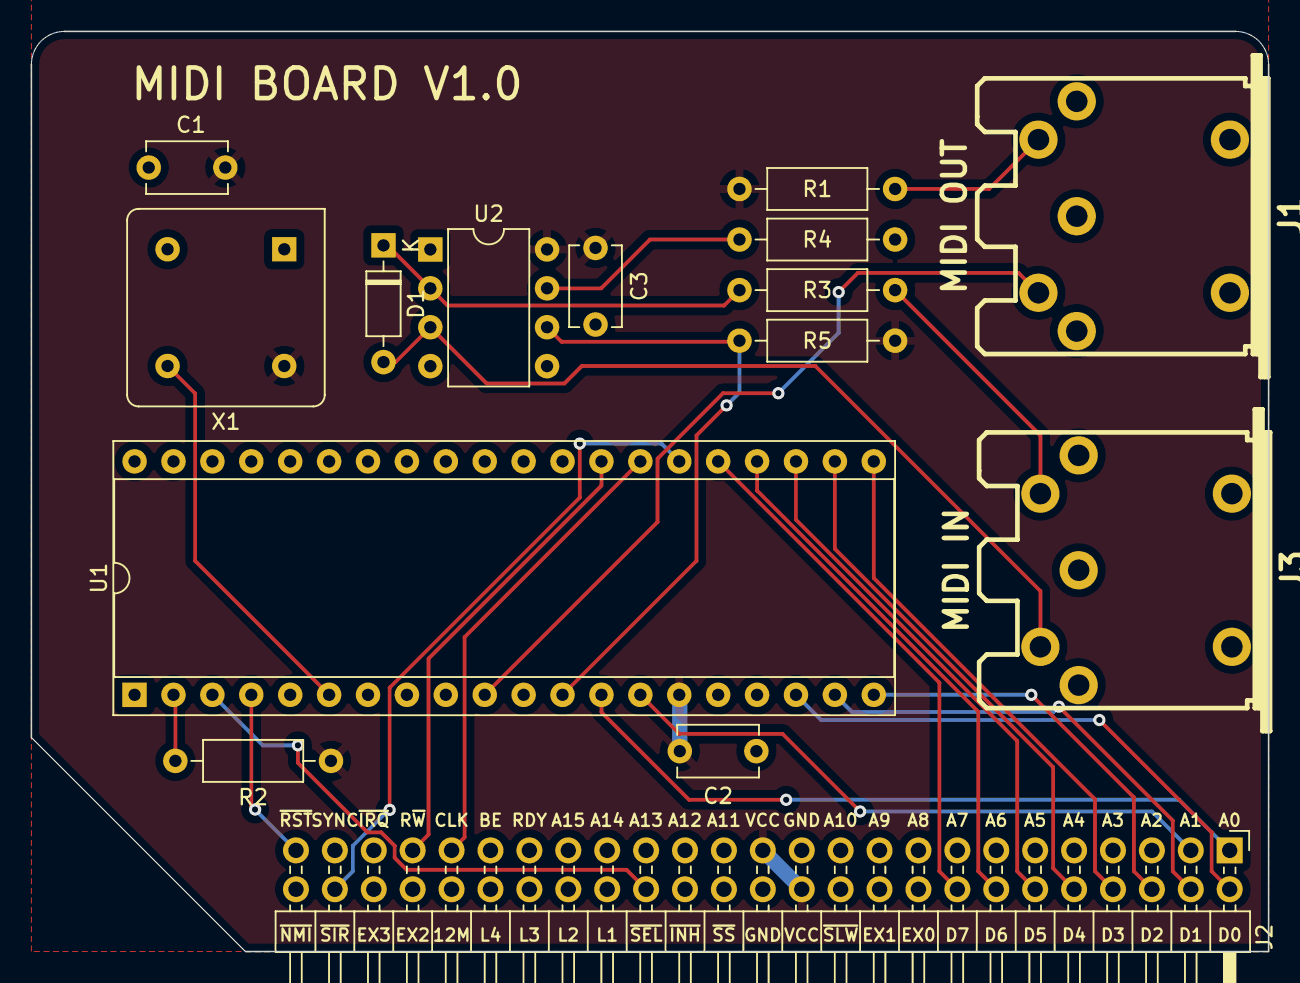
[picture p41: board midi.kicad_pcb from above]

Board: 2 copper layers, 80.8 x 60.1 mm, 15 parts (0 on the bottom side), 26 nets.

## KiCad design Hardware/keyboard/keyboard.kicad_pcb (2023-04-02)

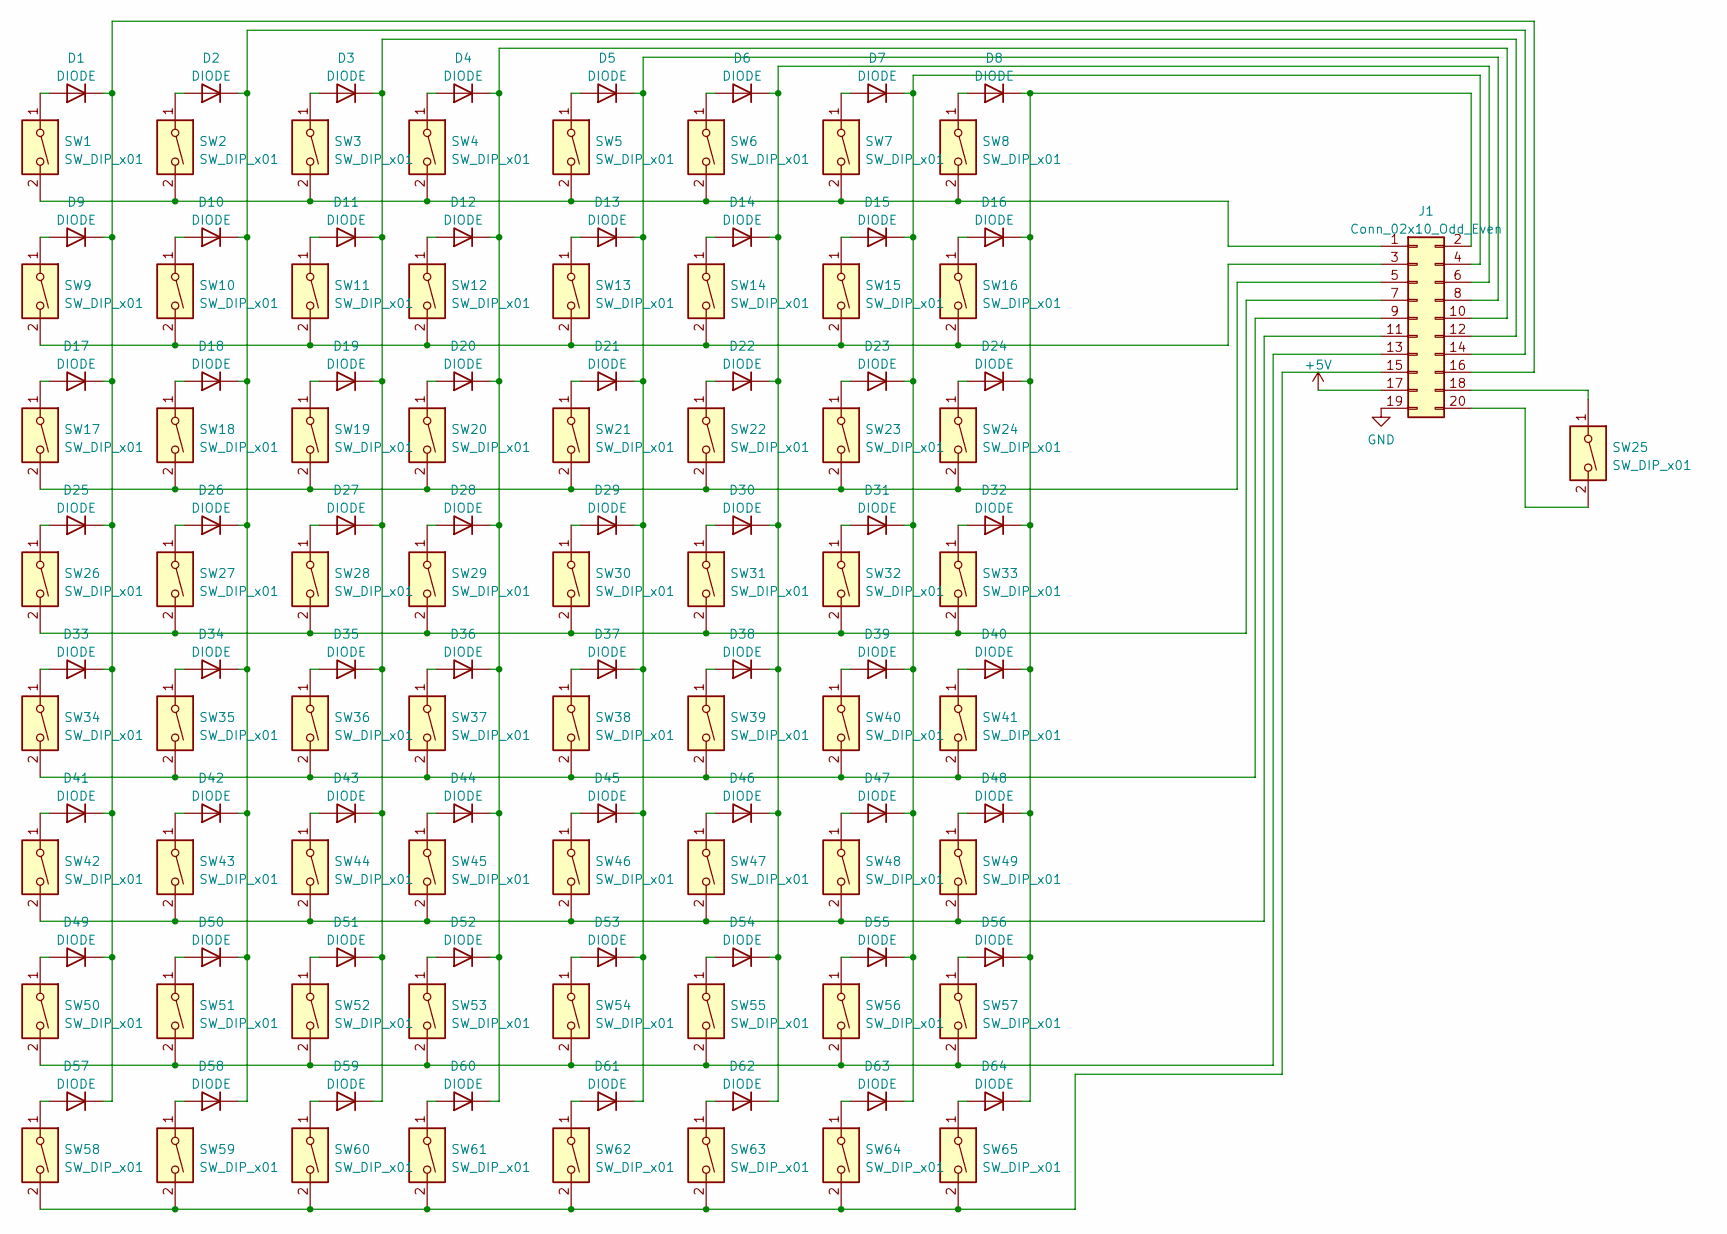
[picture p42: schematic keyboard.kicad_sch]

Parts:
D1, D2, D3, D4, D5, D6, D7, D8, D9, D10, D11, D12, D13, D14, D15, D16, D17, D18, D19, D20, D21, D22, D23, D24, D25, D26, D27, D28, D29, D30, D31, D32, D33, D34, D35, D36, D37, D38, D39, D40, D41, D42, D43, D44, D45, D46, D47, D48, D49, D50, D51, D52, D53, D54, D55, D56, D57, D58, D59, D60, D61, D62, D63, D64: DIODE; D_DO-35_SOD27_P7.62mm_Horizontal
J1: Conn_02x10_Odd_Even; PinHeader_2x11_P2.54mm_Horizontal
SW1, SW2, SW3, SW4, SW5, SW6, SW7, SW8, SW9, SW10, SW11, SW12, SW13, SW14, SW15, SW16, SW17, SW18, SW19, SW20, SW21, SW22, SW23, SW24, SW25, SW26, SW27, SW28, SW29, SW30, SW31, SW32, SW33, SW34, SW35, SW36, SW37, SW38, SW39, SW40, SW41, SW42, SW43, SW44, SW45, SW46, SW47, SW48, SW49, SW50, SW51, SW52, SW53, SW54, SW55, SW56, SW57, SW58, SW59, SW60, SW61, SW62, SW63, SW64, SW65: SW_DIP_x01; SW_Cherry_MX_PCB_1.00u

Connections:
+5V: J1.17
GND: J1.19
unnamed: D1.1 (K), D9.1 (K), D17.1 (K), D25.1 (K), D33.1 (K), D41.1 (K), D49.1 (K), D57.1 (K), J1.16
unnamed: D1.2 (A), SW1.1
unnamed: D2.2 (A), SW2.1
unnamed: D3.1 (K), D11.1 (K), D19.1 (K), D27.1 (K), D35.1 (K), D43.1 (K), D51.1 (K), D59.1 (K), J1.12
unnamed: D3.2 (A), SW3.1
unnamed: D4.1 (K), D12.1 (K), D20.1 (K), D28.1 (K), D36.1 (K), D44.1 (K), D52.1 (K), D60.1 (K), J1.10
unnamed: D4.2 (A), SW4.1
unnamed: D5.1 (K), D13.1 (K), D21.1 (K), D29.1 (K), D37.1 (K), D45.1 (K), D53.1 (K), D61.1 (K), J1.8
unnamed: D5.2 (A), SW5.1
unnamed: D6.1 (K), D14.1 (K), D22.1 (K), D30.1 (K), D38.1 (K), D46.1 (K), D54.1 (K), D62.1 (K), J1.6
unnamed: D6.2 (A), SW6.1
unnamed: D7.1 (K), D15.1 (K), D23.1 (K), D31.1 (K), D39.1 (K), D47.1 (K), D55.1 (K), D63.1 (K), J1.4
unnamed: D7.2 (A), SW7.1
unnamed: D8.1 (K), D16.1 (K), D24.1 (K), D32.1 (K), D40.1 (K), D48.1 (K), D56.1 (K), D64.1 (K), J1.2
unnamed: D8.2 (A), SW8.1
unnamed: D9.2 (A), SW9.1
unnamed: D2.1 (K), D10.1 (K), D18.1 (K), D26.1 (K), D34.1 (K), D42.1 (K), D50.1 (K), D58.1 (K), J1.14
unnamed: D10.2 (A), SW10.1
unnamed: D11.2 (A), SW11.1
unnamed: D12.2 (A), SW12.1
unnamed: D13.2 (A), SW13.1
unnamed: D14.2 (A), SW14.1
unnamed: D15.2 (A), SW15.1
unnamed: D16.2 (A), SW16.1
unnamed: D17.2 (A), SW17.1
unnamed: D18.2 (A), SW18.1
unnamed: D19.2 (A), SW19.1
unnamed: D20.2 (A), SW20.1
unnamed: D21.2 (A), SW21.1
unnamed: D22.2 (A), SW22.1
unnamed: D23.2 (A), SW23.1
unnamed: D24.2 (A), SW24.1
unnamed: D25.2 (A), SW26.1
unnamed: D26.2 (A), SW27.1
unnamed: D27.2 (A), SW28.1
unnamed: D28.2 (A), SW29.1
unnamed: D29.2 (A), SW30.1
unnamed: D30.2 (A), SW31.1
unnamed: D31.2 (A), SW32.1
unnamed: D32.2 (A), SW33.1
unnamed: D33.2 (A), SW34.1
unnamed: D34.2 (A), SW35.1
unnamed: D35.2 (A), SW36.1
unnamed: D36.2 (A), SW37.1
unnamed: D37.2 (A), SW38.1
unnamed: D38.2 (A), SW39.1
unnamed: D39.2 (A), SW40.1
unnamed: D40.2 (A), SW41.1
unnamed: D41.2 (A), SW42.1
unnamed: D42.2 (A), SW43.1
unnamed: D43.2 (A), SW44.1
unnamed: D44.2 (A), SW45.1
unnamed: D45.2 (A), SW46.1
unnamed: D46.2 (A), SW47.1
unnamed: D47.2 (A), SW48.1
unnamed: D48.2 (A), SW49.1
unnamed: D49.2 (A), SW50.1
unnamed: D50.2 (A), SW51.1
unnamed: D51.2 (A), SW52.1
unnamed: D52.2 (A), SW53.1
unnamed: D53.2 (A), SW54.1
unnamed: D54.2 (A), SW55.1
unnamed: D55.2 (A), SW56.1
unnamed: D56.2 (A), SW57.1
unnamed: D57.2 (A), SW58.1
unnamed: D58.2 (A), SW59.1
unnamed: D59.2 (A), SW60.1
unnamed: D60.2 (A), SW61.1
unnamed: D61.2 (A), SW62.1
unnamed: D62.2 (A), SW63.1
unnamed: D63.2 (A), SW64.1
unnamed: D64.2 (A), SW65.1
unnamed: J1.1, SW1.2, SW2.2, SW3.2, SW4.2, SW5.2, SW6.2, SW7.2, SW8.2
unnamed: J1.3, SW9.2, SW10.2, SW11.2, SW12.2, SW13.2, SW14.2, SW15.2, SW16.2
unnamed: J1.5, SW17.2, SW18.2, SW19.2, SW20.2, SW21.2, SW22.2, SW23.2, SW24.2
unnamed: J1.7, SW26.2, SW27.2, SW28.2, SW29.2, SW30.2, SW31.2, SW32.2, SW33.2
unnamed: J1.9, SW34.2, SW35.2, SW36.2, SW37.2, SW38.2, SW39.2, SW40.2, SW41.2
unnamed: J1.11, SW42.2, SW43.2, SW44.2, SW45.2, SW46.2, SW47.2, SW48.2, SW49.2
unnamed: J1.13, SW50.2, SW51.2, SW52.2, SW53.2, SW54.2, SW55.2, SW56.2, SW57.2
unnamed: J1.15, SW58.2, SW59.2, SW60.2, SW61.2, SW62.2, SW63.2, SW64.2, SW65.2
unnamed: J1.18, SW25.1
unnamed: J1.20, SW25.2

Board: 2 copper layers, 130 parts (0 on the bottom side), 82 nets, no tracks yet.

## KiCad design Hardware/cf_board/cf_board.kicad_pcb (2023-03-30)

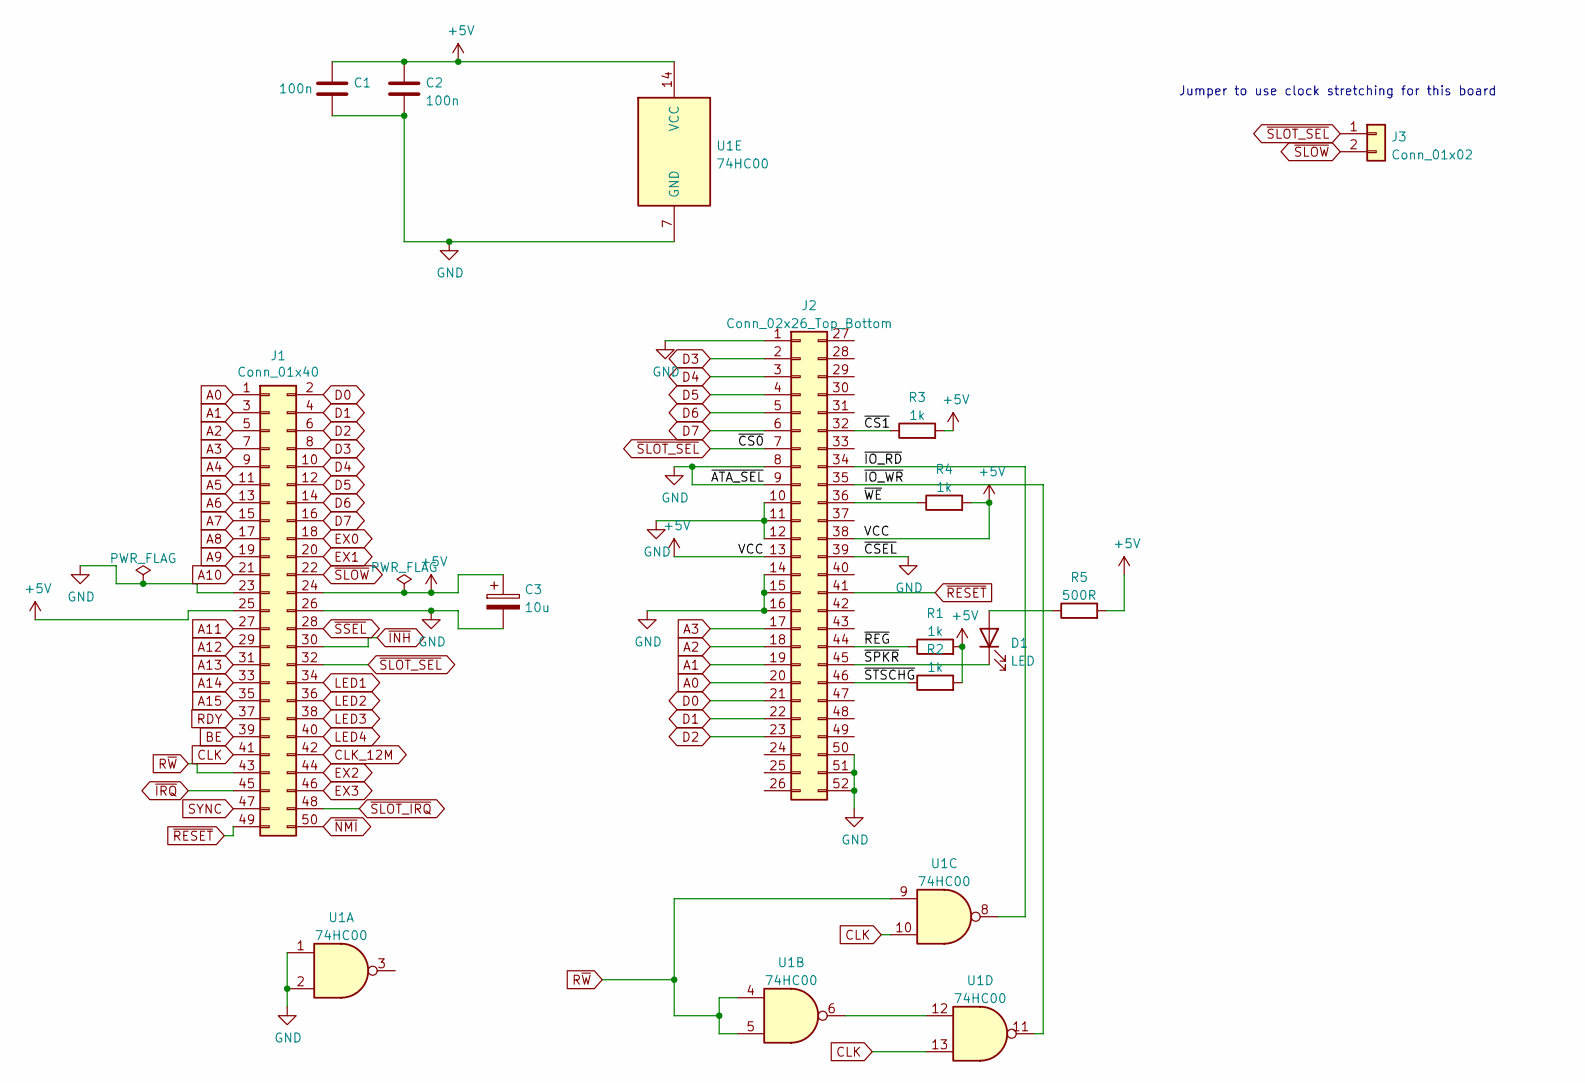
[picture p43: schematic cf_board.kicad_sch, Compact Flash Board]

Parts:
C1, C2: 100n; C_Disc_D5.0mm_W2.5mm_P5.00mm
C3: 10u; CP_Radial_D5.0mm_P2.50mm
D1: LED; LED_D3.0mm
J1: Conn_01x40; PinHeader_2x25_P2.54mm_Horizontal
J2: Conn_02x26_Top_Bottom; SD-SMD_CFH-L3C1LBL01MN0
J3: Conn_01x02; PinHeader_1x02_P2.54mm_Vertical
R1, R2, R3, R4: 1k; R_Axial_DIN0207_L6.3mm_D2.5mm_P10.16mm_Horizontal
R5: 500R; R_Axial_DIN0207_L6.3mm_D2.5mm_P10.16mm_Horizontal
U1: 74HC00; DIP-14_W7.62mm_Socket

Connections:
+5V: C1.1, C2.1, C3.1, J1.24, J1.25, J2.13, J2.38, R1.2, R2.2, R3.2, R4.2, R5.2, U1.14 (VCC)
/~CS1: J2.32, R3.1
/~IO_RD: J2.34, U1.8
/~IO_WR: J2.35, U1.11
/~REG: J2.44, R1.1
/~SPKR: D1.1 (K), J2.45
/~STSCHG: J2.46, R2.1
/~WE: J2.36, R4.1
A0: J1.1, J2.20
A1: J1.3, J2.19
A2: J1.5, J2.18
A3: J1.7, J2.17
A4: J1.9
A5: J1.11
A6: J1.13
A7: J1.15
A8: J1.17
A9: J1.19
A10: J1.21
A11: J1.27
A12: J1.29
A13: J1.31
A14: J1.33
A15: J1.35
BE: J1.39
CLK: J1.41, U1.10, U1.13
CLK_12M: J1.42
D0: J1.2, J2.21
D1: J1.4, J2.22
D2: J1.6, J2.23
D3: J1.8, J2.2
D4: J1.10, J2.3
D5: J1.12, J2.4
D6: J1.14, J2.5
D7: J1.16, J2.6
EX0: J1.18
EX1: J1.20
EX2: J1.44
EX3: J1.46
GND: C1.2, C2.2, C3.2, J1.23, J1.26, J2.1, J2.8, J2.9, J2.10, J2.11, J2.12, J2.14, J2.15, J2.16, J2.39, J2.50, J2.51, J2.52, U1.1, U1.2, U1.7 (GND)
LED1: J1.34
LED2: J1.36
LED3: J1.38
LED4: J1.40
unnamed: D1.2 (A), R5.1
unnamed: U1.6, U1.12
RDY: J1.37
R~W: J1.43, U1.4, U1.5, U1.9
SYNC: J1.47
~INH: J1.30
~IRQ: J1.45
~NMI: J1.50
~RESET: J1.49, J2.41
~SLOT_IRQ: J1.48
~SLOT_SEL: J1.32, J2.7, J3.1
~SLOW: J1.22, J3.2
~SSEL: J1.28

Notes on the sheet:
Jumper to use clock stretching for this board

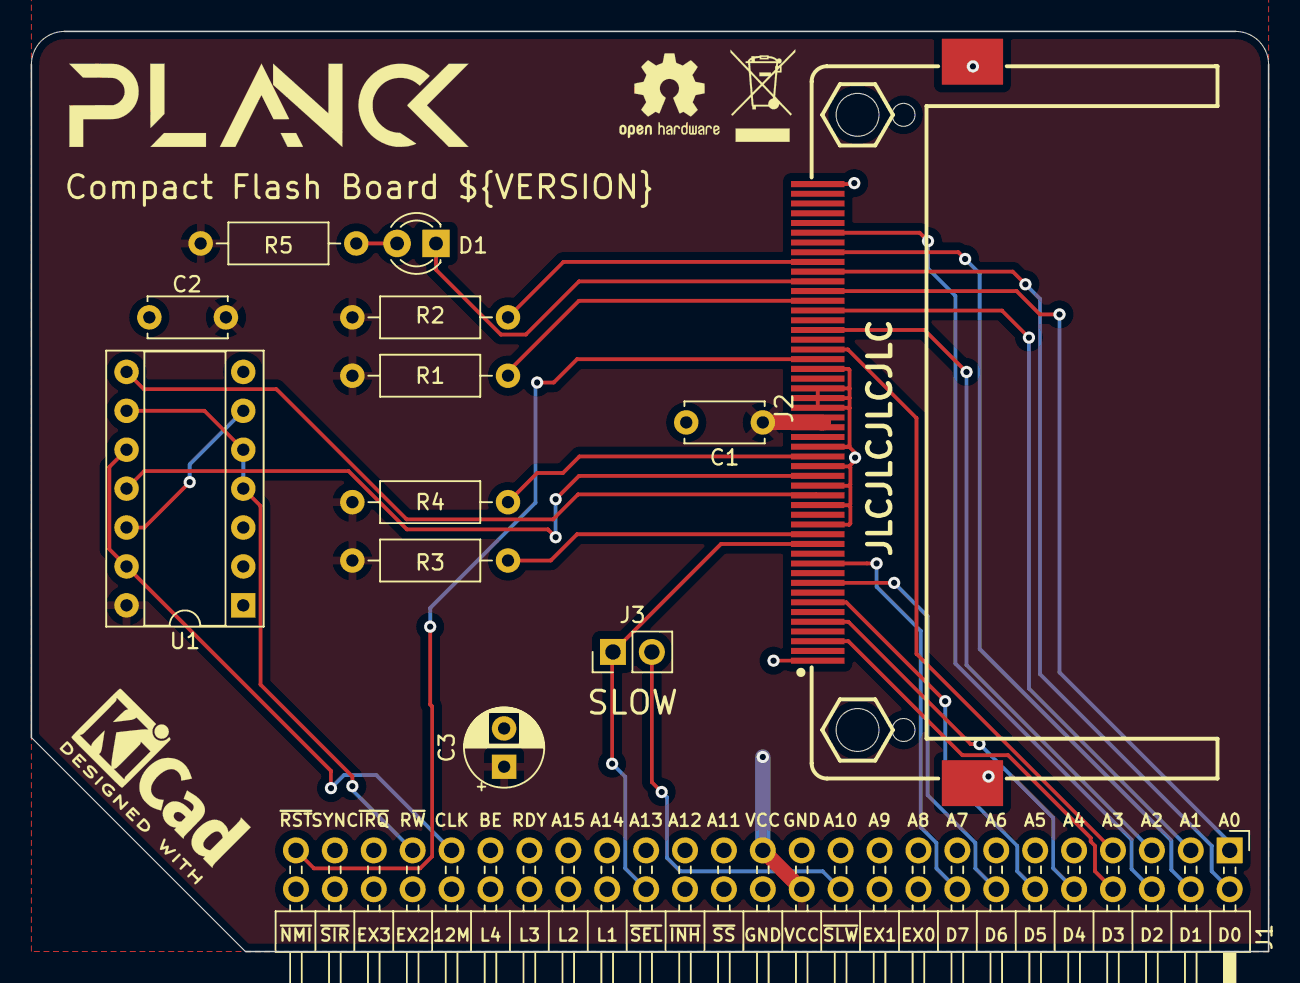
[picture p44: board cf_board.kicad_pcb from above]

Board: 2 copper layers, 80.8 x 60.1 mm, 13 parts (0 on the bottom side), 28 nets.

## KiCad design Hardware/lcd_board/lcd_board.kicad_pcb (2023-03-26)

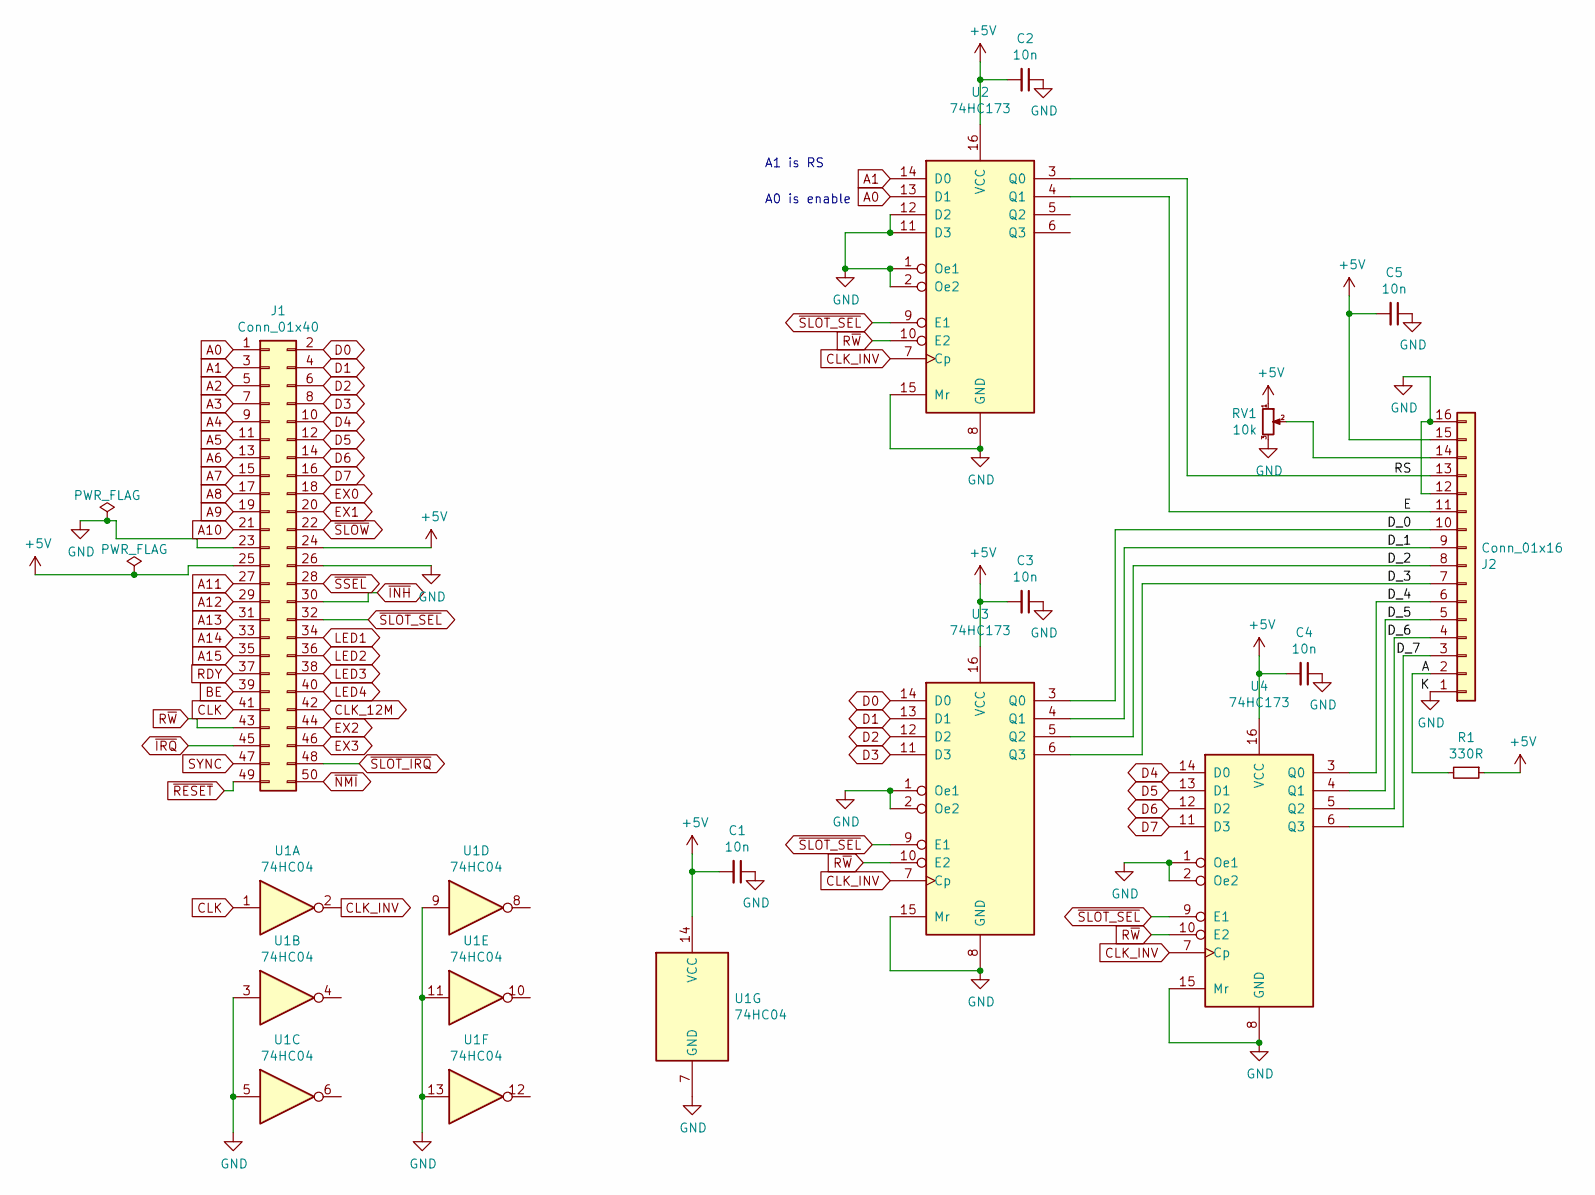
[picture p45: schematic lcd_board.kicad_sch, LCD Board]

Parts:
C1, C2, C3, C4, C5: 10n; C_Disc_D4.3mm_W1.9mm_P5.00mm
J1: Conn_01x40; PinHeader_2x25_P2.54mm_Horizontal
J2: Conn_01x16; PinSocket_1x16_P2.54mm_Horizontal
R1: 330R; R_Axial_DIN0207_L6.3mm_D2.5mm_P10.16mm_Horizontal
RV1: 10k; Potentiometer_Piher_PT-6-V_Vertical
U1: 74HC04; DIP-14_W7.62mm_Socket
U2, U3, U4: 74HC173; DIP-16_W7.62mm_Socket

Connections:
+5V: C1.2, C2.2, C3.2, C4.2, C5.2, J1.24, J1.25, J2.15, R1.1, RV1.1, U1.14 (VCC), U2.16 (VCC), U3.16 (VCC), U4.16 (VCC)
/A: J2.2, R1.2
/D_0: J2.10, U3.3 (Q0)
/D_1: J2.9, U3.4 (Q1)
/D_2: J2.8, U3.5 (Q2)
/D_3: J2.7, U3.6 (Q3)
/D_4: J2.6, U4.3 (Q0)
/D_5: J2.5, U4.4 (Q1)
/D_6: J2.4, U4.5 (Q2)
/D_7: J2.3, U4.6 (Q3)
/E: J2.11, U2.4 (Q1)
/RS: J2.13, U2.3 (Q0)
A0: J1.1, U2.13 (D1)
A1: J1.3, U2.14 (D0)
A2: J1.5
A3: J1.7
A4: J1.9
A5: J1.11
A6: J1.13
A7: J1.15
A8: J1.17
A9: J1.19
A10: J1.21
A11: J1.27
A12: J1.29
A13: J1.31
A14: J1.33
A15: J1.35
BE: J1.39
CLK: J1.41, U1.1
CLK_12M: J1.42
CLK_INV: U1.2, U2.7 (Cp), U3.7 (Cp), U4.7 (Cp)
D0: J1.2, U3.14 (D0)
D1: J1.4, U3.13 (D1)
D2: J1.6, U3.12 (D2)
D3: J1.8, U3.11 (D3)
D4: J1.10, U4.14 (D0)
D5: J1.12, U4.13 (D1)
D6: J1.14, U4.12 (D2)
D7: J1.16, U4.11 (D3)
EX0: J1.18
EX1: J1.20
EX2: J1.44
EX3: J1.46
GND: C1.1, C2.1, C3.1, C4.1, C5.1, J1.23, J1.26, J2.1, J2.12, J2.16, RV1.3, U1.3, U1.5, U1.7 (GND), U1.9, U1.11, U1.13, U2.1 (Oe1), U2.2 (Oe2), U2.8 (GND), U2.11 (D3), U2.12 (D2), U2.15 (Mr), U3.1 (Oe1), U3.2 (Oe2), U3.8 (GND), U3.15 (Mr), U4.1 (Oe1), U4.2 (Oe2), U4.8 (GND), U4.15 (Mr)
LED1: J1.34
LED2: J1.36
LED3: J1.38
LED4: J1.40
unnamed: J2.14, RV1.2
RDY: J1.37
R~W: J1.43, U2.10 (E2), U3.10 (E2), U4.10 (E2)
SYNC: J1.47
~INH: J1.30
~IRQ: J1.45
~NMI: J1.50
~RESET: J1.49
~SLOT_IRQ: J1.48
~SLOT_SEL: J1.32, U2.9 (E1), U3.9 (E1), U4.9 (E1)
~SLOW: J1.22
~SSEL: J1.28

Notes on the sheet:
A0 is enable
A1 is RS


Board: 2 copper layers, 80.8 x 60.1 mm, 13 parts (0 on the bottom side), 28 nets.

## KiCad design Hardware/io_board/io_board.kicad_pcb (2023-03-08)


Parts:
C1, C2, C4: 10n; C_Disc_D4.7mm_W2.5mm_P5.00mm
C3: 100n; C_Disc_D4.7mm_W2.5mm_P5.00mm
D1, D2, D3, D4, D5, D6, D7, D8: LED; LED_D3.0mm_Horizontal_O3.81mm_Z6.0mm_2
J1: Conn_01x40; PinHeader_2x25_P2.54mm_Horizontal
J2: Conn_02x06_Odd_Even; PinHeader_2x06_P2.54mm_Horizontal
J3: Mini-DIN-6; Connector_Mini-DIN_Female_6Pin_2rows
J4: Conn_02x10_Odd_Even; PinHeader_2x10_P2.54mm_Horizontal
J5: Conn_01x04_Male; PinHeader_1x04_P2.54mm_Vertical
J6: Conn_01x06; PinSocket_1x06_P2.54mm_Vertical
R1, R2: 1k; R_Axial_DIN0207_L6.3mm_D2.5mm_P7.62mm_Horizontal
R3, R4: 10k; R_Axial_DIN0207_L6.3mm_D2.5mm_P7.62mm_Horizontal
R5, R6, R7, R8, R9, R10, R11, R12: 470R; R_Axial_DIN0207_L6.3mm_D2.5mm_P7.62mm_Horizontal
U2: W65C22NxP; DIP-40_W15.24mm_Socket
U3: 74LS14; DIP-14_W7.62mm_Socket
U4: 74HC137; DIP-16_W7.62mm_Socket

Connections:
+5V: C1.1, C2.1, C3.1, C4.1, J1.24, J1.25, J2.2, J3.4, J4.8, J4.10, J5.1, J6.5, R1.1, R2.1, R3.1, R4.1, U2.20 (VCC), U3.14 (VCC), U4.16 (VCC)
/CA1: J2.6, U2.40 (CA1)
/CA2: J2.4, U2.39 (CA2)
/PA0: D1.2 (A), J2.11, U2.2 (PA0)
/PA1: D2.2 (A), J2.9, U2.3 (PA1)
/PA2: D3.2 (A), J2.7, U2.4 (PA2)
/PA3: D4.2 (A), J2.5, U2.5 (PA3)
/PA4: D5.2 (A), J2.3, U2.6 (PA4)
/PA5: D6.2 (A), J2.1, U2.7 (PA5)
/PA6: D7.2 (A), J2.12, U2.8 (PA6)
/PA7: D8.2 (A), J2.10, U2.9 (PA7)
/SS1: J4.20, J6.1, U4.14 (~Y1)
/SS2: J4.18, U4.13 (~Y2)
/SS3: J4.17, U4.12 (~Y3)
/SS4: J4.15, U4.11 (~Y4)
/SS5: J4.14, U4.10 (~Y5)
/SS6: J4.12, U4.9 (~Y6)
/SS7: J4.11, U4.7 (~Y7)
A0: J1.1, U2.38 (RS0)
A1: J1.3, U2.37 (RS1)
A2: J1.5, U2.36 (RS2)
A3: J1.7, U2.35 (RS3)
A4: J1.9
A5: J1.11
A6: J1.13
A7: J1.15
A8: J1.17
A9: J1.19
A10: J1.21
A11: J1.27
A12: J1.29
A13: J1.31
A14: J1.33
A15: J1.35
BE: J1.39
CLK: J1.41
CLK_12M: J1.42, U2.25 (ϕ2)
D0: J1.2, U2.33 (D0)
D1: J1.4, U2.32 (D1)
D2: J1.6, U2.31 (D2)
D3: J1.8, U2.30 (D3)
D4: J1.10, U2.29 (D4)
D5: J1.12, U2.28 (D5)
D6: J1.14, U2.27 (D6)
D7: J1.16, U2.26 (D7)
EX0: J1.18
EX1: J1.20
EX2: J1.44
EX3: J1.46
GND: C1.2, C2.2, C3.2, C4.2, J1.23, J1.26, J2.8, J3.3, J4.2, J4.4, J4.6, J4.13, J4.16, J4.19, J5.2, J6.6, R5.2, R6.2, R7.2, R8.2, R9.2, R10.2, R11.2, R12.2, U2.1 (VSS), U3.5, U3.7 (GND), U3.9, U4.5 (~E1), U4.8 (GND)
LED1: J1.34, U2.10 (PB0), U4.1 (A0)
LED2: J1.36, U2.11 (PB1), U4.2 (A1)
LED3: J1.38, U2.12 (PB2), U4.3 (A2)
LED4: J1.40, J4.3, J6.2, U2.13 (PB3)
MISO: J4.7, J6.4, U2.14 (PB4)
MOSI: J4.5, J6.3, U2.15 (PB5)
unnamed: D1.1 (K), R5.1
unnamed: D2.1 (K), R6.1
unnamed: D3.1 (K), R7.1
unnamed: D4.1 (K), R8.1
unnamed: D5.1 (K), R9.1
unnamed: D6.1 (K), R10.1
unnamed: D7.1 (K), R11.1
unnamed: D8.1 (K), R12.1
unnamed: J3.5, J5.4, R1.2, U3.1
unnamed: R3.2, U2.24 (CS1)
unnamed: R4.2, U4.6 (E2)
unnamed: U2.17 (PB7), U3.10
unnamed: U2.19 (CB2), U3.4
unnamed: U3.2, U3.3
unnamed: U3.11, U3.12
PS2_DATA: J3.1, J5.3, R2.2, U3.13
RDY: J1.37
R~W: J1.43, U2.22 (R/~W)
SYNC: J1.47
~CONF: J4.1, U2.16 (PB6), U4.4 (~LE)
~INH: J1.30
~IRQ: J1.45
~NMI: J1.50
~RESET: J1.49, U2.34 (~RES)
~SINT: J4.9, U2.18 (CB1)
~SLOT_IRQ: J1.48, U2.21 (~IRQ)
~SLOT_SEL: J1.32, U2.23 (~CS2)
~SLOW: J1.22
~SSEL: J1.28


Board: 2 copper layers, 80.8 x 60.1 mm, 33 parts (1 on the bottom side), 60 nets.

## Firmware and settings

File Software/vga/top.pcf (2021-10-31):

set_io HSYNC 48
set_io VSYNC 3
set_io CLK_12M 20
set_io CLK_CPU 21
set_io RW 45
set_io DIR 47

set_io REG[0] 36
set_io REG[1] 42
set_io REG[2] 38



set_io DATA[0] 43
set_io DATA[1] 34
set_io DATA[2] 37
set_io DATA[3] 31
set_io DATA[4] 28
set_io DATA[5] 32
set_io DATA[6] 27
set_io DATA[7] 26

#set_io DO 47

#set_io CLK_25M 25
set_io EN 23
#set_io OE 21

set_io red[2] 13
set_io red[1] 19
set_io red[0] 18
set_io green[2] 11
set_io green[1] 9
set_io green[0] 6
set_io blue[1] 44
set_io blue[0] 4

set_io -nowarn led[0]	41
set_io -nowarn led[1] 39
set_io -nowarn led[2]	40

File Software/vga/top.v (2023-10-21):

//------------------------------------------------------------------
//-- Hello world example
//-- Turn on all the leds
//-- This example has been tested on the following boards:
//--   * Lattice icestick
//--   * Icezum alhambra (https://github.com/FPGAwars/icezum)
//------------------------------------------------------------------



module vga (
    output VSYNC,
    output HSYNC,
    //output OE,
    output reg [2:0] red,
    output reg [2:0] green,
    output reg [1:0] blue,
    output reg [2:0] led,
    output DIR,
    input CLK_12M,
    input CLK_CPU,
    input RW,
    input EN,
    input [2:0] REG,
    input [7:0] DATA
);
    //assign OE = 1;
// Input                   Input/output
// OE      DIR             An      Bn
// L       L               A = B   input
// L       H               input   B = A
// H       X               Z       Z
    // DIR only goes low when reading and enabled
    assign DIR = 1; //(EN | ~RW);

    `define CTRL_REG 3'd0       // Formatted as follows |INCR_NEG|INCR_4|INCR_3|INCR_2|INCR_1|INCR_0|MODE_1|MODE_0|  default to LORES
    `define ADDR_LOW_REG 3'd1   // also contains the increment ||||ADDR4|ADDR_3|ADDR_2|ADDR_1|ADDR_0|
    `define ADDR_HIGH_REG 3'd2
    `define DATA_REG 3'd3
    `define IEN_REG 3'd4    // formatted as follows |VSYNC| | | | | | |HSYNC|
    `define INTR_REG 3'd5   // formatted as follows |VSYNC| | | | | | |HSYNC|
    `define HSCROLL_REG 3'd6    // Scrolls one column in character mode and one pixel in pixel mode - negative is left, positive is right
    `define VSCROLL_REG 3'd7    // Scrolls one line in character mode and one pixel in pixel mode - negative is down, positive is up

    `define SAVE_STATE_INIT 2'd0
    `define SAVE_STATE_SAVE 2'd1
    `define SAVE_STATE_INCREMENT 2'd2
    `define SAVE_STATE_END 2'd3

    `define READ_STATE_INIT 2'd0
    `define READ_STATE_READ 2'd1
    `define READ_STATE_INCREMENT 2'd2
    `define READ_STATE_WAIT 2'd3

    `define MODE_LORES 2'd0;
    `define MODE_HIRES 2'd1;

    localparam H_RES_FULL = 799;
    localparam V_RES_FULL = 524;
    localparam H_RES = 640;
    localparam V_RES = 480;
    localparam V_CHAR_HIRES = 60;
    localparam H_CHAR_HIRES = 80;
    localparam V_CHAR_LORES = 30;
    localparam H_CHAR_LORES = 40;

    localparam RAM_SIZE = 14'h1900;// + 'h400;
    localparam SCREEN_CHARS = 'h1D4B;

    reg [1:0]   mode;
    reg [7:0]   ien_reg;
    reg [7:0]   intr_reg;
    reg [3:0]   increment_reg;
    reg         increment_neg;
    reg [7:0]   hscroll_reg;
    reg [7:0]   vscroll_reg;
    reg [13:0]  address_reg;
    wire [13:0]  char_address_reg = (address_reg >= RAM_SIZE) ? (address_reg - RAM_SIZE) : 14'h0;

    wire [7:0] increment = (increment_reg == 0) ? 0 : ((increment_reg <= 8) ? (1 << (increment_reg-1)) : 
    ((increment_reg == 9) ? 3 : 
    ((increment_reg == 10) ? 10 : 
    ((increment_reg == 11) ? H_CHAR_LORES : 
    ((increment_reg == 12) ? H_CHAR_HIRES : 
    ((increment_reg == 13) ? H_CHAR_HIRES*2 : 
    ((increment_reg == 14) ? H_CHAR_LORES*3 : H_CHAR_HIRES*3
    )))))));


   //assign DATA = (!EN && RW) ? data_out : 8'bzzzzzzzz;

    reg [7:0] data_out;

    parameter CHAR_INIT_FILE = "char_data.mem";
    parameter MEM_INIT_FILE = "start_data.mem";

    reg [7:0] character_rom['h400-1:0];
    //reg [7:0] character_ram['h400-1:0];
    reg [7:0] fb0[RAM_SIZE-1:0];

    reg [13:0] move_pos;
    reg [7:0] move_tmp;
    reg [7:0] do_scroll;
    reg move_state;

    reg [7:0] bgcolor;
    reg [7:0] fgcolor;

    reg RESET;

    integer i;


    initial begin
        RESET <= 1'b1;
        // address_reg <= 0;

        // for (i = 0; i < RAM_SIZE; i = i + 1) begin
        //     fb0[i] <= 8'h20;
        // end
        if (CHAR_INIT_FILE != "") begin
            $readmemh(CHAR_INIT_FILE, character_rom);

        end
        if (MEM_INIT_FILE != "") begin
            $readmemh(MEM_INIT_FILE, fb0);

        end
    end

    initial begin
        CLK_PIX <= 1'b0;
        RESET <= 1'b0;
        move_pos <= 8'h0;
        move_state <= 1'b0;
        //save_data <= 1'b0;
        address_reg <= 14'd0;
        show_cursor <= 1'd0;
        cursor_counter <= 0;
        char_write <= 1'b1;
        fgcolor <= 8'hE0;
        bgcolor <= 8'h00;
        led <= 3'b111;
        do_scroll <= 1'b0;
        save_state <= `SAVE_STATE_INIT;
        //read_state <= `READ_STATE_INIT;
        //read_data <= 1'b0;
        //read_reg <= 3'd0;
        //read_reg <= `CTRL_REG;
        mode <= 1;
        increment_reg <= 1;
        increment_neg <= 0;
        data_out <= 8'h41;
        vscroll_reg <= 0;
        command_buf_r_ptr <= 0;
        command_buf_w_ptr <= 0;
        get_command <= 0;
        // next_fb0_char = 0;
        // second_fb0_char = 0;
        // fb0_char = 0;
        // cur_char = 0;
        //char_data_line = 0;
    end

    wire CLK;

    reg [1:0] save_state;

    wire enabled = ~EN;
    wire write = ~RW;

    wire CLK_FAST;
    reg CLK_PIX;
    wire locked;

    pll mypll(.clock_in(CLK_12M), .clock_out(CLK_FAST), .locked(locked), .reset(~RESET));
    ////////
    // make a simple blink circuit
    ////////

    // keep track of time and location in blink_pattern
    reg fast_counter = 1'b0;


    wire DE;
    wire [9:0] XPOS;
    wire [9:0] YPOS;

    reg [7:0] cursor_counter;
    reg show_cursor;

    // CLK_PIX is CLK_FAST divided by 8
    always @(posedge CLK_FAST) begin
        fast_counter <= ~fast_counter;
    end


    always @(posedge fast_counter) begin
        CLK_PIX <= ~CLK_PIX;
    end

    // Set up VGA timing
    display_timings timings (.vsync(VSYNC), .hsync(HSYNC), .clk_pix(CLK_PIX), .de(DE), .sx(XPOS), .sy(YPOS), .rst(RESET));

    // hardware cursor
    always @(posedge VSYNC) begin
        if (char_write == 1'b0) begin
            cursor_stopped <= 0;
            cursor_counter <= cursor_counter + 1;
            if  (cursor_counter == 0) begin
                show_cursor <= ~show_cursor;
            end
        end else begin
            // Show cursor when a character was recently written
            cursor_counter <= 1;
            show_cursor <= 1;
            cursor_stopped <= 1;
        end
    end
    

    // TRY WITH DOUBLE BUFFER INSTEAD OF FIFO
    // Maybe with SPRAM

    // Now it is true that for the ice40 BRAM there needs to be two clock cycles between setting the address and reading the byte, but we can already set the new address in the next cycle, allowing us to read a byte every clock cycle once we set the initial address. 
    // https://fpga.michelanders.nl/2020/02/ice40-bram-spram-access-need-for-speed.html

    reg [2:0] tmp_command;
    reg [7:0] tmp_data;
    reg [2:0] command_reg;
    reg [7:0] command_data;

    reg [10:0] command_buffer[1 << 10];
    reg [10:0] command;
    reg [9:0] command_buf_r_ptr;
    reg [9:0] command_buf_w_ptr;

    reg [2:0] read_reg;

    reg [3:0] get_command;
    reg [3:0] save_data;
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

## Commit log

2020-12-30 Clean up schematics and add pdfs
    [backplane.sch, io_board.sch, proc_board.sch]
2020-12-31 Each slot has an individual interrupt line, to prevent two cards using the same interrupt line.
    [backplane.kicad_pcb, backplane.sch, io_board.sch]
2020-12-31 Start of serial board
    [proc_board.kicad_pcb, proc_board.sch]
2020-12-31 remove this board for now
    [proc_board.kicad_pcb, proc_board.sch]
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2020-12-31 USB serial adapter socket
    [serial_board.kicad_pcb, serial_board.sch]
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2020-12-31 Space pins for better legibility
    [planck_board.sch]
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2020-12-31 Add resistor between output of NMI MAX811 and NMI line to enable NMI to be controlled from the bus
    [backplane.kicad_pcb, backplane.sch]
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2021-01-01 Add LEDs to IO board
    [io_board.kicad_pcb, io_board.sch]
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2021-01-01 Add gerbers to CPU board
    [proc_board-B_Cu.gbr, proc_board-B_Mask.gbr, proc_board-B_Paste.gbr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]
2021-01-01 Update io board 3D view
    [io_board.sch]
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2021-01-08 Add clock stretching with counter and slow clock request from peripherals.
    [backplane.kicad_pcb, backplane.sch, planck_board.sch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]
2021-01-09 each slot gets it's own slow signal
    [backplane.kicad_pcb, backplane.sch]
2021-01-12 Many updates. SLOW signal is now shared amongst all slots, so their output has to be open drain.
    [backplane.kicad_pcb, backplane.sch, clock.sch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]
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2021-01-14 update CPU board address decoding with a 16V8
    [proc_board-B_Cu.gbr, proc_board-B_Mask.gbr, proc_board-B_Paste.gbr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]
2021-01-14 Add IRQ signal for Slot 5
    [backplane-B_Cu.gbr, backplane-B_Mask.gbr, backplane-B_Paste.gbr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]
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2021-01-14 update with proper pin holes
    [planck_board.kicad_pcb]
2021-01-15 redo gerbers before ordering prototype boards
    [backplane-B_Cu.gbr, backplane-B_Mask.gbr, backplane-B_Paste.gbr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]
2021-02-22 [WIP] add 74HS14 schmitt trigger inverter to PS/2 data and clock signals
    [io_board.kicad_pcb, io_board.sch]
2021-02-22 Add RW signal to 16V8 inputs. Add diode and pullup resistor to SLOW output signal to make it open collector so that it can be wire ored with the SLOW signal coming from other boards.
    [proc_board.sch]
2021-02-22 Add pullup on CS1 and move cts line to RTS of 6551
    [serial_board.kicad_pcb, serial_board.sch]
2021-02-22 [WIP] start of OPL2 sound card
    [opl2_board.kicad_pcb, opl2_board.sch]
2021-02-22 Update processor board according to schematic
    [proc_board.kicad_pcb, proc_board.sch]
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2021-02-28 Backplane provides diode and pullups for SLOW signal
    [backplane.kicad_pcb, backplane.sch, opl2_board.kicad_pcb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]
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2021-03-01 update with pin numbers on silkscreen
    [planck_board.kicad_pcb]
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2021-03-03 small fixes on the hardware
    [backplane.kicad_pcb, backplane.sch, io_board.kicad_pcb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]
2021-03-04 Add / update gerbers
    [backplane-B_Cu.gbr, backplane-B_Mask.gbr, backplane-B_Paste.gbr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]
2021-03-04 add readme to test code + update code
    [planck.cfg]
2021-03-08 [WIP] add backplane computer
    [clock.sch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]
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2021-03-09 Fix missing signals
    [cpu_backplane-B_Cu.gbr, cpu_backplane-B_Mask.gbr, cpu_backplane-B_Paste.gbr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]
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2021-08-29 Finishing CPU backplane with through hole components
    [cpu_backplane-B_Cu.gbr, cpu_backplane-B_Mask.gbr, cpu_backplane-B_Paste.gbr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]
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2021-08-30 update schematic and gerbers
    [cpu_backplane-B_Cu.gbr, cpu_backplane-B_Mask.gbr, cpu_backplane-B_Paste.gbr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]
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2021-08-30 Update serial board with through hole components
    [serial_board.kicad_pcb, serial_board.sch]
2021-08-30 Make IO board through hole
    [io_board-B_Cu.gbr, io_board-B_Mask.gbr, io_board-B_Paste.gbr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]
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2021-08-30 Through hole components for processor board
    [proc_board-B_Cu.gbr, proc_board-B_Mask.gbr, proc_board-B_Paste.gbr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]
2021-08-30 update gerbers for serial board
    [serial_board-B_Cu.gbr, serial_board-B_Mask.gbr, serial_board-B_Paste.gbr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]
2021-08-30 Add ram board gerbers
    [ram_board-B_Cu.gbr, ram_board-B_Mask.gbr, ram_board-B_Paste.gbr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]
2021-08-30 LCD board with through hole components
    [lcd_board-B_Cu.gbr, lcd_board-B_Mask.gbr, lcd_board-B_Paste.gbr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]
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2021-08-31 Through hole components for OPL2 board
    [opl2_board-B_Cu.gbr, opl2_board-B_Mask.gbr, opl2_board-B_Paste.gbr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]
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2021-08-31 Use regular DIP socket
    [cpu_backplane.kicad_pcb]
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2021-08-31 final update for through hole conversion
    [io_board-B_Cu.gbr, io_board-B_Mask.gbr, io_board-B_Paste.gbr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]
2021-09-21 replace resistors with bigger ones + fix diodes
    [cpu_backplane-B_Cu.gbr, cpu_backplane-B_Mask.gbr, cpu_backplane-B_Paste.gbr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]
2021-09-21 bigger resistors on OPL2 board
    [opl2_board-B_Cu.gbr, opl2_board-B_Mask.gbr, opl2_board-B_Paste.gbr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]
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2021-09-22 don't remember what I did there and diffs are useless :/
    [opl2_board.kicad_pcb]
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2021-10-15 Fix LED orientation + move resistor under socket
    [io_board-B_Cu.gbr, io_board-B_Mask.gbr, io_board-B_Paste.gbr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]
2021-10-15 cosmetic fixes to backplane
    [cpu_backplane-B_Cu.gbr, cpu_backplane-B_Mask.gbr, cpu_backplane-B_Paste.gbr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]
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2021-10-31 update reset and NMI circuits to through hole DS1813
    [cpu_backplane-B_Cu.gbr, cpu_backplane-B_Mask.gbr, cpu_backplane-B_Paste.gbr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]
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2022-06-02 Add BOM for main board and IO board
    [BOM.csv]
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2022-08-19 fix io board led words + add break on ctrl-c
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2023-02-10 update docs + delete old backplane + rename cpu_backplane to mainboard.
    [BOM.csv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]
2023-02-11 Add job for LCD board + update to kicad 6
    [lcd_board.kicad_pcb, lcd_board.kicad_sch, lcd_board.sch]
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2023-02-11 Fix DRC
    [opl2_board.kicad_pcb]
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2023-02-11 Fix lcd erc + update mainboard memory map.
    [lcd_board.kicad_pcb]
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2023-03-12 CF card works as block storage for forth
    [cf_board.kicad_pcb, cf_board.kicad_sch]
2023-03-12 Add assembler + fix reading data from CF card
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2023-03-25 Fix mainboard power + add A13 and A14 to RAM/ROM address decoding.
    [mainboard.kicad_pcb, mainboard.kicad_sch]
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2023-03-27 Add new post + set CF board to prod
    [cf_board.kicad_sch]
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2023-03-30 move cf socket so that it is easier to extract
    [cf_board.kicad_pcb]
2023-03-30 fix ERC
    [cf_board.kicad_pcb]
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2023-07-30 Add Pico VGA board + update midi board
    [pico_vga-B_Cu.gbr, pico_vga-B_Mask.gbr, pico_vga-B_Paste.gbr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]
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2023-10-21 fix RAM board ERC and DRC
    [ram_board.kicad_pcb, ram_board.kicad_sch]
2023-10-21 Fix mainboard DRC
    [mainboard.kicad_pcb, mainboard.kicad_sch]
2023-10-23 Can load intel hex files + jump to arbitrary address
    [mainboard.kicad_pcb, ram_board.kicad_pcb]
2023-10-24 Update docs + add PS2 and LCD code back in.
    [memory.cfg]

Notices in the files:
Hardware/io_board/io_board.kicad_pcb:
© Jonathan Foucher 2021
